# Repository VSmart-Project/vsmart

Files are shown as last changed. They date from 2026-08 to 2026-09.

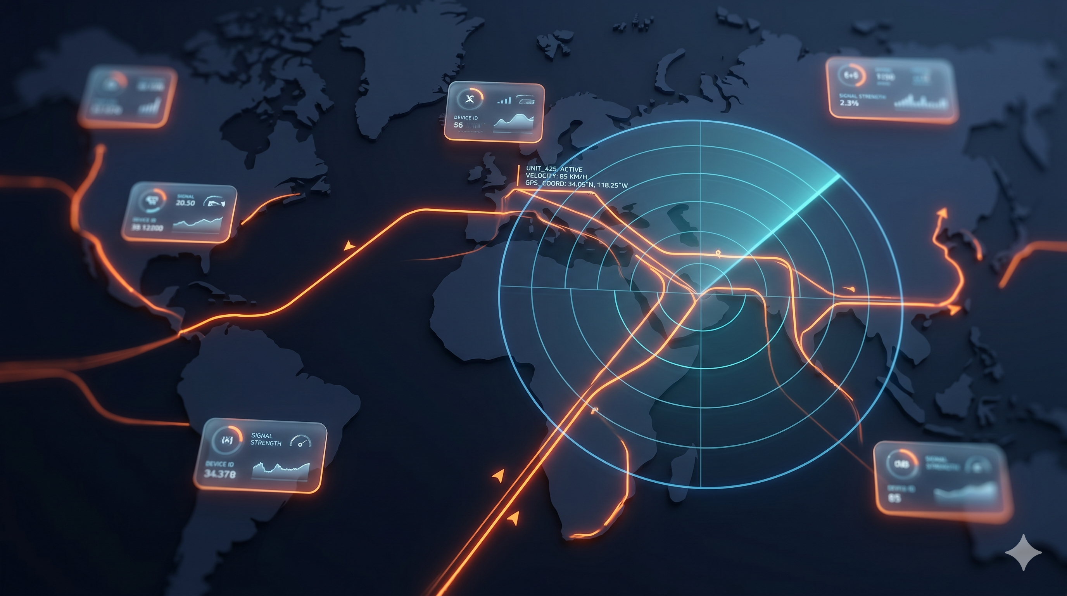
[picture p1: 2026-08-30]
vsmart-mobile/assets/background.png

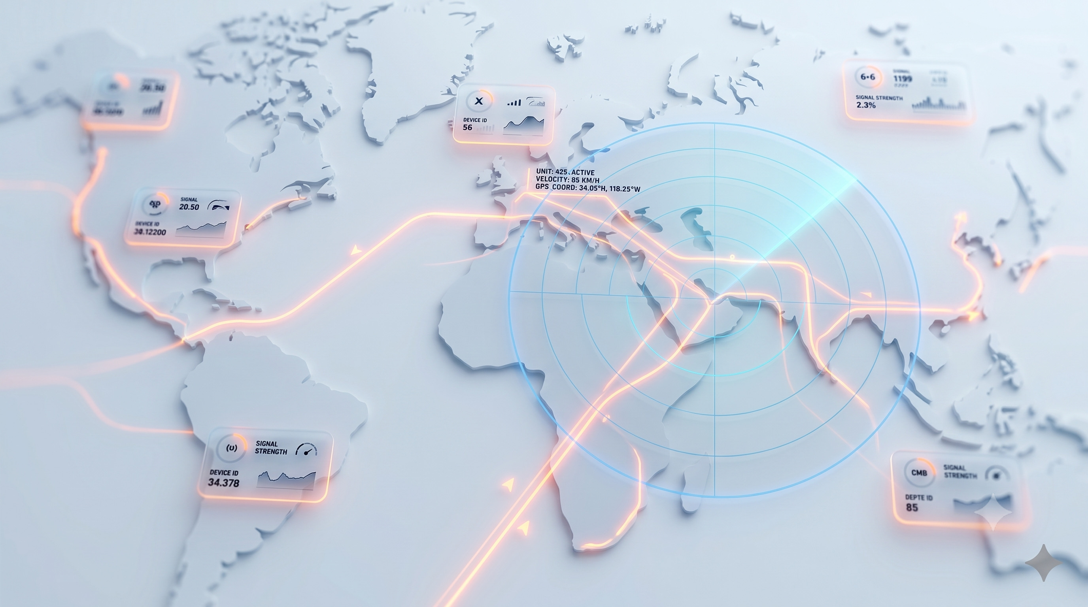
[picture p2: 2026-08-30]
vsmart-web/src/assets/background.png

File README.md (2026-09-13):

# Vsmart — Cloud-based Vehicle GPS Tracking and Management System (IoT)

> **Graduation Project** — Real-time GPS Tracking, Geofencing, Anti-theft protection, and instant intrusion alerts system, built entirely on AWS Serverless Cloud Architecture.

## Quick local start

From the `DATN` directory, start the configured local services with:

```bash
./start-system.sh
```

The script starts the backend (port 3001) and web dashboard (port 5173) by default.
Pass `--with-mobile` if you want to start the Expo mobile app as well.
Use `./start-system.sh --help` to view all available options. Press `Ctrl+C` or run `./stop-system.sh`
to stop all running services. Service logs are retained under `.runtime/logs/`.

---

## Table of Contents

1. [Project Overview](#1-project-overview)
2. [Source Code Directory Structure](#2-source-code-directory-structure)
3. [System Architecture](#3-system-architecture)
4. [AWS Services Utilized](#4-aws-services-utilized)
5. [System Workflows](#5-system-workflows)
6. [Deployment Guide](#6-deployment-guide)
   - [Step 1: System Prerequisites](#step-1-system-prerequisites)
   - [Step 2: Deploy AWS Infrastructure](#step-2-deploy-aws-infrastructure)
   - [Step 3: Configure & Run Backend](#step-3-configure--run-backend)
   - [Step 4: Configure & Run Frontend Web Dashboard](#step-4-configure--run-frontend-web-dashboard)
   - [Step 5: Configure & Run Mobile App](#step-5-configure--run-mobile-app)
   - [Step 6: GPS Simulation & End-to-End Testing](#step-6-gps-simulation--end-to-end-testing)
7. [API Reference](#7-api-reference)
8. [Troubleshooting & FAQ](#8-troubleshooting--faq)
9. [Local-First & ngrok Webhook Workflow](#9-local-first--ngrok-webhook-workflow)
10. [Technology Stack](#10-technology-stack)
11. [References](#11-references)

---

## 1. Project Overview

### Problem Statement

Traditional fleet management systems usually require dedicated physical servers, resulting in high operational costs, maintenance overhead, and poor scalability. The **Vsmart** project solves these issues by leveraging a modern **Serverless Event-Driven Architecture** on AWS, eliminating server management while ensuring high availability, lower latency, and pay-as-you-go cost-efficiency.

### Key Features

| Feature | Description |
|---|---|
| **Real-time GPS Tracking** | Visualizes live vehicle locations on high-performance vector maps |
| **Geofencing** | Custom virtual boundaries (Polygon/Circle) with instant entrance/exit notifications |
| **Anti-theft Security** | Automatic 2-meter radius geofencing around parked vehicles with instant push/email alerts on breach |
| **Multi-platform** | Synchronized Web Dashboard (React) + Mobile App (React Native/Expo) |
| **Identity & Authentication** | Secure user registration/sign-in using Amazon Cognito + JWT verification |
| **Position History** | Replays past vehicle travel routes along a timeline with detailed logs |
| **Serverless & Scalable** | Entire pipeline scale dynamically based on ingestion load, keeping maintenance near zero |
| **Infrastructure as Code (IaC)** | Deploys 30+ AWS resources using a single command via AWS CloudFormation/SAM |

---

## 2. Source Code Directory Structure

The project is structured into **4 independent modules**, enabling isolated development and deployment:

```
7-DATN/
│
├── vsmart-infrastructure/   ← AWS Serverless Infrastructure (IaC)
│   ├── template.yml                             # Primary SAM Template (30+ AWS resources)
│   ├── packaged.yml                             # Packaged Template containing S3 URIs
│   └── lambda/                                  # Serverless Functions (Python 3.12)
│       ├── iot-message-processor/               #   → Parses MQTT packets & updates ALS Tracker
│       ├── geofence-event-consumer/             #   → Processes Geofence breach events from SQS
│       ├── realtime-event-publisher/            #   → Publishes real-time events to clients via IoT Core
│       └── offline-detector/                    #   → Cron job identifying offline devices (every 1min)
│
├── vsmart-backend/          ← Node.js REST API & Socket.io Proxy
│   ├── index.js                                 # Entry point (Express server & Socket.io, port 3001)
│   ├── src/
│   │   ├── config/
│   │   │   ├── aws.js                           #   AWS SDK clients configuration
│   │   │   ├── constants.js                     #   Global constants & thresholds
│   │   │   ├── realtime.js                      #   Real-time telemetry flags
│   │   │   ├── realtimeEventSchema.js           #   Real-time event validations
│   │   │   └── swagger.js                       #   Swagger/OpenAPI UI config
│   │   ├── controllers/
│   │   │   ├── deviceController.js              #   CRUD operations & location metadata merging
│   │   │   ├── authController.js                #   Cognito user auth controller
│   │   │   └── antitheftController.js           #   Anti-theft activation and status
│   │   ├── routes/
│   │   │   ├── devices.js                       #   /api/devices endpoints
│   │   │   ├── auth.js                          #   /api/auth endpoints
│   │   │   └── antitheft.js                     #   /api/antitheft endpoints
│   │   ├── services/
│   │   │   ├── dynamoService.js                 #   DynamoDB wrapper
│   │   │   ├── locationService.js               #   Amazon Location Service wrapper
│   │   │   ├── snsService.js                    #   SNS SMS/Email notifications
│   │   │   ├── antitheftWorker.js               #   Parked vehicle monitor thread (15s interval)
│   │   │   └── geoUtils.js                      #   Distance calculations (Turf.js)
│   │   └── middleware/
│   │       ├── auth.js                          #   Cognito ID Token JWT verifier
│   │       └── errorHandler.js                  #   Global error catcher
│   └── scripts/
│       ├── interactive-move.js                  #   Interactive GPS Simulator (MQTT → IoT Core)
│       ├── move-device.js                       #   Single device route simulator
│       └── backfill-device-owners.js            #   Owner backfill utility script
│
├── vsmart-web/             ← Web Client (React 19 + Vite 8)
│   ├── index.html                               # HTML Entry
│   ├── vite.config.js                           # Vite bundler config (port 5173)
│   ├── tailwind.config.js                       # TailwindCSS styles configuration
│   └── src/
│       ├── App.jsx                              # Router, auth checks, and Socket.io client
│       ├── configuration.js                     # Local AWS config mapping
│       ├── components/
│       │   ├── auth/                            #   Sign-in, sign-up, and confirmation forms
│       │   ├── map/                             #   MapLibre GL map view & draw controllers
│       │   ├── devices/                         #   Vehicle list, details, and forms
│       │   ├── geofences/                       #   Geofencing controls & drawers
│       │   └── layout/                          #   Sidebar and Header layouts
│       ├── hooks/                               #   Custom React hooks (useDeviceManager, etc.)
│       ├── api/                                 #   Fetch-based REST client
│       └── utils/                               #   AWS Identity Pool credentials resolver
│
└── vsmart-mobile/                               ← Mobile Client (React Native + Expo SDK 54)
    ├── app.json                                 # Expo configuration file
    ├── app/                                     # File-based navigation screens
    │   ├── _layout.jsx                          #   Root provider layout
    │   ├── login.jsx                            #   Login screen
    │   ├── onboarding.jsx                       #   Onboarding flow
    │   ├── map.jsx                              #   Full screen map tracking view
    │   ├── scan.jsx                             #   Camera QR/Barcode scanner
    │   └── (tabs)/                              #   Tab navigator (Home, Devices, Settings)
    └── src/
        ├── configuration.js                     #   Mobile AWS configuration constants
        ├── contexts/                            #   Global contexts (DeviceDataContext, etc.)
        └── utils/                               #   Cognito authentication & AWS SDK helpers
```

---

## 3. System Architecture

The system utilizes an **Event-Driven Serverless Ingestion Pipeline** on AWS coupled with a **Node.js WebSockets Proxy** to handle live telemetry feeds with millisecond latency:

```mermaid
%%{init: {'theme': 'base', 'themeVariables': { 'fontFamily': 'Inter, sans-serif', 'fontSize': '13px', 'primaryColor': '#4f46e5', 'primaryTextColor': '#ffffff', 'primaryBorderColor': '#4338ca', 'lineColor': '#64748b', 'secondaryColor': '#f8fafc', 'tertiaryColor': '#ffffff' }}}%%
graph TB
    subgraph Clients ["Client Applications"]
        Web["Web Dashboard (React + Vite)"]
        Mobile["Mobile App (React Native + Expo)"]
    end

    subgraph Backend ["Backend Proxy (Node.js & Express)"]
        Express["Express Server (Port 3001)"]
        SocketServer["Socket.io Server (WebSocket Broker)"]
        AntitheftWorker["Anti-theft Worker (Interval: 15s)"]
    end

    subgraph AWSCloud ["AWS Serverless Cloud Infrastructure"]
        IoTCore["AWS IoT Core (MQTT Broker)"]
        LambdaIngest["Lambda: IoTMessageProcessor"]
        LambdaGeofence["Lambda: GeofenceEventConsumer"]
        LambdaOffline["Lambda: OfflineDetector (Cron: 1min)"]
        
        subgraph Databases ["AWS Databases"]
            DynamoDevices[("DynamoDB: DevicesTable")]
            DynamoState[("DynamoDB: DeviceStateTable")]
        end
        
        subgraph LocationServices ["AWS Location Services"]
            ALSMap["Map: Vsmart-Map"]
            ALSTracker["Tracker: Vsmart-Tracker"]
            ALSCollection["Collection: GeofenceCollection"]
        end
        
        EventBridge["Amazon EventBridge"]
        SQSQueue["Amazon SQS (Geofence Alerts)"]
        SNSTopic["Amazon SNS (Email Alerts)"]
        Cognito["Amazon Cognito (User & Identity Pools)"]
    end

    %% Connections
    Web & Mobile <-->|"1. REST API Requests (Cognito JWT)"| Express
    Web & Mobile <-->|"2. Socket.io WebSockets"| SocketServer
    Web & Mobile -->|"3. Vector Map Tiles Fetch"| ALSMap
    Web & Mobile -->|"4. Credentials Exchange"| Cognito

    %% Ingestion
    Simulator["GPS Device / Simulator"] -->|"5. Publish Location (MQTT)"| IoTCore
    IoTCore -->|"6. Trigger Rule"| LambdaIngest
    
    LambdaIngest -->|"7a. Log coordinate history"| ALSTracker
    LambdaIngest -->|"7b. Save latest state"| DynamoState
    LambdaIngest -->|"7c. HTTP POST Webhook"| Express
    
    %% Geofence Transitions
    ALSTracker -->|"8. Evaluate transitions"| ALSCollection
    ALSCollection -->|"9. ENTER/EXIT Event"| EventBridge
    EventBridge -->|"10. Queue message"| SQSQueue
    SQSQueue -->|"11. Poll batch"| LambdaGeofence
    LambdaGeofence -->|"12. HTTP POST Webhook (Alert)"| Express

    %% Anti-theft Guard
    AntitheftWorker -->|"13. Query coordinates"| DynamoState & ALSTracker
    AntitheftWorker -->|"14. Trigger Alert (Breach)"| SNSTopic

    %% Cron Tasks
    EventBridge -->|"15. Trigger Cron"| LambdaOffline
    LambdaOffline -->|"16. Mark Offline (>120s)"| DynamoState
    LambdaOffline -->|"17. HTTP POST Webhook (Status)"| Express

    %% Webhook forwarding to sockets
    Express -->|"18. Forward event payload"| SocketServer

    %% Styling classes
    style Web fill:#e0f2fe,stroke:#38bdf8,stroke-width:2px,color:#0f172a
    style Mobile fill:#e0f2fe,stroke:#38bdf8,stroke-width:2px,color:#0f172a
    style Express fill:#faf5ff,stroke:#c084fc,stroke-width:2px,color:#0f172a
    style SocketServer fill:#faf5ff,stroke:#c084fc,stroke-width:2px,color:#0f172a
    style AntitheftWorker fill:#faf5ff,stroke:#c084fc,stroke-width:2px,color:#0f172a
    style IoTCore fill:#fff7ed,stroke:#fdba74,stroke-width:2px,color:#0f172a
    style LambdaIngest fill:#fff7ed,stroke:#fdba74,stroke-width:2px,color:#0f172a
    style LambdaGeofence fill:#fff7ed,stroke:#fdba74,stroke-width:2px,color:#0f172a
    style LambdaOffline fill:#fff7ed,stroke:#fdba74,stroke-width:2px,color:#0f172a
    style EventBridge fill:#fff7ed,stroke:#fdba74,stroke-width:2px,color:#0f172a
    style SQSQueue fill:#fff7ed,stroke:#fdba74,stroke-width:2px,color:#0f172a
    style SNSTopic fill:#fff7ed,stroke:#fdba74,stroke-width:2px,color:#0f172a
    style Cognito fill:#fff7ed,stroke:#fdba74,stroke-width:2px,color:#0f172a
    style DynamoDevices fill:#f0fdf4,stroke:#86efac,stroke-width:2px,color:#0f172a
    style DynamoState fill:#f0fdf4,stroke:#86efac,stroke-width:2px,color:#0f172a
    style ALSMap fill:#f0fdfa,stroke:#5eead4,stroke-width:2px,color:#0f172a
    style ALSTracker fill:#f0fdfa,stroke:#5eead4,stroke-width:2px,color:#0f172a
    style ALSCollection fill:#f0fdfa,stroke:#5eead4,stroke-width:2px,color:#0f172a
```

### Architectural Design Principles

| Principle | Description |
|---|---|
| **Separation of Concerns** | Decouples IoT telemetry ingestion from application API layers to prevent system crashes on high device activity. |
| **Event-Driven & Serverless** | Coordinates flow automatically through EventBridge, SQS, and Lambda, providing cost-efficiency and horizontal scaling. |
| **Dual Data Pipeline** | Integrates low-cost NoSQL storage (DynamoDB for metadata) with specialized geo-caching databases (Amazon Location Tracker for spatial coordinates). |
| **WebSockets API Gateway Proxy** | Connects clients via lightweight Socket.io WebSockets instead of direct AWS MQTT. The backend exposes a secure `/api/realtime/event` webhook called by AWS Lambda. |
| **Cognito-Federated Identity** | Uses Amazon Cognito User Pools for authorization. The client exchanges JWT tokens for AWS temporary credentials via Cognito Identity Pools to read map vector tiles directly. |

---

## 4. AWS Services Utilized

### Core Services

| Service | Resource Name | Purpose |
|---|---|---|
| **Amazon Location Service** | `Vsmart-Map` | Renders map vector tiles (Esri Navigation style) |
| | `Vsmart-Tracker` | Caches coordinates history, applies `DistanceBased` filtering |
| | `Vsmart-GeofenceCollection` | Stores geofence boundary coordinates |
| **AWS IoT Core** | Rule: `UpdateLocationTracker` | Receives incoming MQTT telemetry and routes payload to Lambda |
| **Amazon DynamoDB** | `Vsmart-Devices` | Device profiles database (name, license plate, status) |
| | `Vsmart-DeviceState` | Live runtime state database (online flag, last seen timestamp, anti-theft trigger) |
| **Amazon Cognito** | `Vsmart-UserPool` | Secure registration and login gateway |

### Supporting Services

| Service | Resource Name | Purpose |
|---|---|---|
| **AWS Lambda** | `IoTMessageProcessor` | Validates telemetry ➔ updates location ➔ calls Backend Webhook |
| | `GeofenceEventConsumer` | Handles geofence breaches ➔ calls Backend Webhook |
| | `OfflineDetector` | Queries the online-state index and identifies offline vehicles (>120s) |
| **Amazon EventBridge** | `GeofenceEventRule` | Captures geofence breach notifications ➔ routes to SQS |
| | `OfflineDetectorSchedule` | Generates cron triggers every minute |
| **Amazon SQS** | `GeofenceEvents` | Queues geofence breach events for batch consumption |
| **Amazon SNS** | `AntitheftAlerts` | Dispatches warning emails to owners on anti-theft breaches |
| | `IoTErrors` | Emails administrators on processing failures |
| **CloudFormation** | `Vsmart-UnifiedStack` | Deploys the entire backend cloud infrastructure as code |

---

## 5. System Workflows

### A. Location Telemetry Pipeline — GPS → Cloud → Clients

Updates vehicle markers on the map within milliseconds of receiving a new GPS coordinate:

```mermaid
%%{init: {'theme': 'base', 'themeVariables': { 'fontFamily': 'Inter, sans-serif', 'fontSize': '12px', 'primaryColor': '#4f46e5', 'primaryTextColor': '#ffffff', 'lineColor': '#64748b' }}}%%
sequenceDiagram
    autonumber
    participant Device as 🛰️ GPS Device
    participant IoT as 📡 AWS IoT Core
    participant Ingest as ⚡ Lambda: IoTMessageProcessor
    participant ALS as 📍 AWS Location Tracker
    participant Dynamo as 🗄️ DynamoDB (DeviceState)
    participant Backend as 🔧 Backend Express
    participant WebSockets as 🔌 Socket.io Server
    participant UI as 💻 Client Map UI

    Device->>IoT: Publish MQTT payload (location topic)
    IoT->>Ingest: Trigger Lambda with payload
    activate Ingest
    Ingest->>ALS: batch_update_device_position(Coordinates)
    Ingest->>Dynamo: Update state (isOnline=true, lastSeenAt, coordinates)
    Ingest->>Backend: HTTP POST /api/realtime/event (with API Key)
    deactivate Ingest
    activate Backend
    Backend->>WebSockets: Emit 'realtime-event'
    deactivate Backend
    WebSockets-->>UI: Push position data via WebSocket connection
    UI->>UI: Re-render map marker dynamically (smooth translation)
```

---

### B. Device Registration & Retrieval Workflow

Fetches registered devices, resolving metadata and coordinates from distinct databases:

```mermaid
%%{init: {'theme': 'base', 'themeVariables': { 'fontFamily': 'Inter, sans-serif', 'fontSize': '12px', 'primaryColor': '#4f46e5', 'primaryTextColor': '#ffffff', 'lineColor': '#64748b' }}}%%
sequenceDiagram
    autonumber
    participant UI as 💻 Web/Mobile Client
    participant Backend as 🔧 Backend Express
    participant Cognito as 🔐 AWS Cognito
    participant Dynamo as 🗄️ DynamoDB (DevicesTable)
    participant ALS as 📍 AWS Location Tracker

    UI->>Backend: GET /api/devices (Header: Bearer JWT)
    activate Backend
    Backend->>Cognito: Verify JWT signature & expiry
    Cognito-->>Backend: Verification success
    Backend->>Dynamo: Scan/Query device metadata by ownerUserId
    Dynamo-->>Backend: Return metadata (name, plate, type, antitheft)
    Backend->>ALS: ListDevicePositions (Fetch last coordinates)
    ALS-->>Backend: Return positions & timestamps
    Backend->>Backend: Merge metadata & position by deviceId
    Backend->>Backend: Calculate isOnline (sampleTime < 2 mins)
    Backend-->>UI: Return JSON Response
    deactivate Backend
```

---

### C. Geofencing Warning Pipeline

Monitors boundary crossings and alerts clients in real-time:

```mermaid
%%{init: {'theme': 'base', 'themeVariables': { 'fontFamily': 'Inter, sans-serif', 'fontSize': '12px', 'primaryColor': '#4f46e5', 'primaryTextColor': '#ffffff', 'lineColor': '#64748b' }}}%%
sequenceDiagram
    autonumber
    participant UI as 💻 Web Dashboard
    participant Cognito as 🔐 Cognito Identity Pool
    participant ALS as 📍 AWS Location (GeofenceCollection)
    participant EventBridge as 📅 AWS EventBridge
    participant SQS as 📊 Amazon SQS Queue
    participant Consumer as ⚡ Lambda: GeofenceEventConsumer
    participant Backend as 🔧 Backend Express
    participant WebSockets as 🔌 Socket.io Server
    participant AlertUI as 📱 Client App (Toast/Notification)

    UI->>Cognito: Request temporary credentials
    Cognito-->>UI: Return Access & Secret Keys
    UI->>ALS: Direct PUT /geofences (GeoJSON Polygon/Circle)
    Note over ALS: ALS Tracker evaluates coordinates against Geofences
    ALS->>EventBridge: Publish event on ENTER/EXIT transition
    EventBridge->>SQS: Push event to Queue
    SQS->>Consumer: Trigger Lambda with batch of events
    activate Consumer
    Consumer->>Backend: HTTP POST /api/realtime/event (Alert payload)
    deactivate Consumer
    activate Backend
    Backend->>WebSockets: Broadcast alert to user's room
    deactivate Backend
    WebSockets-->>AlertUI: Push geofence alert event
    AlertUI->>AlertUI: Display Toast Alert & Play Alarm Sound
```

---

### D. Anti-theft Protection Workflow

Secures parked vehicles using automated, short-range geofencing:

```mermaid
%%{init: {'theme': 'base', 'themeVariables': { 'fontFamily': 'Inter, sans-serif', 'fontSize': '12px', 'primaryColor': '#4f46e5', 'primaryTextColor': '#ffffff', 'lineColor': '#64748b' }}}%%
sequenceDiagram
    autonumber
    participant UI as 📱 Web/Mobile Client
    participant Backend as 🔧 Backend Express
    participant ALS as 📍 AWS Location (GeofenceCollection)
    participant Dynamo as 🗄️ DynamoDB (DeviceStateTable)
    participant Worker as 🛡️ Anti-theft Worker (Interval: 15s)
    participant SNS as 📬 Amazon SNS
    participant Email as 📧 Owner's Email

    UI->>Backend: POST /api/antitheft/:deviceId/enable
    activate Backend
    Backend->>ALS: Get current position of device
    Backend->>ALS: PutGeofence (Create R=2m circle around coordinates)
    Backend->>Dynamo: Update state (antitheftEnabled = true, geofenceId = ...)
    Backend-->>UI: Return Success
    deactivate Backend

    loop Every 15 seconds
        Worker->>Dynamo: Scan devices where antitheftEnabled == true
        Dynamo-->>Worker: Return target devices
        Worker->>ALS: Get current coordinates
        ALS-->>Worker: Return current coordinates
        Worker->>Worker: Check if distance from anchor coordinates > 2m
        alt Distance > 2 meters (Breach detected!)
            Worker->>SNS: Publish Alert message to topic
            SNS-->>Email: Deliver "WARNING: Vehicle breached protection zone!"
            Worker->>Dynamo: Disable anti-theft (prevent alert spamming)
        end
    end
```

---

### E. Silent Offline Detection Workflow

Automatically detects lost network or GPS connection:

```mermaid
%%{init: {'theme': 'base', 'themeVariables': { 'fontFamily': 'Inter, sans-serif', 'fontSize': '12px', 'primaryColor': '#4f46e5', 'primaryTextColor': '#ffffff', 'lineColor': '#64748b' }}}%%
sequenceDiagram
    autonumber
    participant EventBridge as 📅 EventBridge Cron (rate: 1min)
    participant Detector as ⚡ Lambda: OfflineDetector
    participant Dynamo as 🗄️ DynamoDB (DeviceStateTable)
    participant Backend as 🔧 Backend Express
    participant WebSockets as 🔌 Socket.io Server
    participant UI as 📱 Client App (List View)

    EventBridge->>Detector: Trigger Lambda
    activate Detector
    Detector->>Dynamo: Scan online devices (isOnline == true)
    Dynamo-->>Detector: Return online devices list
    loop Each Device
        Detector->>Detector: Check if (now - lastSeen) > 120 seconds
        alt Threshold exceeded (Offline!)
            Detector->>Dynamo: Update state (isOnline = false, isOnlineStr = "false")
            Detector->>Backend: HTTP POST /api/realtime/event (device.status.offline)
        end
    end
    deactivate Detector
    activate Backend
    Backend->>WebSockets: Broadcast offline status to user room
    deactivate Backend
    WebSockets-->>UI: Push offline event
    UI->>UI: Gray out device icon & mark badge 'offline'
```

---

## 6. Deployment Guide

### Step 1: System Prerequisites

Ensure you have the following installed on your development machine:

| Tool | Version | Description |
|---|---|---|
| **Node.js** | v20+ LTS | JavaScript Runtime for Backend and Frontend |
| **npm** | v10+ | Package manager |
| **AWS CLI** | v2 | Configured with `aws configure` |
| **AWS Account** | — | Requires permissions for: CloudFormation, IAM, Lambda, Location Service, IoT Core, Cognito, DynamoDB, SNS, SQS, EventBridge |
| **ngrok** | Latest | Used to route local Node.js server for AWS Lambda webhooks |

#### Configure AWS CLI

```bash
aws configure
# AWS Access Key ID: AKIA...
# AWS Secret Access Key: ...
# Default region name: ap-southeast-1
# Default output format: json
```

---

### Step 2: Deploy AWS Infrastructure

The AWS Cloud Services are declared as Infrastructure as Code in `template.yml` under `vsmart-infrastructure/`.

#### 2.1. Clone the Repository
```bash
git clone https://github.com/Tracking-Data-Streaming/.github.git
cd 7-DATN
```

#### 2.2. Create an S3 Bucket for Lambda Artifacts
AWS CloudFormation requires a globally unique S3 bucket to package Lambda code before deployment:
```bash
aws s3 mb s3://vsmart-tracking-artifacts-by-tranvix0910 --region ap-southeast-1
```

#### 2.3. Package the Template
Zip the Lambda code, upload it to S3, and generate the template containing absolute S3 URIs:
```bash
cd vsmart-infrastructure
aws cloudformation package \
  --template-file template.yml \
  --s3-bucket vsmart-tracking-artifacts-by-tranvix0910 \
  --output-template-file packaged.yml \
  --region ap-southeast-1
```

#### 2.4. Expose the Local Webhook Port via ngrok
To receive real-time telemetry events from AWS Lambda on your local machine, start an ngrok tunnel pointing to your local Express server (port 3001):
```bash
ngrok http 3001
```
Copy the generated HTTPS Forwarding URL ending with `.dev` (e.g. `https://abc-123.ngrok-free.dev`). Your Webhook URL will be:
`https://abc-123.ngrok-free.dev/api/realtime/event`

#### 2.5. Deploy the Stack
Deploy the CloudFormation template, passing your email and your ngrok webhook URL:
```bash
aws cloudformation deploy \
  --template-file packaged.yml \
  --stack-name Vsmart-UnifiedStack \
  --capabilities CAPABILITY_NAMED_IAM \
  --parameter-overrides AlertEmail="tranvix.work@gmail.com" BackendWebhookUrl="https://aggregate-jelly-president.ngrok-free.dev/api/realtime/event" \
  --region ap-southeast-1
```
*(Replace `https://abc-123.ngrok-free.dev` with your actual active ngrok URL).*

> 💡 **Tip:** If your ngrok URL changes after restarting ngrok, you do **not** need to redeploy the whole CloudFormation stack. You can quickly update the 3 Lambda functions via AWS CLI:
> ```bash
> export NGROK_URL="https://YOUR_NEW_NGROK.ngrok-free.dev/api/realtime/event"
>
> for fn in $(aws lambda list-functions --region ap-southeast-1 --query "Functions[?starts_with(FunctionName, 'Vsmart-UnifiedStack')].FunctionName" --output text); do
>   aws lambda update-function-configuration --function-name "$fn" \
>     --environment "Variables={$(aws lambda get-function-configuration --function-name "$fn" --region ap-southeast-1 --query "Environment.Variables" --output json | jq -r 'to_entries | map("\(.key)=\(.value)") | join(",")' | sed "s|BACKEND_WEBHOOK_URL=[^,]*|BACKEND_WEBHOOK_URL=$NGROK_URL|")}" \
>     --region ap-southeast-1 >/dev/null 2>&1
> done
> ```

#### 2.6. Confirm SNS Subscription
AWS will send a validation email to the configured `AlertEmail`. **Open the email and click "Confirm subscription"** to enable anti-theft emails.

#### 2.7. Extract CloudFormation Outputs
Export the resource IDs needed to configure your client applications:
```bash
aws cloudformation describe-stacks \
  --stack-name Vsmart-UnifiedStack \
  --query "Stacks[0].Outputs" \
  --output table \
  --region ap-southeast-1
```

#### 2.8. Create Location Service API Key (Mandatory)
AWS Location Service maps require an API key for map rendering, which must be created manually:

```bash
ACCOUNT_ID=$(aws sts get-caller-identity --query Account --output text)

aws location create-key \
  --key-name Vsmart-MapApiKey \
  --restrictions "{
    \"AllowActions\": [\"geo:GetMapStyleDescriptor\",\"geo:GetMapGlyphs\",\"geo:GetMapSprites\",\"geo:GetMapTile\"],
    \"AllowResources\": [\"arn:aws:geo:ap-southeast-1:${ACCOUNT_ID}:map/Vsmart-Map\"]
  }" \
  --no-expiry \
  --region ap-southeast-1 \
  --query "Key" --output text
```

---

### Step 3: Configure & Run Backend

#### 3.1. Install Dependencies
```bash
cd ../vsmart-backend
npm install
```

#### 3.2. Configure Environment Variables (`.env`)
```bash
cp .env.example .env
```
Open `.env` and fill in the output parameters:
```env
PORT=3001
NODE_ENV=development
AWS_REGION=ap-southeast-1
AWS_PROFILE=default # Local development only; use an IAM role in production
DYNAMODB_DEVICES_TABLE=Vsmart-Devices
LOCATION_TRACKER_NAME=Vsmart-Tracker
LOCATION_GEOFENCE_COLLECTION=Vsmart-GeofenceCollection
SNS_ANTITHEFT_TOPIC_ARN=arn:aws:sns:ap-southeast-1:xxxxxx:Vsmart-AntitheftAlerts
CORS_ORIGIN=*
COGNITO_USER_POOL_ID=ap-southeast-1_xxxxxx
COGNITO_CLIENT_ID=xxxxxx
REALTIME_WEBHOOK_KEY=vsmart_secret_telemetry_key
```

#### 3.3. Start the Server
```bash
npm start
```
*Successful log:* `🔌 Realtime: Socket.io server integrated and running`

---

### Step 4: Configure & Run Frontend Web Dashboard

#### 4.1. Install Dependencies
```bash
cd ../vsmart-web
npm install
```

#### 4.2. Configure Environment Variables (`.env`)
```bash
cp .env.example .env
```
Fill in the parameters in `.env`:
```env
VITE_BACKEND_URL=http://localhost:3001
VITE_AWS_REGION=ap-southeast-1
VITE_USER_POOL_ID=ap-southeast-1_xxxxxx
VITE_USER_POOL_CLIENT_ID=xxxxxx
VITE_MAP_API_KEY=v1.public.eyJ... # Map API Key generated in step 2.8
VITE_MAP_STYLE=Standard
VITE_MAP_COLOR_SCHEME=Light
VITE_GEOFENCE_COLLECTION=Vsmart-GeofenceCollection
```

#### 4.3. Start the Web App
```bash
npm run dev
```
Open `http://localhost:5173` on your browser.

---

### Step 5: Configure & Run Mobile App

#### 5.1. Install Dependencies
```bash
cd ../vsmart-mobile
npm install
```

#### 5.2. Configure Settings
Copy `.env.example` to `.env` and point the app to the backend (use a LAN URL for local devices and HTTPS for production):
```env
EXPO_PUBLIC_BACKEND_URL=http://192.168.1.xxx:3001
EXPO_PUBLIC_AWS_REGION=ap-southeast-1
EXPO_PUBLIC_USER_POOL_ID=ap-southeast-1_xxxxxx
EXPO_PUBLIC_USER_POOL_CLIENT_ID=xxxxxx
```

#### 5.3. Start the App
```bash
npm start
```
Scan the QR Code with the **Expo Go** application on your smartphone (connected to the same WiFi LAN).

---

### Step 6: GPS Simulation & End-to-End Testing

#### 6.1. Start the Simulator
Open a new terminal window inside `vsmart-backend` and run:
```bash
node scripts/interactive-move.js
```
#### 6.2. Simulate Route Movement
Type the following command at the prompt `📍 Command >` to begin sending GPS coordinate packages:
```bash
auto 10.8481 106.7864 30
```
On your browser, you will observe the vehicle marker moving smoothly on the map in real-time (2-second intervals).

---

## 7. API Reference

### Auth Endpoints (Public)

| Method | Endpoint | Description |
|---|---|---|
| `POST` | `/api/auth/register` | Signs up a new account (email & password) |
| `POST` | `/api/auth/confirm` | Confirms registration using OTP verification |
| `POST` | `/api/auth/login` | Authenticates user and returns JWT |
| `POST` | `/api/auth/resend-code` | Re-sends the verification code |

### Device Endpoints (Protected)

| Method | Endpoint | Description |
|---|---|---|
| `GET` | `/api/devices` | Returns registered device list merged with positions |
| `GET` | `/api/devices/:id` | Returns metadata details for a specific device |
| `GET` | `/api/devices/:id/history` | Returns coordinate path history for timeline routing |
| `POST` | `/api/devices` | Registers a new device |
| `PUT` | `/api/devices/:id` | Updates device metadata |
| `DELETE` | `/api/devices/:id` | Deletes a device and clear tracker logs |

### Anti-theft Endpoints (Protected)

| Method | Endpoint | Description |
|---|---|---|
| `POST` | `/api/antitheft/:deviceId/enable` | Activates protection (creates R=2m geofence) |
| `POST` | `/api/antitheft/:deviceId/disable` | Deactivates anti-theft (removes geofence) |

### Webhook & Diagnostics

| Method | Endpoint | Description |
|---|---|---|
| `POST` | `/api/realtime/event` | Endpoint receiving Lambda webhook signals (API Key protected) |
| `GET` | `/health` | Informs backend health status and active configuration |
| `GET` | `/api-docs` | Interactive Swagger API documentation |

---

## 8. Troubleshooting & FAQ

#### Lambda error: `Float types are not supported` in CloudWatch
* **Cause**: DynamoDB does not support native Python `float` types.
* **Solution**: The code has been updated to automatically cast floats to `decimal.Decimal` before saving coordinates in DynamoDB (`DeviceStateTable`).

#### Webhook errors: `HTTP Error 404: Not Found`
* **Cause**: Typo in the `BackendWebhookUrl` parameter or ngrok tunnel pointing to incorrect port.
* **Solution**: Ensure your ngrok tunnel is up and ends with `.dev`. Run `aws lambda get-function-configuration` to confirm `BACKEND_WEBHOOK_URL` matches your tunnel url exactly.

#### Map is blank or fails to load style
* **Cause**: Map API Key is incorrect, expired, or has improper resource constraints.
* **Solution**: Double-check `VITE_MAP_API_KEY` matches the key created in Step 2.8. Ensure the key restrictions grant allow actions on the map resource `Vsmart-Map`.

---

## 9. Local-First & ngrok Webhook Workflow

The entire system is designed to run **100% locally on your development machine** without requiring external cloud app hosts or VPS.

### 9.1. Local-First Architecture

```
[ GPS Device / Simulator ] ──► [ AWS IoT Core ] ──► [ AWS Lambda ]
                                                          │
                                                (Webhook via ngrok)
                                                          │
                                                          ▼
[ Local Browser / Mobile ] ◄─── [ Socket.io ] ◄─── [ Local Express (Port 3001) ]
```

1. **Local Express Server (Port 3001)**: Handles all REST API requests, database queries, and WebSocket broadcasting.
2. **ngrok Tunnel**: Creates a secure public tunnel to route AWS Lambda webhook calls back to your machine.
3. **Local Web App (Port 5173)**: Connects directly to `http://localhost:3001`.
4. **Local Mobile App (Port 8081)**: Connects to your computer's LAN IP (e.g. `http://192.168.1.x:3001`).

### 9.2. Daily Local Development Workflow

1. **Start ngrok (Tab 1):**
   ```bash
   ngrok http 3001
   ```
2. **Start the local services (Tab 2):**
   ```bash
   ./start-system.sh
   ```
3. **Run GPS Simulation (Tab 3):**
   ```bash
   cd vsmart-backend
   node scripts/interactive-move.js
   ```
4. **Stop everything when finished:**
   ```bash
   ./stop-system.sh
   # Or press Ctrl+C in Tab 2
   ```

---

## 10. Technology Stack

### Frontend & Mobile
* **React 19.2** & **Vite 8.0**
* **React Native v0.81** & **Expo SDK 54**
* **MapLibre GL JS** (Vector Tiles Rendering)
* **Tailwind CSS** (Utility-first Styling)
* **AWS Amplify (Auth v6)**
* **Socket.io Client** (WebSocket Telemetry)

### Backend Services
* **Node.js v20** & **Express.js**
* **Socket.io Server**
* **AWS SDK for JS (v3)**
* **Swagger OpenAPI UI**

### Cloud Infrastructure
* **AWS CloudFormation / SAM**
* **Amazon Location Service (Maps, Tracker, Geofences)**
* **AWS IoT Core**
* **Amazon DynamoDB**
* **Amazon EventBridge & SQS & SNS**

---

## 11. References

* [Amazon Location Service Developer Guide](https://docs.aws.amazon.com/location/)
* [AWS IoT Core Developer Guide](https://docs.aws.amazon.com/iot/)
* [Socket.io Official Documentation](https://socket.io/docs/v4/)
* [Expo Router Navigation Guidelines](https://docs.expo.dev/router/introduction/)

---

## LICENSE
This project is licensed under the **MIT License** — see the [LICENSE](LICENSE) file for details.

---

## Thesis Metadata

| Parameter | Detail |
|---|---|
| **Thesis Title** | Cloud-based IoT Fleet Management and Real-time Tracking System |
| **Academic Level** | Graduation Thesis (Bachelor of Engineering) |
| **Architecture** | Serverless Ingestion + Node.js WebSockets Proxy |
| **Cloud Provider** | Amazon Web Services (AWS) |
| **Default Region** | `ap-southeast-1` (Singapore) |

---
<div align="center">
  <b>Happy Tracking!</b>
</div>

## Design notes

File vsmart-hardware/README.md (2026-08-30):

# VSmart ESP32-S3 SuperMini Module Carrier

Carrier PCB 2 lớp mới cho các module cắm/rút:

- ESP32-S3 SuperMini 18 chân, kích thước danh nghĩa khoảng 18.2 × 23.2 mm
- MPU6050 GY-521
- **GPS GY-GPSU3-NEO (NEO-7M, 4 chân VCC/RX/TX/GND, ăng-ten gốm rời qua cáp u.FL)**
- A7680C TDM2309 / TDM-4G-V1

PCB có kích thước **74 × 62 mm**, bo góc 3 mm và bốn lỗ bắt vít M3. Mạch hạ áp được đặt bên ngoài; carrier chỉ nhận 5 V và 4 V đã ổn áp qua hai đầu hàn dây.

## Module GPS GY-GPSU3-NEO

Thay cho Keyestudio KS0319 (footprint 55 × 27 mm), module này chỉ chiếm khoảng
**25 × 25 mm** nên PCB giảm được từ 96 × 76 mm xuống 74 × 62 mm (−34 % diện tích).

- Header 1×4 bước 2.54 mm, thứ tự **VCC – RX – TX – GND** đúng như in trên module.
- Ăng-ten gốm nằm rời, nối bằng cáp u.FL, nên module GPS **không cần đặt sát mép
  PCB**; chỉ cần đặt tấm ăng-ten hướng lên trời khi lắp vỏ.
- Không còn chân PPS: net `GPS_PPS` đã bị xoá khỏi schematic và **GPIO11 của
  ESP32-S3 giờ để trống** (đã đánh dấu no-connect).
- Footprint `VSmart_Modules:GY-GPSU3-NEO7M` chỉ ràng buộc bằng 4 lỗ header;
  đường bao 25 × 25 mm là **kích thước danh nghĩa**, chưa có lỗ bắt vít cho module.
  Bắt buộc in PDF 1:1 và đặt module thật lên để đối chiếu trước khi đặt PCB.

## Lắp ESP32-S3 SuperMini

Footprint U1 dùng hai hàng 9 chân, bước chân 2.54 mm, khoảng cách hai hàng 15.24 mm. Lỗ khoan 1.0 mm, pad 1.8 mm phù hợp với pin header/socket header 2.54 mm thông dụng.

Nên hàn hai socket cái 1×9 lên carrier để có thể cắm/rút ESP32-S3. Đối chiếu đúng đầu USB, pin TX/RX và dấu pad vuông trước khi cấp nguồn. Vùng giữa hai hàng chân ở đầu anten được cấm trace, via và copper pour trên cả hai lớp.

## Đầu nối nguồn

| Đầu nối | Pad vuông số 1 | Pad tròn số 2 | Chức năng |
|---|---|---|---|
| J1 | +5V | GND | Cấp cho ESP32-S3, GPS, MPU6050 và C3 |
| J2 | +4V_SIM | GND | Cấp riêng cho A7680C và C1 |

J1/J2 có lỗ khoan 1.4 mm, pad ngoài 2.7 mm, bước 5.4 mm; có thể hàn trực tiếp dây khoảng 0.5–1.0 mm². Nhánh 4V_SIM cần dây ngắn, tiết diện đủ lớn.

## Yêu cầu nguồn

- Chỉnh LM2596 cấp J1 chính xác 5.0 V trước khi kết nối.
- Chỉnh bộ hạ áp cấp J2 khoảng 4.0 V; tuyệt đối không đưa 5 V hoặc 12 V vào A7680C.
- Nguồn 4V_SIM phải chịu được dòng xung lớn của modem và không sụt áp khi phát sóng.
- C1 1000 µF low-ESR lọc nhánh 4V_SIM; C3 470 µF lọc nhánh 5 V.
- **Không có tụ gốm 100 nF trên carrier.** Module A7680C TDM2309 đã có tụ lọc
  cao tần riêng ngay tại chân nguồn của con chip trên board module. Nếu khi chạy
  thực tế modem bị reset lúc phát sóng, hàn thêm một tụ gốm 104 (100 nF, chân cắm)
  **trực tiếp lên hai chân VCC–GND của header module A7680C** — đó mới là vị trí
  có tác dụng, và hàn ở đó dễ hơn hàn trên carrier.
- Hai bộ hạ áp và carrier phải dùng chung GND.
- Tránh cấp đồng thời 5 V từ J1 và USB-C của ESP32-S3 nếu chưa xác minh mạch bảo vệ/chống cấp ngược của module đang dùng.

## Ánh xạ tín hiệu ESP32-S3

| Module | Chân module | Net | Chân ESP32-S3 SuperMini |
|---|---|---|---|
| MPU6050 | SDA | I2C_SDA | GPIO8 |
| MPU6050 | SCL | I2C_SCL | GPIO9 |
| MPU6050 | INT | MPU_INT | GPIO10 |
| MPU6050 | AD0 | GND | GND |
| GPS | TXD | GPS_RX | RX |
| GPS | RXD | GPS_TX | TX |
| GPS | PPS | GPS_PPS | GPIO11 |
| A7680C | TXD | SIM_RX | GPIO6 |
| A7680C | RXD | SIM_TX | GPIO7 |
| A7680C | RST | SIM_RST | GPIO12 |
| A7680C | RI | SIM_RI | GPIO13 |
| A7680C | DTR | SIM_DTR | GPIO11 |

GPIO1, GPIO2, GPIO3, GPIO4 và GPIO5 được đánh dấu không sử dụng trong schematic. (SIM_DTR đã chuyển từ GPIO4 sang GPIO11 để đường đi trên PCB không phải cắt qua vùng cấm ăng-ten ESP32-S3.) UART GPS dùng cặp TX/RX được in trực tiếp trên module; UART modem dùng GPIO6/GPIO7.

## Luật PCB

- +4V_SIM: trace 2.0 mm
- +5V và GND: trace 1.0 mm
- +3V3: trace 0.5 mm
- UART/I²C/tín hiệu điều khiển: trace 0.25 mm
- Ground plane F.Cu và B.Cu
- 135 via stitching GND (lưới 5 mm + via hồi dòng cạnh via tín hiệu)
- Keep-out anten ESP32-S3 trên F.Cu và B.Cu
- 4 lỗ M3, đường kính khoan 3.2 mm

## Kiểm tra cơ khí bắt buộc

Footprint GPS KS0319, MPU6050 và A7680C được dựng theo module mẫu/thư viện đã cung cấp. Các module bán trên thị trường có thể khác kích thước, vị trí header, chiều linh kiện hoặc vị trí lỗ bắt vít. Trước khi đặt PCB số lượng lớn:

1. In PDF PCB đúng tỉ lệ 1:1.
2. Đặt module thật và socket header lên bản in.
3. Kiểm tra chiều pin, khoảng cách hàng chân, đầu USB, anten và chiều cao linh kiện.
4. Đo lại điện áp 5 V và 4 V trước khi cắm module.

## Kết quả kiểm tra (bản 74 × 62 mm, GY-GPSU3)

- Schematic: **ERC 0 lỗi**, 1 cảnh báo cache thư viện của symbol ESP32-S3 tùy chỉnh.
- PCB: **DRC 0 lỗi, 0 pad chưa nối**. Còn 16 cảnh báo silkscreen/cỡ chữ của các
  footprint module tự vẽ (không ảnh hưởng mạch).
- Đã bỏ C2 (tụ gốm 0805) — xem mục Yêu cầu nguồn.
- **Đã route đầy đủ 14 net**: `GND` (đổ đồng 2 mặt), `+5V` 1.0 mm,
  `+3V3` 0.3–0.4 mm, `+4V_SIM` 2.0 mm, và 10 net tín hiệu 0.25 mm.
- 12 via nhảy lớp cho các đường buộc phải cắt nhau.
- **140 via khâu GND** (lưới 5 mm + 6 via hồi dòng đặt cạnh via tín hiệu) — tổng 145 via.

### Ghi chú từ design review (kicad-happy v2.2.0)

- Mặt phẳng GND liền một khối duy nhất (`connectivity_graph`: GND = 1 island, 0 gap).
- EMC risk score **70/100** (FCC Part 15 Class B và CISPR 32 Class B cho cùng
  kết quả). `RP-001` đường hồi dòng: đã xử lý 3/4 net, còn `MPU_INT` (2 via)
  không đặt được via GND kề vì khe đồng quá hẹp.
- Cảnh báo `GP-001` còn lại: 9 net có độ phủ mặt phẳng tham chiếu 55–95 %
  (thấp nhất `SIM_TX` 55 %). Đây là hệ quả của việc dồn nhiều làn tín hiệu
  song song xuống mặt dưới. **Không xử lý** vì tất cả đều là tín hiệu chậm
  (UART/I²C, analyzer đánh dấu `is_high_speed_or_clock: false`); rủi ro thực
  tế thấp. Nếu sau này chạy UART modem ở baud rất cao thì nên đi lại dây.
- **Chưa xác minh: mức logic UART của module A7680C TDM2309.** Dòng SIMCom
  A76xx thường dùng UART 1.8 V. Nếu module không có mạch dịch mức on-board,
  chân TX 3.3 V của ESP32-S3 có thể làm hỏng modem. Phải tra tài liệu module
  trước khi cấp nguồn lần đầu.

### Chiến lược đi dây

- **F.Cu**: nguồn `+5V`, `+4V_SIM`, `+3V3`, cùng `I2C_SDA`/`I2C_SCL` chạy dọc
  mép trái xuống MPU6050.
- **B.Cu**: `GPS_TX`/`GPS_RX` sang GPS, và 5 net `SIM_*` sang A7680C, chạy theo
  các làn ngang song song ở dải y = 57–73 mm.
- Các đường cắt qua hàng chân ESP32-S3 đều luồn đúng khe giữa hai pad
  (bước 2.54 mm, khe hở 0.74 mm), trace 0.25 mm, clearance 0.2 mm.
- Không có trace/via nào nằm trong vùng cấm ăng-ten ESP32-S3.

### Lỗi đã sửa trong bước này

- Bốn pad của ESP32-S3 bị gán sai net khi import netlist: GPIO1 và GPIO2 bị nối
  vào `+3V3` (chập GPIO với nguồn 3.3 V), GPIO5 và GPIO11 còn dính `GPS_PPS`,
  trong khi chân `3V3_OUT` lại **không** có net. Đã gán lại đúng toàn bộ 18 pad.
- Xoá 6 đoạn trace trùng lặp/đầu hở còn sót từ lần import file autoroute.
- Toàn bộ trace cũ rộng 0.2 mm (kể cả `+4V_SIM` cấp cho modem 4G) — đã đi lại
  nguồn theo đúng bề rộng quy định.
- Phục hồi hai mặt đổ đồng GND (bản 86 × 70 mm trước đó đã mất sạch ground plane).
- `MountingHole:MountingHole_3.2mm` không tồn tại trong thư viện KiCad
  (tên đúng là `MountingHole_3.2mm_M3`) — đã thay, 4 lỗ M3 nay resolve được.
- Chữ `ANT KEEP-OUT` ở mặt dưới chưa mirror (in ngược) — đã sửa; các chữ silk
  nhỏ hơn 0.8 mm đã tăng lên 0.9 mm.

File chế tạo trong `manufacturing/` (Gerber + Excellon + pick-and-place + BOM,
đã nén sẵn `vsmart-module-esp32-s3-mini-fab.zip`); PDF sơ đồ và PDF PCB trong `reports/`.

## Rev B — trạng thái gia công (2026-08-30)

Đổi từ Rev A: `U4` 4.0 V → **5 V 2 A**, `U3` 5 V → **3.3 V**, `C1` 6.3 V → **16 V**,
silk thêm dòng định mức `+5V 1A` (J1) / `+5V 2A` (J2). **Rev A không dùng nữa.**

| Kiểm tra | Kết quả |
|---|---|
| DRC (`kicad-cli` 10.0.5, severity-all) | **0 vi phạm** |
| Pad chưa nối / đối chiếu schematic ↔ PCB | **0 / 0** |
| Bộ gerber (`analyze_gerbers`) | **0 phát hiện**, đủ 7/7 lớp |
| EMC risk score | 70/100 |
| Kích thước · via · lỗ | 74.1 × 62.1 mm · 146 via · 196 PTH + 5 NPTH |

Nộp xưởng: `manufacturing/vsmart-module-esp32-s3-mini-fab.zip` (10 file phẳng).

### Trước khi cấp nguồn — hai việc phải tự đo

1. **Mức logic UART của A7680C.** Cấp nguồn module rời, đo chân TXD lúc rảnh.
   ~3.3 V → nối thẳng. ~1.8 V → chừa trống RXD/TXD, đấu qua module dịch mức.
2. **LDO 3.3 V trên SuperMini.** GPS nay ăn từ chân 3V3 của U1; tổng đỉnh ~420 mA
   nếu bật WiFi. ME6211 (500 mA) đủ, bản clone 200 mA thì không.

### Trước khi đặt board

In `manufacturing/CHECK-1to1-footprints.pdf` ở **100 %**, đặt U1–U4 thật lên giấy.
Footprint U3 và U4 vẽ theo kích thước danh nghĩa, chưa đo trên hàng thật.

### Cấp nguồn

`J1` = 5 V/1 A (ESP32), `J2` = 5 V/2.5 A (SIM). **Cấp riêng.** Một nguồn ≥ 3 A thì
kéo hai cặp dây riêng, đấu hình sao tại nguồn. Đừng câu J2 ăn theo cọc của J1.

Báo cáo review đầy đủ: https://claude.ai/code/artifact/87cbf2e2-2273-45b7-b7cd-e9a7c37d8165

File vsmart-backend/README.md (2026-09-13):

# vsmart-backend

REST API backend cho hệ thống Vsmart - Quản lý CRUD Devices.

## Kiến trúc

```
React Frontend
      ↕ REST API (port 3001)
  Express Backend   ← vsmart-backend
      ↕
  DynamoDB: Vsmart-Devices  ← metadata device
      +
  AWS Location Service Tracker    ← vị trí thực tế
```

## Cấu trúc thư mục

```
vsmart-backend/
├── src/
│   ├── config/
│   │   ├── aws.js           # AWS SDK clients (DynamoDB, Location)
│   │   └── constants.js     # Tên bảng, tracker, enums
│   ├── controllers/
│   │   └── deviceController.js  # Business logic (CRUD handlers)
│   ├── routes/
│   │   └── devices.js       # Express routes
│   ├── services/
│   │   ├── dynamoService.js     # Thao tác DynamoDB
│   │   └── locationService.js   # AWS Location Service
│   └── middleware/
│       └── errorHandler.js  # Global error handler
├── cloudformation/
│   └── devices-table.yaml   # CloudFormation template DynamoDB
├── .env                     # Environment variables (KHÔNG commit)
├── .env.example             # Template env vars
└── index.js                 # Entry point
```

## Bước 1: Tạo DynamoDB Table

### Option A: CloudFormation (khuyến nghị)
```bash
aws cloudformation deploy \
  --template-file cloudformation/devices-table.yaml \
  --stack-name Vsmart-DevicesTable \
  --region us-east-1
```

### Option B: AWS CLI
```bash
aws dynamodb create-table \
  --table-name Vsmart-Devices \
  --attribute-definitions AttributeName=deviceId,AttributeType=S \
  --key-schema AttributeName=deviceId,KeyType=HASH \
  --billing-mode PAY_PER_REQUEST \
  --region us-east-1
```

## Bước 2: Cấu hình credentials

Copy `.env.example` thành `.env` và điền thông tin:

```bash
cp .env.example .env
```

```env
PORT=3001
NODE_ENV=development

AWS_REGION=us-east-1
AWS_PROFILE=default             # Chỉ dùng cho local; production dùng IAM role

DYNAMODB_DEVICES_TABLE=Vsmart-Devices
LOCATION_TRACKER_NAME=Vsmart-Tracker
LOCATION_GEOFENCE_COLLECTION=Vsmart-GeofenceCollection
REALTIME_WEBHOOK_KEY=<chuỗi bí mật tối thiểu 32 ký tự từ Secrets Manager>

CORS_ORIGIN=http://localhost:5173
```

> **IAM Permissions cần thiết:**
> - `dynamodb:GetItem`, `PutItem`, `UpdateItem`, `DeleteItem`, `Query` (table `Vsmart-Devices` và GSI)
> - `geo:ListDevicePositions`, `geo:GetDevicePositionHistory`, `geo:BatchDeleteDevicePositionHistory` (tracker)
> - `geo:ListGeofences`, `geo:GetGeofence`, `geo:PutGeofence`, `geo:BatchDeleteGeofence` (geofence collection)

## Bước 3: Chạy server

```bash
# Development (auto-reload)
npm run dev

# Production
npm start
```

## API Endpoints

| Method | Path | Mô tả |
|---|---|---|
| GET | `/health` | Health check |
| GET | `/api/devices` | Lấy tất cả devices (merge vị trí từ Tracker) |
| GET | `/api/devices/:id`  | Chi tiết một device |
| POST | `/api/devices` | Tạo device mới |
| PUT | `/api/devices/:id`  | Cập nhật metadata (displayName, type, status, ...)  |
| DELETE | `/api/devices/:id`  | Xóa device (DynamoDB + lịch sử Tracker) |

### POST /api/devices — Body
```json
{
  "deviceId": "Vehicle-001",
  "displayName": "Xe tải số 1",
  "type": "truck",
  "licensePlate": "51A-12345",
  "status": "active",
  "description": "Xe tải chở hàng tuyến HN-HCM"
}
```

### GET /api/devices — Response
```json
{
  "success": true,
  "total": 2,
  "data": [
    {
      "deviceId": "Vehicle-001",
      "displayName": "Xe tải số 1",
      "type": "truck",
      "licensePlate": "51A-12345",
      "status": "active",
      "description": "...",
      "createdAt": "2026-04-20T11:49:00Z",
      "updatedAt": "2026-04-20T11:49:00Z",
      "position": [105.804, 21.028],
      "sampleTime": "2026-04-20T11:55:00Z",
      "isOnline": true
    }
  ],
  "unregistered": [
    {
      "deviceId": "Unknown-Device-XYZ",
      "position": [105.8, 21.0],
      "isRegistered": false
    }
  ]
}
```

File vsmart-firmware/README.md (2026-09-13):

# Vsmart firmware — GPS-only

Phần cứng hiện dùng: ESP32 + GPS. Firmware đọc GPS liên tục qua UART và gửi vị trí qua Wi-Fi/TLS tới AWS IoT. A7680C, MPU6050 và bộ đệm offline nằm trong `attic/`, chưa được tích hợp.

## Build và nạp

```sh
pio run -e devkitc
pio run -e s3mini
pio run -e devkitc-altpins

# Khi muốn nạp board DevKitC đang nối USB:
pio run -e devkitc -t upload -t monitor
```

Wi-Fi, endpoint, device ID và chứng chỉ dùng cấu hình hiện có trong `include/secrets.h`. Không chia sẻ file này. Cổng mặc định của DevKitC là `/dev/cu.usbserial-0001`; sửa `platformio.ini` nếu cổng thực tế khác.

| Môi trường | GPS TXD → ESP RX | GPS RXD ← ESP TX |
|---|---|---|
| devkitc | GPIO16 | GPIO17 |
| devkitc-altpins, chỉ khi đi jumper | GPIO18 | GPIO19 |
| s3mini | GPIO44 | GPIO43 |

Theo PCB carrier hiện tại, U3.1 là +3V3, U3.4 là GND. Không thay đổi bảng chân theo chân của project màn hình `ESP32_OSM_NAV`.

## Đọc và kiểm tra GPS

- Task `gps-reader` chạy trước khi kết nối mạng; UART RX buffer 4096 byte. Mạng có thể chờ kết nối mà không dừng parser.
- Task và vòng lặp chính trao đổi bằng snapshot có mutex; không chia sẻ con trỏ vào parser/string đang thay đổi.
- Chỉ dùng frame NMEA nguyên vẹn, đúng checksum. Parser GGA/RMC/GSA/GSV hỗ trợ talker 2 ký tự; TinyGPSPlus chỉ còn dùng phép tính khoảng cách tiện ích, không quyết định validity.
- Dò baud 9600, 38400, 115200, 57600, 19200, 4800; ưu tiên baud trong bảng board. Nếu 30 s không có frame đúng checksum, tự dò lại.
- Fix phải có GGA hợp lệ, tọa độ trong phạm vi, ≥4 vệ tinh, HDOP ≤5, tuổi ≤5 s. RMC invalid hoặc GSA cùng talker báo không có solution chặn tọa độ cũ ngay khi nhận được.
- GSV chỉ được công bố khi nhận đủ nhóm, tổng hợp các chòm và loại trùng vệ tinh giữa các signal band. GSA/GSV hết hạn sau 10 s. `gsvFresh=false` nghĩa là chưa có thống kê hiện tại, không phải bằng chứng anten hỏng.
- `passed`/`failed` là số frame checksum hợp lệ/lỗi định dạng hoặc checksum; `nmea` là số ký tự UART. `snr` trong health là C/N0, đơn vị dB-Hz.

Cấu hình `GPS_ECHO_NMEA=1` để in từng frame đã qua checksum thành một dòng `[nmea]`. Log lỗi vẫn được đếm trong `failed`; khi chưa đạt chất lượng, raw GGA gần nhất được in định kỳ.

## Chính sách gửi trong giai đoạn thử GPS

Mỗi 3 s (`PUBLISH_TICK_MS`), gửi **tọa độ đo hiện tại** nếu đạt chất lượng, kể cả xe đang đứng yên. Không còn bộ lọc 30 m hoặc yêu cầu tốc độ tối thiểu để gửi. Không thay tọa độ mới bằng tọa độ cũ trên heartbeat. Tốc độ dưới 1.5 km/h chỉ được làm tròn về 0 để hiển thị; không ngăn cập nhật vị trí.

Topic `location`, envelope giữ tương thích Lambda:

```json
{"payload":{"deviceid":"your-device-id","timestamp":1789214400,"location":{"lat":10.8,"long":106.8},"accuracy":{"Horizontal":5.0},"positionProperties":{"speed":"9.26","heading":"90.0","status":"moving","reason":"sample"}}}
```

Chỉ có tối đa 4 `positionProperties`. HDOP dùng cùng mẫu GGA với quality gate; `accuracy.Horizontal = HDOP × 5` là ước lượng thô, không phải độ chính xác được GPS chứng nhận. Diagnostics chi tiết gửi riêng trên health.

Timestamp dùng GPS UTC cùng epoch GGA/RMC, còn mới. Nếu lệch đồng hồ hệ thống hợp lệ quá 30 s, dùng thời gian hệ thống trừ tuổi fix. Không gửi vị trí với timestamp 0. Nếu NTP chưa hoạt động nhưng GPS đã có fix/ngày giờ hợp lệ, Cloud có thể khởi tạo đồng hồ từ GPS để thực hiện TLS; không tắt kiểm tra chứng chỉ.

Khi mất Wi-Fi, GPS vẫn đọc; mạng thử lại có backoff 15 s sau mỗi lần thất bại, không reboot chỉ vì mất mạng. Chưa có hàng đợi offline: các mẫu không gửi được không được phát lại sau này. `sent` chỉ xác nhận MQTT client đã ghi bản tin, không xác nhận Location/Lambda đã lưu thành công.

## Health và lệnh

`devices/<deviceid>/status` mỗi 30 s, có `gps.valid`, `ageMs`, `silent`, `gsvFresh`, checksum counters và `lastKnown` kèm `ageS`. Vị trí last-known là fix chất lượng gần nhất, độc lập với lần publish, không được đẩy vào tracker như một phép đo mới.

Lệnh chỉ trên `devices/<deviceid>/cmd`:

```json
{"cmd":"ping"}
{"cmd":"reboot"}
```

Ping có fix tốt thì trả vị trí mới; không có fix thì trả health. Không còn subscribe topic lệnh chung `esp32/sub`. `{"reboot":false}`, chuỗi chứa chữ reboot hoặc JSON sai không thực hiện lệnh.

## Source cloud đi kèm — cần triển khai riêng

`../vsmart-infrastructure/template.yml` thêm rule health tới Lambda hiện có, và đổi tracker sang `TimeBased` để đánh giá các fix dịch chuyển ngắn; dịch vụ lưu lịch sử tối đa một điểm mỗi 30 s. Health cập nhật `lastSeenAtMs`/online và `gpsHealth` riêng, không ghi đè position/sampleTime. Owner lấy từ metadata đăng ký thiết bị, không lấy từ body health. Body device ID phải khớp topic.

Lambda cũng giới hạn thuộc tính Location theo allowlist để vẫn nhận được firmware cũ gửi quá nhiều diagnostics, và kiểm tra timestamp/tọa độ. Các thay đổi này **chưa có hiệu lực trên AWS cho đến khi package/deploy stack**. Bản firmware mới giới hạn payload ngay ở nguồn nên sửa lỗi 15 thuộc tính không phụ thuộc việc deploy Lambda.

## Kiểm thử

```sh
sh test/host/run.sh
python3 -m unittest discover -s ../vsmart-infrastructure/tests -v
pio run -e devkitc -e s3mini -e devkitc-altpins
```

Host tests chạy parser và Telemetry thật với UART/MQTT/đồng hồ giả, bao phủ no-fix, stale fix, checksum, nhiều chòm vệ tinh, signal trùng, frame thiếu/hỏng, autobaud, timestamp, ping và schema lệnh. Test Lambda dùng mock AWS, không gọi tài khoản thật. Test host không thay thế thử task FreeRTOS/UART/TLS trên board.

Nghiệm thu phần cứng: nạp đúng board, để anten ngoài trời, quan sát `quality=1` và `MQTT wrote`; ngắt Wi-Fi rồi nối lại, kiểm tra GPS vẫn cập nhật; che tín hiệu GPS, kiểm tra chỉ health còn được gửi; đối chiếu vị trí trên dashboard sau khi deploy source cloud.

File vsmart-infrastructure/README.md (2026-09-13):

# Vsmart Tracking — Infrastructure

> **AWS CloudFormation** deployment for the complete Vsmart backend on AWS.

This single stack provisions **all** required AWS resources so you only need to deploy once to get a fully working cloud backend — from authentication to real-time GPS tracking.

---

## What's Included

| Service | Resource Name | Purpose |
|---|---|---|
| **Cognito User Pool** | `Vsmart-UserPool` | Email-based login / registration / OTP |
| **DynamoDB** | `Vsmart-Devices` | Device metadata storage |
| **DynamoDB** | `Vsmart-DeviceState` | Current device state for phased realtime rollout |
| **AWS Location Service** | `Vsmart-Map/Tracker/GeofenceCollection` | Map tiles, real-time GPS tracking, geofences |
| **AWS IoT Core** | `Vsmart_UpdateLocationTracker` | MQTT broker & routing rule |
| **Lambda (Python)** | `Vsmart-IoTMessageProcessor` | Parses MQTT payloads → pushes to Tracker |
| **Lambda (Python)** | `Vsmart-GeofenceEventConsumer` | Validates ownership and publishes geofence events |
| **EventBridge + SQS** | `Vsmart-GeofenceEventRule` | Captures geofence breach events |
| **SNS** | `Vsmart-AntitheftAlerts` | Email alert on anti-theft trigger |

---

## Prerequisites

Before deploying, make sure you have these installed and configured:

- [AWS CLI v2](https://docs.aws.amazon.com/cli/latest/userguide/install-cliv2.html) — and configured with `aws configure`
- Your IAM user must have **Administrator Access** (or permissions for CloudFormation, IAM, Lambda, Location, IoT, Cognito, DynamoDB, SNS, SQS, S3)

Verify your AWS identity:

```powershell
aws sts get-caller-identity
```

---

## Deployment Steps

### Step 1 — Create an S3 Bucket for artifacts

CloudFormation needs an S3 bucket to upload the Lambda source code before deploying.  
*(Pick a globally unique bucket name — it cannot already exist.)*

```powershell
aws s3 mb s3://vsmart-tracking-artifacts --region us-east-1
```

---

### Step 2 — Package the stack (uploads Lambda code to S3)

Run this from inside the `vsmart-infrastructure` directory:

```powershell
aws cloudformation package `
  --template-file template.yml `
  --s3-bucket vsmart-tracking-artifacts `
  --output-template-file packaged.yml `
  --region us-east-1
```

This command compresses the Lambda folders under `lambda/` and uploads them to S3, producing a new file `packaged.yml` with S3 references.

---

### Step 3 — Deploy the stack

```powershell
aws cloudformation deploy `
  --template-file packaged.yml `
  --stack-name Vsmart-UnifiedStack `
  --capabilities CAPABILITY_NAMED_IAM `
  --parameter-overrides AlertEmail="tranvix.work@gmail.com" `
  --region us-east-1
```

> **Replace** `your-email@example.com` with your real email.  
> AWS will send an **SNS subscription confirmation** email — you must click the link to activate alerts.

Deployment takes **3–8 minutes**. Wait for `CREATE_COMPLETE` status.

---

### Step 4 — Retrieve the Output values

Once deployment completes, fetch the generated resource IDs:

```powershell
aws cloudformation describe-stacks `
  --stack-name Vsmart-UnifiedStack `
  --query "Stacks[0].Outputs" `
  --output table
```

You will see a table like this:

| OutputKey | OutputValue |
|---|---|
| CognitoUserPoolId | `us-east-1_xxxxxxxxx` |
| CognitoClientId | `xxxxxxxxxxxxxxxxx` |
| DynamoTableName | `Vsmart-Devices` |
| DeviceStateTableName | `Vsmart-DeviceState` |
| MapName | `Vsmart-Map` |
| RealtimeAppEventsTopicTemplate | `users/{userId}/events` |
| RealtimeDebugDeviceEventsTopicTemplate | `devices/{deviceId}/events` |
| RealtimeRecommendedClientIdPrefix | `Vsmart-mobile-` |
| RealtimeWebhookSecretArn | `arn:aws:secretsmanager:...` |

For Phase 0 realtime preparation, also retrieve the AWS IoT data endpoint manually:

```powershell
aws iot describe-endpoint `
  --endpoint-type iot:Data-ATS `
  --query endpointAddress `
  --output text
```

Save this value for later phases when the mobile app starts connecting via MQTT over WebSocket.

---

### Step 4.5 — Create Map API Key manually *(required)*

> **Why manually?** The `geo:CreateKey` permission is often restricted in IAM policies, so the Map API Key is NOT created by CloudFormation. You must create it yourself in the AWS Console.

**Option A — AWS Console (recommended):**

1. Go to [AWS Location Service Console](https://console.aws.amazon.com/location/home) → **API Keys** in the left sidebar
2. Click **Create API Key**
3. Fill in:
   - **Name:** `Vsmart-MapApiKey`
   - **Expiry:** Check **No expiration**
4. Under **Restrictions → Allow actions**, add:
   - `geo:GetMap*` (or individually: `GetMapStyleDescriptor`, `GetMapGlyphs`, `GetMapSprites`, `GetMapTile`)
5. Under **Restrictions → Allow resources**, select the map: `Vsmart-Map`
6. Click **Create API Key**
7. **Copy the key value** — it starts with `v1.public.eyJ...` and is only shown once!

**Option B — AWS CLI:**

```powershell
aws location create-key `
  --key-name Vsmart-MapApiKey `
  --restrictions AllowActions="geo:GetMapStyleDescriptor","geo:GetMapGlyphs","geo:GetMapSprites","geo:GetMapTile",AllowResources="arn:aws:geo:us-east-1:<ACCOUNT_ID>:map/Vsmart-Map" `
  --no-expiry `
  --region us-east-1 `
  --query "Key" --output text
```

*(Replace `<ACCOUNT_ID>` with your AWS Account ID — run `aws sts get-caller-identity --query Account --output text` to get it.)*

---

### Step 5 — Update frontend and backend configuration

#### Frontend (`vsmart-web`)

Create a `.env` file by copying the example:

```powershell
copy ..\vsmart-web\.env.example ..\vsmart-web\.env
```

Fill in the values from Step 4:

```env
VITE_AWS_REGION=us-east-1
VITE_USER_POOL_ID=us-east-1_xxxxxxxxx
VITE_USER_POOL_CLIENT_ID=xxxxxxxxxxxxxxxxx
VITE_MAP_API_KEY=v1.public.xxxxxxx
```

#### Backend (`vsmart-backend`)

Open the `.env` file and update these fields. Retrieve the webhook value from the `RealtimeWebhookSecretArn` output with Secrets Manager; do not commit it.

```env
COGNITO_USER_POOL_ID=us-east-1_xxxxxxxxx
COGNITO_CLIENT_ID=xxxxxxxxxxxxxxxxx
REALTIME_WEBHOOK_KEY=<generated secret value>
```

---

## Updating the Stack

If you change `template.yml` or the Lambda code, re-run Steps 2 & 3 to update the stack:

```powershell
# Re-package
aws cloudformation package `
  --template-file template.yml `
  --s3-bucket vsmart-tracking-artifacts `
  --output-template-file packaged.yml

# Re-deploy (CloudFormation will only update changed resources)
aws cloudformation deploy `
  --template-file packaged.yml `
  --stack-name Vsmart-UnifiedStack `
  --capabilities CAPABILITY_NAMED_IAM `
  --parameter-overrides AlertEmail="your-email@example.com"
```

---

## Deleting the Stack

To remove **all** resources created by this stack:

```powershell
aws cloudformation delete-stack --stack-name Vsmart-UnifiedStack
```

> ⚠️ This will permanently delete DynamoDB data, Location resources, IoT rules, and all associated IAM roles.

---

## Stack Parameters

| Parameter | Default | Description |
|---|---|---|
| `ProjectName` | `Vsmart` | Prefix for all resource names |
| `Environment` | `dev` | Environment tag (`dev` / `staging` / `prod`) |
| `AlertEmail` | `admin@example.com` | Email for anti-theft SNS alerts |
| `MapStyle` | `VectorEsriNavigation` | AWS Location map style |

---

## Troubleshooting

| Error | Solution |
|---|---|
| `ROLLBACK_COMPLETE` on first deploy | Check the Events tab in CloudFormation console for the specific resource that failed |
| `CAPABILITY_NAMED_IAM` error | Add `--capabilities CAPABILITY_NAMED_IAM` to your deploy command |
| Lambda packaging fails | Make sure `lambda/iot-message-processor/index.py` exists |
| Geofence API returns `403` | Verify the backend IAM role can access the geofence collection and that the JWT owner matches `ownerUserId` |
| SNS subscription not active | Check your email inbox and click the "Confirm subscription" link from AWS |

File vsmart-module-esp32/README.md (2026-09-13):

# VSmart module carrier — ESP32-DevKitC (board 2)

Carrier lắp tay cho ESP32-DevKitC 38 chân + A7680C 4G + GPS NEO-7M (GY-GPSU3) + MPU6050. Board 105.1 × 82.1 mm, 2 lớp, mọi module cắm header.

## Rev C — trạng thái gia công (2026-08-30)

| Kiểm tra | Kết quả |
|---|---|
| DRC (`kicad-cli` 10.0.5, severity-all) | **0 vi phạm** (trước: 75) |
| Pad chưa nối / đối chiếu schematic ↔ PCB | **0 / 0** |
| Bộ gerber (`analyze_gerbers`) | **0 phát hiện**, đủ 7/7 lớp |
| Cross-domain | **0 phát hiện** |
| EMC risk score | 71.5/100 |
| Via | 294 (284 khâu GND + 4 hồi dòng + 1 chuyển lớp +3V3) |
| Lỗ khoan | 364 PTH + 5 NPTH, nhỏ nhất 0.3 mm |

Nộp xưởng: `manufacturing/vsmart-module-carrier-fab.zip` — 10 file phẳng.

## Đã sửa trong đợt này

### Điện áp — ba lỗi giống hệt board ESP32-S3

| Hạng mục | Trước | Sau |
|---|---|---|
| Net cấp U4 | `+4V_SIM` (4.0 V) | `+5V_SIM` (5 V 2 A) |
| Nguồn U3 (GPS) | `+5V` | `+3V3` |
| C1 | 1000 µF / 6.3 V | **1000 µF / 16 V** |

Ở 5 V thì tụ 6.3 V chỉ còn dư 21 % — quá sát cho tụ hoá tải xung 2 A.
Dùng loại **16 V, thân Ø10 mm** (footprint giữ nguyên).

### Đường mạch mới cho +3V3

Bỏ nhánh `+5V` chạy sang U3, **tái sử dụng hành lang B.Cu ở y ≈ 42.09** làm
đường `+3V3`, nối vào bằng nhánh mới qua cột trống x = 37.5:

```
U1.3V3 ─ B.Cu ─ (37.5, 59.22) ─ (37.5, 44.6) ─ (62.92, 44.6) ─ (62.92, 42.09) ─ … ─ U3.1
```

Không thể rẽ thẳng tại x = 62.92 vì `I2C_SCL` cắt ngang ở đó; cột x = 37.5 là
chỗ duy nhất trống ≥ 2 mm trên **cả hai mặt**.

### 75 → 0 vi phạm DRC

| Lỗi | Số | Nguyên nhân | Cách sửa |
|---|---|---|---|
| `clearance` | 18 | Netclass `POWER_SIM` cần hở 0.3 mm, vùng đồng đổ với 0.25 mm | Đặt zone clearance = 0.3 |
| `text_height` | 44 | Nhãn chân U1 (0.7 mm) và U4 (0.762 mm) dưới ngưỡng 0.8 | Nâng lên 0.85 |
| `lib_footprint_issues` | 7 | `fp-lib-table` trỏ sai thư mục dự án | Đổi sang `${KIPRJMOD}` |
| `silk_over_copper` | 6 | Silk U3 phủ chính chân nó; text B.Silk đè pad J1 | Thu mép silk, dời text |

Phát sinh và xử lý tiếp: nhãn chân U4 sau khi phóng to chạm pad → dịch trái
1.2 mm; footprint lỗ vít thay bằng bản thư viện chuẩn (mở mask 3.2 mm thay vì
6 mm hở đồng dưới đầu vít) → lộ ra **courtyard MH3 chồng U1 0.02 mm**, đã dời
MH3 và MH4 xuống y = 98.5 để giữ thẳng hàng.

### Bỏ C2 (100 nF gốm 0805)

Đo đường thật: C2 cách chân VCC của U4 **25 mm**. Với ~20 nH nối tiếp, tần số
tự cộng hưởng tụt về ~3.5 MHz — không còn làm được việc lọc cao tần. Bỏ để
thống nhất với board ESP32-S3 (tụ gốm dán khó hàn tay). Nếu modem reset khi
phát, hàn một tụ 104 thẳng lên chân VCC/GND của header U4.

### Silk

`+5V 1A` / `GND` cạnh J1, `+5V 2A` / `GND` cạnh J2 (mỗi nhãn thẳng hàng với
chân của nó), `SIM 5V 2A` cạnh U4, `GPS VCC=3V3` cạnh U3, `VSMART CARRIER REV C`
mặt sau.

## Đổi module GPS sang GY-GPSU3 (2026-08-30, cùng ngày)

Board này trước dùng **Keyestudio KS0319** (5 chân, thân 53 mm) trong khi board
ESP32-S3 đã dùng **GY-GPSU3** (4 chân, thân 25 mm). Nay đã thống nhất.

| | KS0319 | GY-GPSU3 |
|---|---|---|
| Chân | 5 (có PPS) | **4 (không PPS)** |
| Thân | 53 × 26 mm | **25 × 25 mm** |
| U3.1 | VCC | VCC |
| U3.2 | GND | **RXD** |
| U3.3 | TXD | TXD |
| U3.4 | RXD | **GND** |
| U3.5 | PPS | — |

**Hệ quả: net `GPS_PPS` bị bỏ hẳn.** GY-GPSU3 không có chân xung giây, nên
`U1.5 (GPIO34)` nay để trống và đã được đánh dấu no-connect. Nếu firmware của
bạn có dùng PPS để đồng bộ thời gian, **phải bỏ phần đó** — hoặc lấy thời gian
từ chuỗi NMEA (độ chính xác ~100 ms thay vì ~10 ns).

Ánh xạ chân đảo hoàn toàn nên phải đi lại 4 đường:

```
+3V3    hành lang B.Cu → via (118, 42.09) → F.Cu → U3.1 (122, 33.19)
GPS_TX  B.Cu y=34.46 → (118, 35.73) → U3.2 (122, 35.73)
GPS_RX  B.Cu y=41.03 → (116.74, 38.27) → U3.3 (122, 38.27)
GND     F.Cu trục dọc x=120.35 → U3.4 (122, 40.81)
```

`+3V3` phải nhảy sang F.Cu bằng via vì nó tới từ làn dưới cùng (y = 42.09)
nhưng chân đích lại nằm trên cùng (y = 33.19) — cắt qua cả `GPS_RX` và
`GPS_TX` nếu đi cùng lớp.

Một via khâu GND tại (120.45, 35.45) bị đường `GPS_TX` mới chạm vào và bị hút
sang net đó — đã phát hiện qua DRC (`via_dangling`) và xoá.

**Cơ hội chưa khai thác:** module mới nhỏ hơn 28 mm, giải phóng dải x = 69…99.
Nếu bố trí lại U3/U4/C1 thì có thể thu board xuống ≤ 100 mm để lọt bậc giá rẻ
(xem `DFM-001`). Chưa làm vì cần đi lại phần lớn đường mạch.

## Cây nguồn

| Rail | Đường đi | Bề rộng |
|---|---|---|
| `+5V` | J1 → C3 (470 µF/10 V) → U1.19 | 1.0 mm |
| `+5V_SIM` | J2 → C1 (1000 µF/16 V) → U4.8 | 2.0 mm |
| `+3V3` | U1.1 (ngõ ra LDO AMS1117) → U2.1 + U3.1 | 0.5–1.0 mm |
| `GND` | đổ đồng kín 2 mặt + 285 via khâu | — |

LDO 3.3 V trên DevKitC là **AMS1117-3.3 (~800 mA–1 A)** — dư sức gánh thêm GPS
(~50–80 mA). Đây là khác biệt lớn so với board ESP32-S3 SuperMini, nơi LDO chỉ
500 mA và phải kiểm trước.

## Trước khi cấp nguồn — phải tự đo

**Mức logic UART của A7680C.** ESP32 xuất 3.3 V; UART họ SIMCom A76xx thường là
1.8 V. Cấp nguồn module rời, đo chân TXD lúc rảnh: ~3.3 V nối thẳng được;
~1.8 V thì chừa trống hai chân RXD/TXD khi hàn và đấu qua module dịch mức 2
chiều (TXS0102 hoặc 2×BSS138 + trở kéo). Chân U4 là lỗ xuyên dùng header nên
không phải làm lại board.

## Trước khi đặt board

In `manufacturing/CHECK-1to1-footprints.pdf` ở **100 %** (tắt "fit to page"),
đặt U1–U4 thật lên giấy đối chiếu khoảng cách chân. Footprint U3 (KS0319) và
U4 (TDM-4G-V1) vẽ theo kích thước danh nghĩa, chưa đo trên hàng thật.

## Cấp nguồn

`J1` = 5 V/1 A (ESP32), `J2` = 5 V/2.5 A (SIM). **Cấp riêng.** Đừng câu J2 ăn
theo cọc của J1 — đường `+5V` chỉ 1.0 mm, xung 2 A của modem sẽ kéo sụt rail
ESP32. Một nguồn 5 V ≥ 3 A thì kéo hai cặp dây riêng, đấu hình sao tại nguồn.

## Ghi chú giá

`DFM-001`: board 105 × 82 mm **vượt ngưỡng 100 × 100 mm** của bậc giá rẻ nhất
tại JLCPCB/PCBWay. Thu chiều rộng xuống ≤ 100 mm sẽ rẻ hơn đáng kể, nhưng phải
bố trí lại linh kiện — chưa làm.

## Giới hạn của review

Không có thư mục `datasheets/`, không có MPN (0/8), không có API key và không có
SPICE simulator trên máy. Mọi kết luận về chân và điện là **kiểm tra tính nhất
quán**, không phải xác minh theo datasheet nhà sản xuất.

Báo cáo review đầy đủ: https://claude.ai/code/artifact/87d22087-bd5d-4769-baa9-9593b283e771

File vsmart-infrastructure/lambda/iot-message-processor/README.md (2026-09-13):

# Lambda Function: IoT Message Processor

Lambda function xử lý MQTT messages từ AWS IoT Core và cập nhật vị trí thiết bị vào Amazon Location Service.

## 📋 Mô Tả

Function này nhận messages từ IoT Core topic `location`, validate dữ liệu, và gọi API `BatchUpdateDevicePosition` của Amazon Location Service để cập nhật vị trí thiết bị.

## 🏗️ Kiến Trúc

```
IoT Device → MQTT Topic 'location' → IoT Rule → Lambda Function → Location Tracker
```

## 📥 Input Format

### MQTT Message Payload

```json
{
  "payload": {
    "deviceid": "Vehicle-1",
    "timestamp": 1713812103,
    "location": {
      "lat": 21.028511,
      "long": 105.804817
    },
    "accuracy": {
      "Horizontal": 20.5
    },
    "positionProperties": {
      "speed": "60",
      "heading": "180",
      "status": "moving",
      "battery": "85"
    }
  }
}
```

### Required Fields

| Field | Type | Description |
|---|---|---|
| `payload.deviceid` | string | Unique device identifier |
| `payload.timestamp` | integer | Unix timestamp (seconds) |
| `payload.location.lat` | float | Latitude (-90 to 90) |
| `payload.location.long` | float | Longitude (-180 to 180) |

### Optional Fields

| Field | Type | Description |
|---|---|---|
| `payload.accuracy` | object | Position accuracy |
| `payload.accuracy.Horizontal` | float | Horizontal accuracy in meters |
| `payload.positionProperties` | object | Custom properties (key-value pairs) |

## 📤 Output

### Success Response

```json
{
  "statusCode": 200,
  "body": {
    "message": "Position updated successfully",
    "deviceId": "Vehicle-1",
    "response": {
      "Errors": []
    }
  }
}
```

### Error Response

```json
{
  "statusCode": 400,
  "body": {
    "error": "Validation error",
    "message": "Missing required field: deviceid"
  }
}
```

## 🔧 Environment Variables

| Variable | Description | Example |
|---|---|---|
| `TRACKER_NAME` | Amazon Location Tracker name | `Vsmart-Tracker` |

## 📦 Dependencies

```
boto3>=1.34.0
botocore>=1.34.0
```

## 🚀 Deployment

### Option 1: CloudFormation (Inline Code)

Code được nhúng trực tiếp trong CloudFormation template `2-iot-resources.yml`.

```bash
aws cloudformation create-stack \
  --stack-name Vsmart-IoT \
  --template-body file://cloudformation/2-iot-resources.yml \
  --capabilities CAPABILITY_NAMED_IAM
```

### Option 2: Upload to S3

1. **Package function:**
   ```bash
   cd lambda/iot-message-processor
   pip install -r requirements.txt -t .
   zip -r function.zip .
   ```

2. **Upload to S3:**
   ```bash
   aws s3 cp function.zip s3://my-bucket/lambda/iot-processor.zip
   ```

3. **Deploy with CloudFormation:**
   ```bash
   aws cloudformation create-stack \
     --stack-name Vsmart-IoT \
     --template-body file://cloudformation/2-iot-resources.yml \
     --parameters \
       ParameterKey=LambdaCodeBucket,ParameterValue=my-bucket \
       ParameterKey=LambdaCodeKey,ParameterValue=lambda/iot-processor.zip \
     --capabilities CAPABILITY_NAMED_IAM
   ```

### Option 3: AWS CLI Direct

```bash
# Create function
aws lambda create-function \
  --function-name IoTMessageProcessor \
  --runtime python3.12 \
  --role arn:aws:iam::ACCOUNT_ID:role/LambdaExecutionRole \
  --handler index.lambda_handler \
  --zip-file fileb://function.zip \
  --environment Variables={TRACKER_NAME=Vsmart-Tracker}

# Update function code
aws lambda update-function-code \
  --function-name IoTMessageProcessor \
  --zip-file fileb://function.zip
```

## 🧪 Testing

### Test với AWS CLI

```bash
# Create test event
cat > test-event.json << EOF
{
  "payload": {
    "deviceid": "TestVehicle-1",
    "timestamp": $(date +%s),
    "location": {
      "lat": 21.028511,
      "long": 105.804817
    },
    "accuracy": {
      "Horizontal": 10.0
    },
    "positionProperties": {
      "speed": "50",
      "status": "moving"
    }
  }
}
EOF

# Invoke function
aws lambda invoke \
  --function-name Vsmart-IoTMessageProcessor \
  --payload file://test-event.json \
  response.json

# View response
cat response.json
```

### Test qua IoT Core

```bash
# Publish to MQTT topic
aws iot-data publish \
  --topic location \
  --payload '{
    "payload": {
      "deviceid": "Vehicle-1",
      "timestamp": '$(date +%s)',
      "location": {
        "lat": 21.028511,
        "long": 105.804817
      },
      "accuracy": {
        "Horizontal": 15.0
      }
    }
  }'

# Verify position updated
aws location get-device-position \
  --tracker-name Vsmart-Tracker \
  --device-id Vehicle-1
```

### Test với Python

```python
import boto3
import json
from datetime import datetime

lambda_client = boto3.client('lambda')

# Test event
event = {
    "payload": {
        "deviceid": "TestVehicle-1",
        "timestamp": int(datetime.now().timestamp()),
        "location": {
            "lat": 21.028511,
            "long": 105.804817
        },
        "accuracy": {
            "Horizontal": 10.0
        }
    }
}

# Invoke function
response = lambda_client.invoke(
    FunctionName='Vsmart-IoTMessageProcessor',
    InvocationType='RequestResponse',
    Payload=json.dumps(event)
)

# Print result
result = json.loads(response['Payload'].read())
print(json.dumps(result, indent=2))
```

## 📊 Monitoring

### CloudWatch Logs

```bash
# Tail logs in real-time
aws logs tail /aws/lambda/Vsmart-IoTMessageProcessor --follow

# Get recent errors
aws logs filter-log-events \
  --log-group-name /aws/lambda/Vsmart-IoTMessageProcessor \
  --filter-pattern "ERROR" \
  --max-items 10
```

### CloudWatch Metrics

Key metrics to monitor:
- **Invocations**: Number of times function is invoked
- **Errors**: Number of failed invocations
- **Duration**: Execution time
- **Throttles**: Number of throttled invocations

```bash
# Get invocation count
aws cloudwatch get-metric-statistics \
  --namespace AWS/Lambda \
  --metric-name Invocations \
  --dimensions Name=FunctionName,Value=Vsmart-IoTMessageProcessor \
  --start-time $(date -u -d '1 hour ago' +%Y-%m-%dT%H:%M:%S) \
  --end-time $(date -u +%Y-%m-%dT%H:%M:%S) \
  --period 300 \
  --statistics Sum
```

## 🔍 Debugging

### Common Issues

#### 1. Permission Denied

**Error:**
```
An error occurred (AccessDeniedException) when calling the BatchUpdateDevicePosition operation
```

**Solution:**
Kiểm tra IAM role có quyền `geo:BatchUpdateDevicePosition`:
```bash
aws iam get-role-policy \
  --role-name Vsmart-IoTLambdaRole \
  --policy-name LocationServiceAccess
```

#### 2. Invalid Position

**Error:**
```
ValidationException: Position must be within valid range
```

**Solution:**
- Latitude: -90 to 90
- Longitude: -180 to 180
- Đảm bảo thứ tự: [longitude, latitude] (GeoJSON format)

#### 3. Tracker Not Found

**Error:**
```
ResourceNotFoundException: Tracker not found
```

**Solution:**
Kiểm tra environment variable `TRACKER_NAME`:
```bash
aws lambda get-function-configuration \
  --function-name Vsmart-IoTMessageProcessor \
  --query 'Environment.Variables.TRACKER_NAME'
```

### Enable X-Ray Tracing

```bash
# Enable tracing
aws lambda update-function-configuration \
  --function-name Vsmart-IoTMessageProcessor \
  --tracing-config Mode=Active

# View traces
aws xray get-trace-summaries \
  --start-time $(date -u -d '1 hour ago' +%Y-%m-%dT%H:%M:%S) \
  --end-time $(date -u +%Y-%m-%dT%H:%M:%S)
```

## 🔐 Security Best Practices

1. **Least Privilege IAM Role**
   - Chỉ cấp quyền `geo:BatchUpdateDevicePosition` cho tracker cụ thể
   - Không sử dụng wildcard `*` trong Resource ARN

2. **Input Validation**
   - Validate tất cả required fields
   - Kiểm tra range của lat/long
   - Sanitize position properties

3. **Error Handling**
   - Không expose sensitive information trong error messages
   - Log errors với context đầy đủ
   - Implement retry logic cho transient errors

4. **Encryption**
   - Environment variables được mã hóa at-rest
   - Sử dụng HTTPS cho tất cả API calls

## 📈 Performance Optimization

### Current Configuration

- **Runtime**: Python 3.12
- **Memory**: 256 MB
- **Timeout**: 30 seconds
- **Concurrent Executions**: 1000 (default)

### Optimization Tips

1. **Reduce Cold Starts**
   - Sử dụng Provisioned Concurrency cho production
   - Keep dependencies minimal

2. **Batch Processing**
   - Function hỗ trợ batch updates (max 10 devices)
   - Sử dụng `batch_update_multiple_devices()` khi có nhiều updates

3. **Connection Reuse**
   - boto3 client được khởi tạo outside handler
   - Reuse connections across invocations

## 💰 Cost Estimation

### Lambda Costs

- **Requests**: $0.20 per 1M requests
- **Duration**: $0.0000166667 per GB-second

**Example (1M requests/month):**
- Requests: $0.20
- Duration (256MB, 100ms avg): ~$0.21
- **Total**: ~$0.41/month

### Location Service Costs

- **Tracker Updates**: $0.0425 per 1,000 updates
- **1M updates/month**: $42.50

## 📚 References

- [Amazon Location Service API Reference](https://docs.aws.amazon.com/location/latest/APIReference/)
- [AWS Lambda Python Runtime](https://docs.aws.amazon.com/lambda/latest/dg/lambda-python.html)
- [AWS IoT Core Rules](https://docs.aws.amazon.com/iot/latest/developerguide/iot-rules.html)
- [Boto3 Location Service](https://boto3.amazonaws.com/v1/documentation/api/latest/reference/services/location.html)

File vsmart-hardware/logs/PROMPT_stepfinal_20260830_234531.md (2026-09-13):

Đặt module A7680C trên board ESP32-S3 Mini với khe SIM ở phía trên như ảnh, giữ nguyên pinout; xác nhận DRC và xuất lại file sản xuất.

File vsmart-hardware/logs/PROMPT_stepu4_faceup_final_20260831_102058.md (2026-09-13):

Flip only the A7680C STEP model face 180 degrees around X so the SIM socket is visible from the PCB top view. Preserve U4 in-plane rotation/pin mapping, compensate Y offset to align the STEP body with pad rows, reroute and validate.

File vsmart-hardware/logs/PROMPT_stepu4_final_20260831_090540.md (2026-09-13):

Correct A7680C U4 orientation to match physical module: SIM socket at top; left RI,DTR,MICP,MICN,SPKP,SPKN; right ANT,VCC,RST,RXD,TXD,GND. Reroute and validate DRC/ERC/Gerbers.

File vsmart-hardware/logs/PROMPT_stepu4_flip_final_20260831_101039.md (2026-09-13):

Rotate the complete A7680C U4 module 180 degrees from the previous render so the SIM socket side faces upward on the PCB. Preserve correct pad numbers/nets, reroute, DRC/ERC/Gerber verify.

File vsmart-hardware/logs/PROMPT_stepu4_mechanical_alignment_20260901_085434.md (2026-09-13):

Căn lại toàn bộ 12 pad và lỗ cơ khí U4 A7680C với hàng lỗ thực tế của model 3D; dịch hàng pad 5.08 mm, lỗ cơ khí 2.54 mm, đi dây lại, DRC/ERC/Gerber kiểm tra sạch.

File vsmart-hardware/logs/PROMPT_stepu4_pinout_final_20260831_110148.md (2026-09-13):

Đổi vị trí chân U4 trên ESP32-S3 Mini theo ảnh module A7680C nhìn từ mặt trên: trái RI,DTR,MICP,MICN,SPKP,SPKN; phải ANT,VCC,RST,RXD,TXD,GND. Giữ đấu chéo UART đúng và khe SIM nhìn thấy từ trên.

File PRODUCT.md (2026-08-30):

# Product

<!-- impeccable:product-schema 1 -->

## Platform

web

Note: this product has a second, separate native surface — `vsmart-app/` (Expo/React Native, targeting iOS + Android). This root record's Platform value describes the web dashboard; scoped design work against `vsmart-app/` should treat platform as native and load iOS/Android guidance as needed.

## Users

Individual vehicle owners tracking and protecting a vehicle (car or motorbike) they personally own — not commercial fleet operators or multi-driver businesses. Each device belongs to exactly one owner (`ownerUserId`), enforced end to end; there is no team, driver, or shared-access role in the system today. Their job: know where their vehicle is right now, and find out immediately if it's moved or tampered with while parked.

## Product Purpose

Give a vehicle owner continuous, real-time visibility into their vehicle's location and automatic protection against theft while it's parked — without them running any infrastructure. Success means the owner trusts that a breach or unauthorized move will reach them within seconds, and that they can always see (live) or replay (history) where the vehicle has been.

## Positioning

Three things a generic consumer GPS-tracker app can't truthfully claim:

1. **Event-driven, not polled** — position updates and alerts push to the client the moment AWS IoT Core receives them (IoT Core → Lambda → DynamoDB/Location Service → webhook → Socket.io), not on a refresh/poll cycle.
2. **Zero-configuration anti-theft** — enabling protection auto-creates a 2m geofence at the vehicle's current parked position and self-disables after one breach alert; the owner never draws a protection zone by hand.
3. **A working, real AWS architecture, not a mockup** — this is a graduation-thesis engineering demonstration. The product truth and any design work must read as an actually-operating serverless system (real IoT Core, real Lambda, real Location Service), because that credibility is the point being evaluated, even though the audience for the *product itself* is a single vehicle owner, not an enterprise buyer. (The README's "Fleet Management" title is the thesis's formal name, not evidence of a multi-vehicle business audience — see Users above.)

## Operating Context

- Owner registers a device (manual entry on web, or camera QR/barcode scan on mobile), views its live position on a map, draws/manages geofences, replays a chosen day's position history, and can enable one-tap anti-theft on a parked vehicle — all from either surface.
- Two UI surfaces share one backend and one user identity: **web dashboard** (`tracking-data-streaming-datn/`, full feature set: Dashboard, Map View, Devices, Geofences, Settings) and **mobile companion app** (`vsmart-app/`, Expo/React Native, iOS + Android; adds camera-based device registration the web dashboard doesn't have).
- Runs on real AWS infrastructure in `ap-southeast-1` (Singapore); demo/simulator GPS data is centered on Ho Chi Minh City.
- Auth via Amazon Cognito (sign up, sign in, email confirmation); device data is a merge of DynamoDB (metadata) and Amazon Location Service (live position, geofences).

## Capabilities and Constraints

- Confirmed: real-time GPS tracking, geofencing (polygon/circle) with enter/exit alerts, automatic anti-theft (auto 2m geofence, self-disabling after one breach), position history replay, device CRUD, Cognito-based auth. A local-dev-only road-snapping (map-matching) feature was just added on the backend to make the live marker and history replay follow roads instead of raw GPS jitter.
- One owner per device is a hard constraint, enforced server-side on every device/anti-theft/geofence code path (see `.agents/AGENTS.md`) — not just a UI convention.
- No multi-driver/team/role model exists; undecided whether one will ever be needed (explicitly out of scope for now — audience is individual owners).
- This is an academic graduation project, not a system currently serving paying customers — evaluated as an engineering demonstration.
- Fully serverless backend/infra (Lambda, DynamoDB, Amazon Location Service, IoT Core, EventBridge, SQS, SNS, Cognito) — no persistent server process holds state other than the stateless Node/Express API + Socket.io proxy.

## Brand Commitments

- Product name: **VSmart Tracking** (full), **VSmart** (short form, used as the web sidebar wordmark).
- Existing color identity (not yet unified into shared tokens — evidence, not a decided system): web dashboard's primary accent is Tailwind indigo (`indigo-600`, ≈ `#4F46E5`); mobile app uses a violet/purple accent (`#7C3AED`) for its notification icon and a dark navy (`#0B0F1A`) adaptive-icon background.
- Existing logo: an abstract three-bar "waveform" glyph in an indigo-tinted rounded tile, used in the web sidebar. The mobile app icon is a separate asset (`vsmart-app/assets/icon.png`), not audited here.
- **Standing visual-world preference (confirmed):** after seeing a first oblique direction (a sewing-pattern-envelope world) built and reviewed, the user pinned the **category-standard consumer tracking/security-app look**, played straight at full craft, over any oblique metaphor — referencing **Life360, Apple Find My, and the Tesla app** as the craft bar. This means: a live map as the product's own visual center (not decorative), dark UI as the default surface, floating status cards/pills for live state, and the existing indigo/violet identity unified rather than replaced. Any future new-work round for this product should treat this as the committed world and skip re-rolling a different aesthetic unless the user asks again.

## Evidence on Hand

- `README.md` at the repo root: full architecture (Mermaid diagrams), AWS resource inventory, per-workflow sequence diagrams, and API reference — treat as the authoritative technical source.
- The described feature set is implemented and running, not a mockup: both UI surfaces have real, working screens (web: Tailwind + Lucide icons; mobile: native Expo components).
- No customer testimonials, case studies, press mentions, benchmarks, or production user base exist. This is pre-launch/academic — future design or copy work must not invent any of these.
- No `DESIGN.md` exists yet; `/impeccable document` is the natural next step to capture the incumbent visual system deliberately.

## Product Principles

1. Every position update and alert reaches the owner within seconds, event-driven end to end — never make the owner poll or refresh to learn something changed.
2. Protecting a parked vehicle takes one tap, not manual setup — anti-theft stays zero-configuration.
3. The product serves one owner and their own vehicle(s) — every device-facing action must be provably scoped to that owner; never assume shared or team access.
4. Credibility rests on a real, running AWS architecture — design and copy should reflect an actually-operating system, not a demo veneer.
5. Web and mobile are two views onto the same live state, not two separate products — parity in what an owner can see and do, aside from mobile's device-registration scanning.

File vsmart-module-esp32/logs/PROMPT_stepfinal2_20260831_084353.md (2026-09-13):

Xoay vật lý module A7680C U4 180 độ để khe SIM nằm phía trên như module thật, giữ nguyên pad-net/pinout; board DevKitC 95x70 mm.

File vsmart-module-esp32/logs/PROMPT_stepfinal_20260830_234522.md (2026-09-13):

Tối ưu board ESP32 DevKitC còn 95 x 70 mm; đặt module A7680C với khe SIM ở phía trên như ảnh, giữ nguyên pinout; hoàn tất routing và xuất file sản xuất.

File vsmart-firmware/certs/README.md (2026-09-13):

# Device certificates

Where the files downloaded from AWS IoT Core live. The firmware does **not**
read them at build time — it embeds the PEM strings via `include/secrets.h`
(see `include/secrets.example.h`).

Current set — IoT thing `NCKH-2025-2026`, account `022499043310`,
region `ap-southeast-1`, certificate ID `1f8caa5c…902b7351` (ACTIVE):

| File | Used as |
|---|---|
| `AmazonRootCA1.pem` | `AWS_CERT_CA` |
| `<id>-certificate.pem.crt` | `AWS_CERT_CRT` |
| `<id>-private.pem.key` | `AWS_CERT_PRIVATE` |
| `<id>-public.pem.key` | unused by the firmware |

To confirm a key and certificate belong together:

```bash
openssl x509 -noout -modulus -in <id>-certificate.pem.crt | openssl md5
openssl rsa  -noout -modulus -in <id>-private.pem.key     | openssl md5
```

Both digests must match.

This directory used to sit at `lib/secrets/`, which was the wrong place:
PlatformIO scans `lib/` for libraries, so everything in there was dragged into
dependency resolution.

Only `AmazonRootCA*.pem` is tracked by git; the device certificate and private
key are excluded in `.gitignore`. AWS lets you download a private key **only at
creation time** — if this one is lost, the certificate has to be replaced.

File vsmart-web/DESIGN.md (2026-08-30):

---
name: Vsmart Tracking
description: Real-time vehicle tracking and anti-theft dashboard — a calm, muted-indigo SaaS system with unified light and dark modes
colors:
  surface-light: "#f6f7f9"
  surface-dark: "#16161b"
  card-light: "#ffffff"
  card-dark: "#222229"
  card-muted-light: "#eceef2"
  card-muted-dark: "#2d2d35"
  ink-light: "#202124"
  ink-dark: "#f3f3f5"
  muted-light: "#687080"
  muted-dark: "#a4a4af"
  subtle-light: "#9a9fac"
  subtle-dark: "#6f707c"
  hairline-light: "#dfe2e8"
  hairline-dark: "#3a3a44"
  brand-500: "#6664d8"
  brand-400: "#8d8ae8"
typography:
  sans:
    fontFamily: "Inter, ui-sans-serif, system-ui, sans-serif"
  mono:
    fontFamily: "IBM Plex Mono, ui-monospace, monospace"
  eyebrow:
    fontFamily: "{typography.mono.fontFamily}"
    fontSize: "0.625rem"
    letterSpacing: "0.17em"
    textTransform: "uppercase"
rounded:
  sm: "8px"
  md: "12px"
  lg: "16px"
  xl: "24px"
  full: "9999px"
components:
  button-primary:
    backgroundColor: "{colors.brand-500}"
    backgroundColorDark: "{colors.brand-400}"
    textColor: "#ffffff"
    textColorDark: "#16161b"
    rounded: "{rounded.md}"
    padding: "8px 16px"
  card:
    backgroundColor: "{colors.card-light}"
    backgroundColorDark: "{colors.card-dark}"
    border: "1px solid {colors.hairline-light}"
    borderDark: "1px solid {colors.hairline-dark}"
    rounded: "{rounded.lg}"
    shadow: "0 14px 44px rgba(31,35,44,0.08)"
    shadowDark: "0 16px 50px rgba(0,0,0,0.24)"
---

# Design System: Vsmart Tracking

## Overview

**Canonical direction: "Calm Muted-Indigo SaaS"**

This is the approved, unified system for the web dashboard, implemented across every screen (marketing landing page, auth, sidebar/header shell, dashboard, device management, geofences, map overlays). It replaces an earlier dark-only "Night Watch Console" exploration that the product owner reviewed and rejected (color, layout, and typography all read as "off"). The current system is derived from the user's own reference project (`archflow-app`): soft, low-saturation surfaces, one muted-indigo accent, mono eyebrow labels, and diffused shadows instead of hard borders or glows.

**Key characteristics:**
- Every screen supports both **light and dark mode**, switched by toggling a `dark` class on `<html>` (Tailwind `darkMode: 'class'`), controlled by `useTheme()` (`src/hooks/useTheme.jsx`) and persisted to `localStorage` under `vsmart-theme`. Initial theme resolves from stored preference, falling back to `prefers-color-scheme`.
- One accent hue (muted indigo) carries brand and interactive weight in both modes; semantic colors (emerald = success/online/protected, rose = danger/breach/offline, amber = warning/maintenance, blue = informational) are reserved for status, never used decoratively.
- Cards and panels are distinguished by a soft diffused shadow plus a hairline border — not by strong contrast blocks.
- The live map is the product's visual anchor (dashboard mini-map, full map view, auth branding panel) and itself switches basemap style between AWS Location Service's `Light`/`Dark` color-scheme in sync with the UI theme.

## Colors

### Surfaces
- **Surface** — page background: `#f6f7f9` light / `#16161b` dark (Tailwind `bg-surface` / `dark:bg-surface-dark`)
- **Card** — panel/card background: `#ffffff` light / `#222229` dark (`bg-card` / `dark:bg-card-dark`)
- **Card Muted** — sunken well inside a card (progress tracks, input fills): `#eceef2` light / `#2d2d35` dark (`bg-card-muted` / `dark:bg-card-muted-dark`)
- **Hairline** — all card/input/divider borders: `#dfe2e8` light / `#3a3a44` dark (`border-hairline` / `dark:border-hairline-dark`)

### Text
- **Ink** — primary text: `#202124` light / `#f3f3f5` dark (`text-ink` / `dark:text-ink-dark`)
- **Muted** — secondary text: `#687080` light / `#a4a4af` dark (`text-muted` / `dark:text-muted-dark`)
- **Subtle** — tertiary/placeholder text: `#9a9fac` light / `#6f707c` dark (`text-subtle` / `dark:text-subtle-dark`)

### Brand accent
- **Brand 500** (`#6664d8`) — primary interactive color in light mode: buttons, active nav state, links, focus rings.
- **Brand 400** (`#8d8ae8`) — primary interactive color in dark mode (lighter for contrast against dark surfaces).
- Full `brand-50`…`brand-900` scale defined in `tailwind.config.js` for tints (e.g. `bg-brand-50 dark:bg-brand-400/10` for soft icon tiles).

### Semantic status (used consistently, never decoratively)
- **Emerald** (`emerald-500/600` light, `emerald-400` dark) — active/online/protected/success.
- **Rose** (`rose-500/600` light, `rose-400` dark) — danger/breach/offline/delete.
- **Amber** (`amber-500/600` light, `amber-400` dark) — warning/maintenance/pending.
- **Blue** (`blue-500/600` light, `blue-400` dark) — informational/edit action.

### Named Rules
**The One Accent Rule.** Muted indigo (`brand-*`) is the only hue used for brand/interactive chrome; emerald/rose/amber/blue are reserved for semantic status and action-type buttons (edit=blue, create=emerald, delete/disable=rose) and never substitute for the brand accent.

### Incidental utility colors
A small set of literal colors outside the palette above are intentional, scoped UI chrome rather than design-system drift: scrollbar track/thumb shades (`#eceef2`/`#c7cad1`/`#a9adb6` light, `#1c1c22`/`#3a3a44`/`#4a4a56` dark) and neutral shadow rgba values for MapLibre control popups (`rgba(0,0,0,0.3-0.4)` dark). These follow the same light/dark pairing discipline as the rest of the system but are not part of the brand/semantic palette, so they are not restated as named tokens.

## Typography

**Sans:** Inter (`ui-sans-serif, system-ui` fallback) — all interface text, headings, and body copy.
**Mono:** IBM Plex Mono — reserved for eyebrow/label text, coordinates, timestamps, and device IDs, echoing the product's "live data readout" identity.

Marketing headlines use `font-semibold` with tight tracking (`tracking-[-0.02em]` to `tracking-[-0.03em]`); UI chrome (nav items, table headers, stat labels) uses uppercase mono or sans at `text-[10px]`–`text-xs` with wide tracking for scannability.

## Dark Mode Implementation

- **Strategy:** Tailwind `darkMode: 'class'`. A `dark` class on `<html>` activates all `dark:` variants app-wide.
- **Toggle:** `src/hooks/ThemeProvider.jsx` provides theme state and `src/hooks/useTheme.js` exposes it. Wrapped around `<App />` in `main.jsx`.
- **Persistence:** `localStorage['vsmart-theme']`, read synchronously in `index.html`'s pre-paint inline script to avoid a flash of the wrong theme before React mounts.
- **Initial value:** stored preference, else `window.matchMedia('(prefers-color-scheme: dark)')`.
- **Map basemap:** AWS Location Service style descriptor URL's `color-scheme` query param (`Light`/`Dark`) is derived from `theme` in every map-rendering component (`App.jsx`, `DashboardView.jsx`, `MapView.jsx`), so the basemap itself switches in sync with the UI shell.
- **Map paint layers:** MapLibre `paint` properties (route lines, geofence fills, markers) are literal hex values, not Tailwind classes, since they render on canvas. These use the brand hex (`#6664d8`) and semantic hex (status colors, `#e11d48` rose for breach) directly and are intentionally the same value in both themes — only the basemap style beneath them switches.
- **Settings page** (`App.jsx`, Settings view) exposes an explicit Light/Dark picker in addition to the Header's toggle button, so theme control has two discoverable entry points.

## Elevation & Depth

Cards and floating panels use a soft, diffused, non-directional shadow (`shadow-panel` / `dark:shadow-panel-dark`, and a stronger `shadow-panel-lg`/`dark:shadow-panel-lg-dark` for modals and floating map overlays) plus a 1px hairline border — never a hard drop shadow or colored glow.

### Named Rules
**The No-Glow Rule.** No colored halos, radial accent washes, or tinted box-shadows. Depth comes from soft neutral shadows plus hairline borders only, in both themes.

## Shapes

- Cards, modals, and large panels: `rounded-2xl`/`rounded-3xl` (16–24px).
- Buttons, inputs, small tiles: `rounded-xl` (12px).
- Status pills, badges, avatars: fully rounded.

## Components

Shared component classes live in `src/index.css` under `@layer components` and already carry `dark:` variants — prefer these over ad-hoc utility strings when a new UI matches the pattern:

- **`.btn-primary`** — brand-filled button. `bg-brand-500` light / `bg-brand-400` dark, white text light / near-black text dark (for contrast against the lighter dark-mode accent).
- **`.btn-secondary`** — outlined/neutral button. Card background, hairline border, ink text.
- **`.btn-danger`** — solid rose button for destructive actions.
- **`.card`** — the standard panel: card background, hairline border, `rounded-2xl`, soft shadow.
- **`.input-field`** — form input: card background (light) / `white/5` translucent fill (dark), hairline border, brand-colored focus ring.

Semantic action buttons that are *not* the brand accent (edit = blue, create = emerald, delete/disable = rose) are literal Tailwind color utilities with `dark:` variants, kept intentionally distinct from `.btn-primary` since they signal a specific action type rather than the primary brand action.

### Floating map panels (Geofences drawing UI, device detail panel, devices overlay)
- **Style:** `bg-card/95 dark:bg-card-dark/95` with `backdrop-blur-md`, hairline border, `shadow-panel-lg`/`dark:shadow-panel-lg-dark`, `rounded-2xl`/`rounded-3xl`.
- These float above the MapLibre canvas and must stay legible over both light and dark basemaps — the translucent card background plus blur ensures contrast regardless of what's underneath.

### Status Pill
- **Style:** pill-shaped, background at ~10% opacity of its status color (`bg-emerald-50 dark:bg-emerald-500/10` etc.), text and icon in the full-strength status color, border at ~20-30% opacity.
- **States:** `active`/`online`/`protected` (emerald), `breach`/`offline`/`disabled` (rose), `maintenance`/`pending` (amber).

## Layout

Marketing sections (`LandingPage.jsx`) run at `max-w-[1180px]` with `py-20`–`py-24` vertical rhythm. App shell content areas use `p-4 md:p-6` padding with `space-y-6` between major blocks. Two-column dashboard grids use `lg:grid-cols-12` with 7/5 or similar splits.

## Do's and Don'ts

### Do:
- **Do** use `.card`/`.btn-primary`/`.btn-secondary`/`.input-field` component classes for new UI before reaching for ad-hoc utility strings.
- **Do** pair every custom color utility with its `dark:` counterpart — there is no light-only or dark-only screen in this system.
- **Do** keep status color strictly semantic (emerald = protected/online, rose = breach/offline, amber = maintenance/warning).
- **Do** derive map basemap `color-scheme` from the active theme wherever a map is rendered.

### Don't:
- **Don't** add colored glows, radial accent washes, or tinted shadows.
- **Don't** introduce a second accent hue — indigo (`brand-*`) is the only brand/interactive color.
- **Don't** reintroduce the old `aws-gray`/`aws-orange`/literal `indigo-600` Tailwind tokens — they have been fully removed from `tailwind.config.js` in favor of the semantic token set (`surface`, `card`, `ink`, `muted`, `subtle`, `hairline`, `brand`).

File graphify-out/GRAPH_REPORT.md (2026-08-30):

# Graph Report - DATN  (2026-07-08)

## Corpus Check
- 193 files · ~1,565,282 words
- Verdict: corpus is large enough that graph structure adds value.

## Summary
- 1423 nodes · 1795 edges · 114 communities (91 shown, 23 thin omitted)
- Extraction: 98% EXTRACTED · 2% INFERRED · 0% AMBIGUOUS · INFERRED: 42 edges (avg confidence: 0.8)
- Token cost: 0 input · 0 output

## Community Hubs (Navigation)
- [[_COMMUNITY_Backend Auth & Middleware|Backend Auth & Middleware]]
- [[_COMMUNITY_Mobile App Device & Scan|Mobile App Device & Scan]]
- [[_COMMUNITY_Web Frontend Project Config|Web Frontend Project Config]]
- [[_COMMUNITY_Mobile App Dependencies|Mobile App Dependencies]]
- [[_COMMUNITY_Backend Config & Packages|Backend Config & Packages]]
- [[_COMMUNITY_Mobile App Android Resources|Mobile App Android Resources]]
- [[_COMMUNITY_Web Geofencing UI|Web Geofencing UI]]
- [[_COMMUNITY_IoT Message Processor Lambda|IoT Message Processor Lambda]]
- [[_COMMUNITY_Mobile App Geofence Screens|Mobile App Geofence Screens]]
- [[_COMMUNITY_Backend UtilitySimulation Scripts|Backend Utility/Simulation Scripts]]
- [[_COMMUNITY_Backend Anti-Theft Logic|Backend Anti-Theft Logic]]
- [[_COMMUNITY_Web Map Interface Components|Web Map Interface Components]]
- [[_COMMUNITY_Backend Device Controller|Backend Device Controller]]
- [[_COMMUNITY_Web Device Management UI|Web Device Management UI]]
- [[_COMMUNITY_Mobile App Project Config|Mobile App Project Config]]
- [[_COMMUNITY_Mobile App Component|Mobile App Component]]
- [[_COMMUNITY_Backend DynamoDB Services|Backend DynamoDB Services]]
- [[_COMMUNITY_Web Map Interface Components|Web Map Interface Components]]
- [[_COMMUNITY_Mobile App Component|Mobile App Component]]
- [[_COMMUNITY_Web Frontend Component|Web Frontend Component]]
- [[_COMMUNITY_Geofence Event Consumer Lambda|Geofence Event Consumer Lambda]]
- [[_COMMUNITY_Backend UtilitySimulation Scripts|Backend Utility/Simulation Scripts]]
- [[_COMMUNITY_Mobile App Geofence Screens|Mobile App Geofence Screens]]
- [[_COMMUNITY_Mobile App Auth Screens|Mobile App Auth Screens]]
- [[_COMMUNITY_Mobile App Auth Screens|Mobile App Auth Screens]]
- [[_COMMUNITY_Mobile App Navigation Tabs|Mobile App Navigation Tabs]]
- [[_COMMUNITY_Backend Auth & Middleware|Backend Auth & Middleware]]
- [[_COMMUNITY_Offline Detector Lambda|Offline Detector Lambda]]
- [[_COMMUNITY_Backend Location & Geo Services|Backend Location & Geo Services]]
- [[_COMMUNITY_Backend Location & Geo Services|Backend Location & Geo Services]]
- [[_COMMUNITY_Mobile App Navigation Tabs|Mobile App Navigation Tabs]]
- [[_COMMUNITY_Mobile App Component|Mobile App Component]]
- [[_COMMUNITY_Web Layout & Common UI|Web Layout & Common UI]]
- [[_COMMUNITY_Web Map Interface Components|Web Map Interface Components]]
- [[_COMMUNITY_Mobile App Component|Mobile App Component]]
- [[_COMMUNITY_Backend SNS Notifications|Backend SNS Notifications]]
- [[_COMMUNITY_Web Device Management UI|Web Device Management UI]]
- [[_COMMUNITY_Backend UtilitySimulation Scripts|Backend Utility/Simulation Scripts]]
- [[_COMMUNITY_Backend UtilitySimulation Scripts|Backend Utility/Simulation Scripts]]
- [[_COMMUNITY_Realtime Event Publisher Lambda|Realtime Event Publisher Lambda]]
- [[_COMMUNITY_Mobile App Component|Mobile App Component]]
- [[_COMMUNITY_Mobile App Component|Mobile App Component]]
- [[_COMMUNITY_Community 50|Community 50]]
- [[_COMMUNITY_Community 51|Community 51]]
- [[_COMMUNITY_Community 52|Community 52]]
- [[_COMMUNITY_Community 53|Community 53]]
- [[_COMMUNITY_Community 54|Community 54]]
- [[_COMMUNITY_Community 55|Community 55]]
- [[_COMMUNITY_Community 56|Community 56]]
- [[_COMMUNITY_Community 57|Community 57]]
- [[_COMMUNITY_Community 58|Community 58]]
- [[_COMMUNITY_Community 59|Community 59]]
- [[_COMMUNITY_Community 61|Community 61]]
- [[_COMMUNITY_Community 62|Community 62]]
- [[_COMMUNITY_Community 63|Community 63]]
- [[_COMMUNITY_Community 64|Community 64]]
- [[_COMMUNITY_Community 65|Community 65]]
- [[_COMMUNITY_Community 66|Community 66]]
- [[_COMMUNITY_Community 67|Community 67]]
- [[_COMMUNITY_Community 68|Community 68]]
- [[_COMMUNITY_Community 69|Community 69]]
- [[_COMMUNITY_Community 70|Community 70]]
- [[_COMMUNITY_Community 71|Community 71]]
- [[_COMMUNITY_Community 72|Community 72]]
- [[_COMMUNITY_Community 73|Community 73]]
- [[_COMMUNITY_Community 74|Community 74]]
- [[_COMMUNITY_Community 75|Community 75]]
- [[_COMMUNITY_Community 76|Community 76]]
- [[_COMMUNITY_Community 77|Community 77]]
- [[_COMMUNITY_Community 78|Community 78]]
- [[_COMMUNITY_Community 79|Community 79]]
- [[_COMMUNITY_Community 80|Community 80]]
- [[_COMMUNITY_Community 81|Community 81]]
- [[_COMMUNITY_Community 82|Community 82]]
- [[_COMMUNITY_Community 83|Community 83]]
- [[_COMMUNITY_Community 84|Community 84]]
- [[_COMMUNITY_Community 85|Community 85]]
- [[_COMMUNITY_Community 86|Community 86]]
- [[_COMMUNITY_Community 87|Community 87]]
- [[_COMMUNITY_Community 88|Community 88]]
- [[_COMMUNITY_Community 89|Community 89]]
- [[_COMMUNITY_Community 91|Community 91]]
- [[_COMMUNITY_Community 92|Community 92]]
- [[_COMMUNITY_Community 93|Community 93]]
- [[_COMMUNITY_Community 94|Community 94]]
- [[_COMMUNITY_Community 96|Community 96]]
- [[_COMMUNITY_Community 97|Community 97]]
- [[_COMMUNITY_Community 98|Community 98]]
- [[_COMMUNITY_Community 100|Community 100]]
- [[_COMMUNITY_Community 101|Community 101]]
- [[_COMMUNITY_Community 102|Community 102]]
- [[_COMMUNITY_Community 103|Community 103]]
- [[_COMMUNITY_Community 104|Community 104]]
- [[_COMMUNITY_Community 105|Community 105]]
- [[_COMMUNITY_Community 106|Community 106]]
- [[_COMMUNITY_Community 110|Community 110]]
- [[_COMMUNITY_Community 111|Community 111]]
- [[_COMMUNITY_Community 112|Community 112]]
- [[_COMMUNITY_Community 113|Community 113]]
- [[_COMMUNITY_Community 114|Community 114]]
- [[_COMMUNITY_Community 115|Community 115]]
- [[_COMMUNITY_Community 116|Community 116]]
- [[_COMMUNITY_Community 117|Community 117]]
- [[_COMMUNITY_Community 118|Community 118]]

## God Nodes (most connected - your core abstractions)
1. `TinyGPSPlus` - 47 edges
2. `PubSubClient` - 36 edges
3. `TinyGPSLocation` - 25 edges
4. `useToast()` - 22 edges
5. `millis()` - 22 edges
6. `TinyGPSCustom` - 19 edges
7. `TinyGPSTime` - 18 edges
8. `TinyGPSDate` - 17 edges
9. `TinyGPSDecimal` - 17 edges
10. `expo` - 15 edges

## Surprising Connections (you probably didn't know these)
- `GeofencesScreen()` --calls--> `useToast()`  [EXTRACTED]
  vsmart-app/app/(tabs)/geofences.jsx → vsmart-app/src/components/ui/Toast.jsx
- `TinyGPSLocation` --references--> `MODE`  [EXTRACTED]
  vsmart-iot/.pio/libdeps/esp32doit-devkit-v1/TinyGPSPlus/src/TinyGPS++.h → vsmart-app/app/geofence-draw.jsx
- `GeofenceDrawScreen()` --calls--> `useToast()`  [EXTRACTED]
  vsmart-app/app/geofence-draw.jsx → vsmart-app/src/components/ui/Toast.jsx
- `App()` --calls--> `useDeviceManager()`  [EXTRACTED]
  tracking-data-streaming-datn/src/App.jsx → tracking-data-streaming-datn/src/hooks/useDeviceManager.js
- `DevicesScreen()` --calls--> `useToast()`  [EXTRACTED]
  vsmart-app/app/(tabs)/devices.jsx → vsmart-app/src/components/ui/Toast.jsx

## Import Cycles
- 1-file cycle: `vsmart-app/metro.config.js -> vsmart-app/metro.config.js`

## Communities (114 total, 23 thin omitted)

### Community 0 - "Backend Auth & Middleware"
Cohesion: 0.05
Nodes (34): antitheftRoutes, app, {
    APP_EVENTS_TOPIC_TEMPLATE,
    DEBUG_DEVICE_EVENTS_TOPIC_TEMPLATE,
    RAW_TELEMETRY_TOPIC_TEMPLATE,
    REALTIME_EVENT_TYPES,
    REALTIME_SCHEMA_VERSION,
    SAMPLE_REALTIME_EVENTS,
    validateRealtimeEnvelope,
}, authRoutes, cors, deviceRoutes, { errorHandler, notFoundHandler }, express (+26 more)

### Community 1 - "Mobile App Device & Scan"
Cohesion: 0.24
Nodes (11): DeviceDataContext, DeviceDataProvider(), applyRealtimeEventToDevices(), createRealtimeEventTracker(), getRealtimeNotificationDescriptor(), isObject(), REALTIME_EVENT_SAMPLES, REALTIME_EVENT_TYPES (+3 more)

### Community 2 - "Web Frontend Project Config"
Cohesion: 0.05
Nodes (37): dependencies, @aws/amazon-location-utilities-auth-helper, aws-amplify, @aws-sdk/client-location, @aws-sdk/client-sqs, @aws-sdk/credential-providers, clsx, lucide-react (+29 more)

### Community 3 - "Mobile App Dependencies"
Cohesion: 0.05
Nodes (37): dependencies, @aws/amazon-location-utilities-auth-helper, @aws-sdk/client-location, @aws-sdk/credential-providers, babel-preset-expo, buffer, expo, expo-camera (+29 more)

### Community 4 - "Backend Config & Packages"
Cohesion: 0.06
Nodes (35): author, dependencies, aws-jwt-verify, @aws-sdk/client-cognito-identity-provider, @aws-sdk/client-dynamodb, @aws-sdk/client-iot, @aws-sdk/client-iot-data-plane, @aws-sdk/client-location (+27 more)

### Community 5 - "Mobile App Android Resources"
Cohesion: 0.06
Nodes (35): backgroundColor, foregroundImage, adaptiveIcon, edgeToEdgeEnabled, package, permissions, predictiveBackGestureEnabled, reactCompiler (+27 more)

### Community 6 - "Web Geofencing UI"
Cohesion: 0.12
Nodes (10): DrawControl(), DrawnGeofences(), polygons, polygonsBorders, polygonsBreached, polygonsBreachedBorders, CIRCLE_STEPS, draw (+2 more)

### Community 7 - "IoT Message Processor Lambda"
Cohesion: 0.19
Nodes (19): batch_update_multiple_devices(), build_location_update(), _call_webhook(), _debug_topic(), _get_device_metadata(), _get_device_state(), _get_iot_data_client(), lambda_handler() (+11 more)

### Community 8 - "Mobile App Geofence Screens"
Cohesion: 0.15
Nodes (11): GeofenceDrawScreen(), s, GeofencesScreen(), s, TEMPLATES, COGNITO, GeofenceDataContext, GeofenceDataProvider() (+3 more)

### Community 9 - "Backend Utility/Simulation Scripts"
Cohesion: 0.13
Nodes (11): getIotDataClient(), iotClient, { IoTClient, DescribeEndpointCommand }, { IoTDataPlaneClient, PublishCommand }, publishTelemetry(), readline, rl, sqsClient (+3 more)

### Community 10 - "Backend Anti-Theft Logic"
Cohesion: 0.15
Nodes (14): disableAntitheft(), dynamoService, enableAntitheft(), { generateCirclePolygon }, { GEOFENCE }, { LOCATION_TRACKER_NAME }, { locationClient }, locationService (+6 more)

### Community 11 - "Web Map Interface Components"
Cohesion: 0.10
Nodes (14): App(), Toast(), DeviceMarkers(), GeofenceManagement(), Header(), menuItems, Sidebar(), DevicesMapOverlay() (+6 more)

### Community 12 - "Backend Device Controller"
Cohesion: 0.32
Nodes (11): createDevice(), deleteDevice(), { DEVICE_TYPES, DEVICE_STATUSES }, dynamoService, getAllDevices(), getDeviceById(), getDeviceHistory(), getOwnerUserIdFromRequest() (+3 more)

### Community 13 - "Web Device Management UI"
Cohesion: 0.15
Nodes (9): ConfirmAntiTheftModal(), DeleteDeviceModal(), DEFAULT_FORM, DEVICE_STATUSES, DEVICE_TYPES, DeviceFormModal(), DeviceList(), STATUS_CONFIG (+1 more)

### Community 14 - "Mobile App Project Config"
Cohesion: 0.20
Nodes (9): devDependencies, eslint, eslint-config-expo, @types/react, typescript, main, name, private (+1 more)

### Community 15 - "Mobile App Component"
Cohesion: 0.22
Nodes (6): requestNotificationPermissions(), showAntitheftAlert(), showDeviceOfflineAlert(), showDeviceOnlineAlert(), showGeofenceAlert(), showLocalNotification()

### Community 16 - "Backend DynamoDB Services"
Cohesion: 0.14
Nodes (3): { DYNAMODB_DEVICES_TABLE }, { dynamoDBDocumentClient }, {
    PutCommand,
    GetCommand,
    UpdateCommand,
    DeleteCommand,
    ScanCommand,
    QueryCommand,
}

### Community 17 - "Web Map Interface Components"
Cohesion: 0.14
Nodes (8): antitheftApi, deviceApi, DashboardView(), PRESET_ROUTES, DeviceDetailPanel(), EVENT_ICONS, COGNITO, MAP

### Community 18 - "Mobile App Component"
Cohesion: 0.11
Nodes (12): LoginScreen(), NotificationTestScreen(), s, s, ScanScreen(), s, s, styles (+4 more)

### Community 19 - "Web Frontend Component"
Cohesion: 0.30
Nodes (10): useDeviceManager(), applyRealtimeEventToDevices(), createRealtimeEventTracker(), getRealtimeNotificationDescriptor(), isObject(), REALTIME_EVENT_SAMPLES, REALTIME_EVENT_TYPES, shouldProcessRealtimeEvent() (+2 more)

### Community 20 - "Geofence Event Consumer Lambda"
Cohesion: 0.36
Nodes (11): _call_webhook(), _debug_topic(), _decode_record_body(), _get_iot_data_client(), _get_owner_user_id(), lambda_handler(), _now_ms(), _parse_geofence_event() (+3 more)

### Community 21 - "Backend Utility/Simulation Scripts"
Cohesion: 0.22
Nodes (7): { DYNAMODB_DEVICES_TABLE }, { dynamoDBDocumentClient }, { ScanCommand, UpdateCommand }, awsConfig, { DynamoDBClient }, { DynamoDBDocumentClient }, { LocationClient }

### Community 22 - "Mobile App Geofence Screens"
Cohesion: 0.06
Nodes (22): App(), authHelpers, InfoBox(), Panel(), Spinner(), DrawControl(), DrawnGeofences(), polygons (+14 more)

### Community 23 - "Mobile App Auth Screens"
Cohesion: 0.17
Nodes (11): markOnboardingDone(), NotificationEffects(), RootLayout(), s, SLIDES, { width }, s, SettingsScreen() (+3 more)

### Community 24 - "Mobile App Auth Screens"
Cohesion: 0.35
Nodes (9): s, { width, height }, AuthEvents, authFetch(), cognitoConfirmSignUp(), cognitoResendCode(), cognitoSignIn(), cognitoSignUp() (+1 more)

### Community 25 - "Mobile App Navigation Tabs"
Cohesion: 0.21
Nodes (10): DeviceMarker, mapDarkStyle, MapScreen(), s, { width, height }, antitheftApi, apiFetch(), deviceApi (+2 more)

### Community 26 - "Backend Auth & Middleware"
Cohesion: 0.15
Nodes (5): client, {
    CognitoIdentityProviderClient,
    AdminInitiateAuthCommand,
    SignUpCommand,
    ConfirmSignUpCommand,
    ResendConfirmationCodeCommand,
}, auth, { Router }, AuthLayout()

### Community 27 - "Offline Detector Lambda"
Cohesion: 0.38
Nodes (9): _debug_topic(), _get_device_owner(), _get_iot_data_client(), _iso_now(), lambda_handler(), _now_ms(), _publish(), Any (+1 more)

### Community 28 - "Backend Location & Geo Services"
Cohesion: 0.18
Nodes (9): dynamoService, { haversineDistanceM }, locationService, runAntitheftCheck(), snsService, startAntitheftWorker(), haversineDistanceM(), snsClient (+1 more)

### Community 30 - "Backend Location & Geo Services"
Cohesion: 0.22
Nodes (3): {
    ListDevicePositionsCommand,
    BatchDeleteDevicePositionHistoryCommand,
    GetDevicePositionHistoryCommand,
}, { LOCATION_TRACKER_NAME }, { locationClient }

### Community 31 - "Mobile App Navigation Tabs"
Cohesion: 0.29
Nodes (3): CustomTabBar(), s, TABS

### Community 32 - "Mobile App Component"
Cohesion: 0.29
Nodes (6): compilerOptions, paths, strict, extends, include, @/*

### Community 33 - "Web Layout & Common UI"
Cohesion: 0.07
Nodes (50): boolean, byte, lockers, Print, Client, IPAddress, MQTT_CALLBACK_SIGNATURE, Client (+42 more)

### Community 34 - "Web Map Interface Components"
Cohesion: 0.50
Nodes (4): DeviceHistoryPathLayer(), getDistanceKm(), historyLineLayer, historyPointsLayer

### Community 35 - "Mobile App Component"
Cohesion: 0.40
Nodes (4): Colors, FontSize, Radius, Spacing

### Community 36 - "Backend SNS Notifications"
Cohesion: 0.05
Nodes (40): 10. Technology Stack, 11. References, 1. Project Overview, 2. Source Code Directory Structure, 3. System Architecture, 4. AWS Services Utilized, 5. System Workflows, 7. API Reference (+32 more)

### Community 37 - "Web Device Management UI"
Cohesion: 0.05
Nodes (37): 1. Permission Denied, 2. Invalid Position, 3. Tracker Not Found, CloudWatch Logs, CloudWatch Metrics, Common Issues, 💰 Cost Estimation, Current Configuration (+29 more)

### Community 50 - "Community 50"
Cohesion: 0.07
Nodes (27): 2.1. Clone the Repository, 2.2. Create an S3 Bucket for Lambda Artifacts, 2.3. Package the Template, 2.4. Expose the Local Webhook Port, 2.5. Deploy the Stack, 2.6. Confirm SNS Subscription, 2.7. Extract CloudFormation Outputs, 2.8. Create Location Service API Key (Mandatory) (+19 more)

### Community 51 - "Community 51"
Cohesion: 0.08
Nodes (24): For /graphify add and --watch, For /graphify query, For the commit hook and native CLAUDE.md integration, For --update and --cluster-only, /graphify, Honesty Rules, Interpreter guard for subcommands, Part A - Structural extraction for code files (+16 more)

### Community 52 - "Community 52"
Cohesion: 0.08
Nodes (24): For /graphify add and --watch, For /graphify query, For the commit hook and native CLAUDE.md integration, For --update and --cluster-only, /graphify, Honesty Rules, Interpreter guard for subcommands, Part A - Structural extraction for code files (+16 more)

### Community 53 - "Community 53"
Cohesion: 0.12
Nodes (16): Backend (`tracking-data-streaming-backend`), Deleting the Stack, Deployment Steps, Frontend (`tracking-data-streaming-datn`), Prerequisites, Stack Parameters, Step 1 — Create an S3 Bucket for artifacts, Step 2 — Package the stack (uploads Lambda code to S3) (+8 more)

### Community 54 - "Community 54"
Cohesion: 0.17
Nodes (11): API Endpoints, Bước 1: Tạo DynamoDB Table, Bước 2: Cấu hình credentials, Bước 3: Chạy server, Cấu trúc thư mục, GET /api/devices — Response, Kiến trúc, Option A: CloudFormation (khuyến nghị) (+3 more)

### Community 55 - "Community 55"
Cohesion: 0.17
Nodes (12): DevicesScreen(), FORM_TYPES, s, TYPES, getGreeting(), HomeScreen(), s, ConfirmModal() (+4 more)

### Community 56 - "Community 56"
Cohesion: 0.22
Nodes (8): graphify reference: extra exports and benchmark, Step 6b - Wiki (only if --wiki flag), Step 7 - Neo4j export (only if --neo4j or --neo4j-push flag), Step 7a - FalkorDB export (only if --falkordb or --falkordb-push flag), Step 7b - SVG export (only if --svg flag), Step 7c - GraphML export (only if --graphml flag), Step 7d - MCP server (only if --mcp flag), Step 8 - Token reduction benchmark (only if total_words > 5000)

### Community 57 - "Community 57"
Cohesion: 0.22
Nodes (8): graphify reference: extra exports and benchmark, Step 6b - Wiki (only if --wiki flag), Step 7 - Neo4j export (only if --neo4j or --neo4j-push flag), Step 7a - FalkorDB export (only if --falkordb or --falkordb-push flag), Step 7b - SVG export (only if --svg flag), Step 7c - GraphML export (only if --graphml flag), Step 7d - MCP server (only if --mcp flag), Step 8 - Token reduction benchmark (only if total_words > 5000)

### Community 58 - "Community 58"
Cohesion: 0.33
Nodes (5): For /graphify explain, For /graphify path, graphify reference: query, path, explain, Step 0 — Constrained query expansion (REQUIRED before traversal), Step 1 — Traversal

### Community 59 - "Community 59"
Cohesion: 0.33
Nodes (5): For /graphify explain, For /graphify path, graphify reference: query, path, explain, Step 0 — Constrained query expansion (REQUIRED before traversal), Step 1 — Traversal

### Community 61 - "Community 61"
Cohesion: 0.33
Nodes (6): scripts, android, ios, lint, start, web

### Community 62 - "Community 62"
Cohesion: 0.33
Nodes (5): Get a fresh project, Get started, Join the community, Learn more, Welcome to your Expo app 👋

### Community 63 - "Community 63"
Cohesion: 0.50
Nodes (3): For /graphify add, For --watch, graphify reference: add a URL and watch a folder

### Community 64 - "Community 64"
Cohesion: 0.50
Nodes (3): For git commit hook, For native CLAUDE.md integration, graphify reference: commit hook and native CLAUDE.md integration

### Community 65 - "Community 65"
Cohesion: 0.50
Nodes (3): For --cluster-only, For --update (incremental re-extraction), graphify reference: incremental update and cluster-only

### Community 66 - "Community 66"
Cohesion: 0.50
Nodes (3): For /graphify add, For --watch, graphify reference: add a URL and watch a folder

### Community 67 - "Community 67"
Cohesion: 0.50
Nodes (3): For git commit hook, For native CLAUDE.md integration, graphify reference: commit hook and native CLAUDE.md integration

### Community 68 - "Community 68"
Cohesion: 0.50
Nodes (3): For --cluster-only, For --update (incremental re-extraction), graphify reference: incremental update and cluster-only

### Community 69 - "Community 69"
Cohesion: 0.50
Nodes (3): Expanding the ESLint configuration, React Compiler, React + Vite

### Community 70 - "Community 70"
Cohesion: 0.10
Nodes (11): TinyGPSAltitude, TinyGPSCourse, TinyGPSDecimal, commit, lastCommitTime, newval, updated, val (+3 more)

### Community 80 - "Community 80"
Cohesion: 0.06
Nodes (29): Code of Conduct, Contributing Guidelines, Contributing via Pull Requests, Finding contributions to work on, Licensing, Reporting Bugs/Feature Requests, Security issue notifications, Clean up (+21 more)

### Community 81 - "Community 81"
Cohesion: 0.06
Nodes (31): dependencies, @aws/amazon-location-utilities-auth-helper, @aws-sdk/client-kinesis, @aws-sdk/client-location, @aws-sdk/client-sqs, @cloudscape-design/components, @cloudscape-design/global-styles, events (+23 more)

### Community 82 - "Community 82"
Cohesion: 0.07
Nodes (22): TinyGPSPlus, altitude, course, curSentenceType, curTermNumber, curTermOffset, customCandidates, customElts (+14 more)

### Community 83 - "Community 83"
Cohesion: 0.09
Nodes (22): AWS Account Requirements, Cleanup, Cost, Deployment Steps, Deployment Validation - IoT and Analytics Resources, Deployment Validation - Visualization Resources, Guidance for Tracking Assets & Locating Devices Using AWS IoT, Next Steps (+14 more)

### Community 84 - "Community 84"
Cohesion: 0.15
Nodes (8): TinyGPSInteger, commit, lastCommitTime, newval, set, updated, val, valid

### Community 85 - "Community 85"
Cohesion: 0.11
Nodes (18): 1. Mục tiêu \& output của dự án, 2. Kiến trúc tổng thể \& luồng dữ liệu, 3.1 Web visualization \& Amazon Location, 3.2 IoT Core Rule \& Lambda (cf/iotResources.yml), 3.3 Analytics stack: S3 + Firehose + EventBridge (cf/analyticsResources.yml), 3.4 Các service AWS khác trong giải pháp, 3. Thành phần \& service chi tiết, 4.1 Chuẩn bị môi trường (+10 more)

### Community 86 - "Community 86"
Cohesion: 0.08
Nodes (22): Quality, MODE, RawDegrees, billionths, deg, negative, TinyGPSLocation, commit (+14 more)

### Community 87 - "Community 87"
Cohesion: 0.11
Nodes (17): dependencies, @aws/amazon-location-utilities-auth-helper, maplibre-gl, react, react-dom, react-map-gl, devDependencies, vite (+9 more)

### Community 88 - "Community 88"
Cohesion: 0.11
Nodes (16): Code of Conduct, Contributing Guidelines, Contributing via Pull Requests, Finding contributions to work on, Licensing, Reporting Bugs/Feature Requests, Security issue notifications, Authentication Best Practice (+8 more)

### Community 89 - "Community 89"
Cohesion: 0.12
Nodes (16): dependencies, maplibre-gl, react, react-dom, react-map-gl, devDependencies, vite, @vitejs/plugin-react (+8 more)

### Community 91 - "Community 91"
Cohesion: 0.14
Nodes (11): TinyGPSCustom, buffer, lastCommitTime, next, sentenceName, set, stagingBuffer, termNumber (+3 more)

### Community 92 - "Community 92"
Cohesion: 0.12
Nodes (11): TinyGPSDate, commit, date, day, lastCommitTime, month, newDate, setDate (+3 more)

### Community 93 - "Community 93"
Cohesion: 0.10
Nodes (21): begin, commit, set, cardinal, courseTo, encode, endOfTermHandler, fromHex (+13 more)

### Community 94 - "Community 94"
Cohesion: 0.20
Nodes (9): 1. Tổng Quan Dự Án, 2. Kiến Trúc Hệ Thống, Công nghệ sử dụng, Guidance for Tracking Assets & Locating Devices Using AWS IoT, 📋 Hướng Dẫn Chi Tiết Triển Khai & Chi Phí Dự Án, Luồng dữ liệu chính, Mục Lục, Mục đích (+1 more)

### Community 96 - "Community 96"
Cohesion: 0.25
Nodes (7): Code of Conduct, Contributing Guidelines, Contributing via Pull Requests, Finding contributions to work on, Licensing, Reporting Bugs/Feature Requests, Security issue notifications

### Community 97 - "Community 97"
Cohesion: 0.25
Nodes (8): 3.2.1. [App.jsx](file:///d:/D22CQCI01N/7-%C4%90ATN/guidance-for-tracking-assets-and-locating-devices-using-aws-iot/amazon-location-samples-react/amazon-location-samples-react/tracking-data-streaming/src/App.jsx) — Root Component, 3.2.2. [GeofencesLayer.jsx](file:///d:/D22CQCI01N/7-%C4%90ATN/guidance-for-tracking-assets-and-locating-devices-using-aws-iot/amazon-location-samples-react/amazon-location-samples-react/tracking-data-streaming/src/components/geofences/GeofencesLayer.jsx) — Quản lý Geofences, 3.2.3. [TrackersLayer.jsx](file:///d:/D22CQCI01N/7-%C4%90ATN/guidance-for-tracking-assets-and-locating-devices-using-aws-iot/amazon-location-samples-react/amazon-location-samples-react/tracking-data-streaming/src/components/trackers/TrackersLayer.jsx) — Quản lý Trackers, 3.2.4. [Devices.jsx](file:///d:/D22CQCI01N/7-%C4%90ATN/guidance-for-tracking-assets-and-locating-devices-using-aws-iot/amazon-location-samples-react/amazon-location-samples-react/tracking-data-streaming/src/components/trackers/Devices.jsx) — Animated Markers, 3.2.5. [configuration.js](file:///d:/D22CQCI01N/7-%C4%90ATN/guidance-for-tracking-assets-and-locating-devices-using-aws-iot/amazon-location-samples-react/amazon-location-samples-react/tracking-data-streaming/src/configuration.js) — File cấu hình (CẦN SỬA), 3.2.6. [DemoData.js](file:///d:/D22CQCI01N/7-%C4%90ATN/guidance-for-tracking-assets-and-locating-devices-using-aws-iot/amazon-location-samples-react/amazon-location-samples-react/tracking-data-streaming/src/DemoData.js) — Dữ liệu demo, 3.2. Frontend React Application, Cấu trúc thư mục

### Community 98 - "Community 98"
Cohesion: 0.25
Nodes (8): 5. Hướng Dẫn Triển Khai Từng Bước, Bước 1: Clone Repository, Bước 2: Cài đặt Dependencies cho Frontend, Bước 3: Set Region & Deploy CloudFormation (Visualization Resources), Bước 4: Cấu Hình Frontend, Bước 5: Deploy IoT Resources Stack, Bước 6: Deploy Analytics Stack (Tùy chọn), Bước 7: Xác Nhận Triển Khai

### Community 100 - "Community 100"
Cohesion: 0.29
Nodes (7): 7.1. Bảng Chi Phí Theo Dịch Vụ (1 triệu location updates/tháng), 7.2. Phân Tích Chi Phí Theo Nhóm, 7.3. Ước Tính Theo Quy Mô Sử Dụng, 7.4. Chi Phí Bổ Sung Cần Lưu Ý, 7.5. Cách Giảm Chi Phí, 7.6. Chi Phí Free Tier (12 tháng đầu), 7. Chi Phí Triển Khai

### Community 101 - "Community 101"
Cohesion: 0.33
Nodes (6): 3.1. CloudFormation Templates (Infrastructure as Code), 3. Phân Tích Code Chi Tiết, Stack 1: [kinesisResources.yml](file:///d:/D22CQCI01N/7-%C4%90ATN/guidance-for-tracking-assets-and-locating-devices-using-aws-iot/amazon-location-samples-react/amazon-location-samples-react/tracking-data-streaming/src/cfn_template/kinesisResources.yml) — Kinesis Data Stream, Stack 2: [locationResources.yml](file:///d:/D22CQCI01N/7-%C4%90ATN/guidance-for-tracking-assets-and-locating-devices-using-aws-iot/amazon-location-samples-react/amazon-location-samples-react/tracking-data-streaming/src/cfn_template/locationResources.yml) — Location Service + Cognito + SQS, Stack 3: [iotResources.yml](file:///d:/D22CQCI01N/7-%C4%90ATN/guidance-for-tracking-assets-and-locating-devices-using-aws-iot/cf/iotResources.yml) — IoT Core + Lambda, Stack 4: [analyticsResources.yml](file:///d:/D22CQCI01N/7-%C4%90ATN/guidance-for-tracking-assets-and-locating-devices-using-aws-iot/cf/analyticsResources.yml) — Analytics (Tùy chọn)

### Community 102 - "Community 102"
Cohesion: 0.33
Nodes (5): Arduino Client for MQTT, Compatible Hardware, Examples, License, Limitations

### Community 104 - "Community 104"
Cohesion: 0.40
Nodes (5): 4.1. Phần mềm cần cài đặt, 4.2. AWS Account Requirements, 4.3. AWS CLI Configuration, 4.4. Supported Regions, 4. Yêu Cầu Tiên Quyết

### Community 105 - "Community 105"
Cohesion: 0.50
Nodes (4): 6.1. Khởi chạy Web App, 6.2. Chạy Demo, 6.3. Gửi vị trí thủ công qua MQTT, 6. Cấu Hình & Chạy Ứng Dụng

### Community 106 - "Community 106"
Cohesion: 0.50
Nodes (4): 9.1. Lỗi thường gặp, 9.2. Kiểm tra logs, 9.3. Giới hạn dịch vụ, 9. Xử Lý Sự Cố

### Community 111 - "Community 111"
Cohesion: 0.67
Nodes (3): 8. Dọn Dẹp Tài Nguyên, Thứ tự xoá:, Verify xoá thành công:

## Knowledge Gaps
- **730 isolated node(s):** `solutionid_validator.sh script`, `name`, `private`, `version`, `type` (+725 more)
  These have ≤1 connection - possible missing edges or undocumented components.
- **23 thin communities (<3 nodes) omitted from report** — run `graphify query` to explore isolated nodes.

## Suggested Questions
_Questions this graph is uniquely positioned to answer:_

- **Why does `millis()` connect `Web Layout & Common UI` to `Community 70`, `Community 84`, `Community 86`, `Community 91`, `Community 92`, `Community 93`?**
  _High betweenness centrality (0.112) - this node is a cross-community bridge._
- **Why does `TinyGPSLocation` connect `Community 86` to `Community 82`, `Community 70`?**
  _High betweenness centrality (0.085) - this node is a cross-community bridge._
- **What connects `solutionid_validator.sh script`, `name`, `private` to the rest of the system?**
  _735 weakly-connected nodes found - possible documentation gaps or missing edges._
- **Should `Backend Auth & Middleware` be split into smaller, more focused modules?**
  _Cohesion score 0.05217391304347826 - nodes in this community are weakly interconnected._
- **Should `Web Frontend Project Config` be split into smaller, more focused modules?**
  _Cohesion score 0.05263157894736842 - nodes in this community are weakly interconnected._
- **Should `Mobile App Dependencies` be split into smaller, more focused modules?**
  _Cohesion score 0.05405405405405406 - nodes in this community are weakly interconnected._
- **Should `Backend Config & Packages` be split into smaller, more focused modules?**
  _Cohesion score 0.05555555555555555 - nodes in this community are weakly interconnected._

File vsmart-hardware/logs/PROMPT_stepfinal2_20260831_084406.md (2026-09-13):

Xoay vật lý module A7680C U4 180 độ để khe SIM nằm phía trên như module thật, giữ nguyên pad-net/pinout; reroute GPS_RX và xác nhận DRC sạch.

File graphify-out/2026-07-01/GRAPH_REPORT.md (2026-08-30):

# Graph Report - .  (2026-07-01)

## Corpus Check
- Large corpus: 146 files · ~1,093,101 words. Semantic extraction will be expensive (many Claude tokens). Consider running on a subfolder.

## Summary
- 626 nodes · 866 edges · 50 communities (42 shown, 8 thin omitted)
- Extraction: 100% EXTRACTED · 0% INFERRED · 0% AMBIGUOUS
- Token cost: 0 input · 0 output

## Community Hubs (Navigation)
- [[_COMMUNITY_Backend Auth & Middleware|Backend Auth & Middleware]]
- [[_COMMUNITY_Mobile App Device & Scan|Mobile App Device & Scan]]
- [[_COMMUNITY_Web Frontend Project Config|Web Frontend Project Config]]
- [[_COMMUNITY_Mobile App Dependencies|Mobile App Dependencies]]
- [[_COMMUNITY_Backend Config & Packages|Backend Config & Packages]]
- [[_COMMUNITY_Mobile App Android Resources|Mobile App Android Resources]]
- [[_COMMUNITY_Web Geofencing UI|Web Geofencing UI]]
- [[_COMMUNITY_IoT Message Processor Lambda|IoT Message Processor Lambda]]
- [[_COMMUNITY_Mobile App Geofence Screens|Mobile App Geofence Screens]]
- [[_COMMUNITY_Backend UtilitySimulation Scripts|Backend Utility/Simulation Scripts]]
- [[_COMMUNITY_Backend Anti-Theft Logic|Backend Anti-Theft Logic]]
- [[_COMMUNITY_Web Map Interface Components|Web Map Interface Components]]
- [[_COMMUNITY_Backend Device Controller|Backend Device Controller]]
- [[_COMMUNITY_Web Device Management UI|Web Device Management UI]]
- [[_COMMUNITY_Mobile App Project Config|Mobile App Project Config]]
- [[_COMMUNITY_Mobile App Component|Mobile App Component]]
- [[_COMMUNITY_Backend DynamoDB Services|Backend DynamoDB Services]]
- [[_COMMUNITY_Web Map Interface Components|Web Map Interface Components]]
- [[_COMMUNITY_Mobile App Component|Mobile App Component]]
- [[_COMMUNITY_Web Frontend Component|Web Frontend Component]]
- [[_COMMUNITY_Geofence Event Consumer Lambda|Geofence Event Consumer Lambda]]
- [[_COMMUNITY_Backend UtilitySimulation Scripts|Backend Utility/Simulation Scripts]]
- [[_COMMUNITY_Mobile App Geofence Screens|Mobile App Geofence Screens]]
- [[_COMMUNITY_Mobile App Auth Screens|Mobile App Auth Screens]]
- [[_COMMUNITY_Mobile App Auth Screens|Mobile App Auth Screens]]
- [[_COMMUNITY_Mobile App Navigation Tabs|Mobile App Navigation Tabs]]
- [[_COMMUNITY_Backend Auth & Middleware|Backend Auth & Middleware]]
- [[_COMMUNITY_Offline Detector Lambda|Offline Detector Lambda]]
- [[_COMMUNITY_Backend Location & Geo Services|Backend Location & Geo Services]]
- [[_COMMUNITY_Web Geofencing UI|Web Geofencing UI]]
- [[_COMMUNITY_Backend Location & Geo Services|Backend Location & Geo Services]]
- [[_COMMUNITY_Mobile App Navigation Tabs|Mobile App Navigation Tabs]]
- [[_COMMUNITY_Mobile App Component|Mobile App Component]]
- [[_COMMUNITY_Web Layout & Common UI|Web Layout & Common UI]]
- [[_COMMUNITY_Web Map Interface Components|Web Map Interface Components]]
- [[_COMMUNITY_Mobile App Component|Mobile App Component]]
- [[_COMMUNITY_Backend SNS Notifications|Backend SNS Notifications]]
- [[_COMMUNITY_Web Device Management UI|Web Device Management UI]]
- [[_COMMUNITY_Backend UtilitySimulation Scripts|Backend Utility/Simulation Scripts]]
- [[_COMMUNITY_Backend UtilitySimulation Scripts|Backend Utility/Simulation Scripts]]
- [[_COMMUNITY_Realtime Event Publisher Lambda|Realtime Event Publisher Lambda]]
- [[_COMMUNITY_Mobile App Component|Mobile App Component]]
- [[_COMMUNITY_Mobile App Component|Mobile App Component]]

## God Nodes (most connected - your core abstractions)
1. `useToast()` - 22 edges
2. `expo` - 15 edges
3. `lambda_handler()` - 12 edges
4. `lambda_handler()` - 10 edges
5. `useLiveDevices()` - 9 edges
6. `lambda_handler()` - 8 edges
7. `getOwnerUserIdFromRequest()` - 7 edges
8. `App()` - 6 edges
9. `android` - 6 edges
10. `scripts` - 6 edges

## Surprising Connections (you probably didn't know these)
- `GeofencesScreen()` --calls--> `useToast()`  [EXTRACTED]
  vsmart-app/app/(tabs)/geofences.jsx → vsmart-app/src/components/ui/Toast.jsx
- `RootLayout()` --calls--> `useAuth()`  [EXTRACTED]
  vsmart-app/app/_layout.jsx → vsmart-app/src/hooks/useAuth.js
- `App()` --calls--> `useDeviceManager()`  [EXTRACTED]
  tracking-data-streaming-datn/src/App.jsx → tracking-data-streaming-datn/src/hooks/useDeviceManager.js
- `App()` --calls--> `useDevicePolling()`  [EXTRACTED]
  tracking-data-streaming-datn/src/App.jsx → tracking-data-streaming-datn/src/hooks/useDevicePolling.js
- `DevicesScreen()` --calls--> `useToast()`  [EXTRACTED]
  vsmart-app/app/(tabs)/devices.jsx → vsmart-app/src/components/ui/Toast.jsx

## Import Cycles
- 1-file cycle: `vsmart-app/metro.config.js -> vsmart-app/metro.config.js`

## Communities (50 total, 8 thin omitted)

### Community 0 - "Backend Auth & Middleware"
Cohesion: 0.06
Nodes (31): antitheftRoutes, app, {
    APP_EVENTS_TOPIC_TEMPLATE,
    DEBUG_DEVICE_EVENTS_TOPIC_TEMPLATE,
    RAW_TELEMETRY_TOPIC_TEMPLATE,
    REALTIME_EVENT_TYPES,
    REALTIME_SCHEMA_VERSION,
    SAMPLE_REALTIME_EVENTS,
    validateRealtimeEnvelope,
}, authRoutes, cors, deviceRoutes, { errorHandler, notFoundHandler }, express (+23 more)

### Community 1 - "Mobile App Device & Scan"
Cohesion: 0.09
Nodes (30): DeviceMarker, mapDarkStyle, MapScreen(), s, { width, height }, DevicesScreen(), FORM_TYPES, s (+22 more)

### Community 2 - "Web Frontend Project Config"
Cohesion: 0.05
Nodes (37): dependencies, @aws/amazon-location-utilities-auth-helper, aws-amplify, @aws-sdk/client-location, @aws-sdk/client-sqs, @aws-sdk/credential-providers, clsx, lucide-react (+29 more)

### Community 3 - "Mobile App Dependencies"
Cohesion: 0.05
Nodes (37): dependencies, @aws/amazon-location-utilities-auth-helper, @aws-sdk/client-location, @aws-sdk/credential-providers, babel-preset-expo, buffer, expo, expo-camera (+29 more)

### Community 4 - "Backend Config & Packages"
Cohesion: 0.06
Nodes (35): author, dependencies, aws-jwt-verify, @aws-sdk/client-cognito-identity-provider, @aws-sdk/client-dynamodb, @aws-sdk/client-iot, @aws-sdk/client-iot-data-plane, @aws-sdk/client-location (+27 more)

### Community 5 - "Mobile App Android Resources"
Cohesion: 0.06
Nodes (35): backgroundColor, foregroundImage, adaptiveIcon, edgeToEdgeEnabled, package, permissions, predictiveBackGestureEnabled, reactCompiler (+27 more)

### Community 6 - "Web Geofencing UI"
Cohesion: 0.12
Nodes (10): DrawControl(), DrawnGeofences(), polygons, polygonsBorders, polygonsBreached, polygonsBreachedBorders, CIRCLE_STEPS, draw (+2 more)

### Community 7 - "IoT Message Processor Lambda"
Cohesion: 0.19
Nodes (19): batch_update_multiple_devices(), build_location_update(), _call_webhook(), _debug_topic(), _get_device_metadata(), _get_device_state(), _get_iot_data_client(), lambda_handler() (+11 more)

### Community 8 - "Mobile App Geofence Screens"
Cohesion: 0.17
Nodes (9): MODE, s, GeofencesScreen(), s, TEMPLATES, GeofenceDataContext, authHelpers, createLocationClient() (+1 more)

### Community 9 - "Backend Utility/Simulation Scripts"
Cohesion: 0.13
Nodes (11): getIotDataClient(), iotClient, { IoTClient, DescribeEndpointCommand }, { IoTDataPlaneClient, PublishCommand }, publishTelemetry(), readline, rl, sqsClient (+3 more)

### Community 10 - "Backend Anti-Theft Logic"
Cohesion: 0.15
Nodes (14): disableAntitheft(), dynamoService, enableAntitheft(), { generateCirclePolygon }, { GEOFENCE }, { LOCATION_TRACKER_NAME }, { locationClient }, locationService (+6 more)

### Community 11 - "Web Map Interface Components"
Cohesion: 0.16
Nodes (9): AuthLayout(), Toast(), Header(), menuItems, Sidebar(), DevicesMapOverlay(), STATUS_CONFIG, TYPE_CONFIG (+1 more)

### Community 12 - "Backend Device Controller"
Cohesion: 0.21
Nodes (14): createDevice(), deleteDevice(), { DEVICE_TYPES, DEVICE_STATUSES }, dynamoService, getAllDevices(), getDeviceById(), getDeviceHistory(), getOwnerUserIdFromRequest() (+6 more)
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

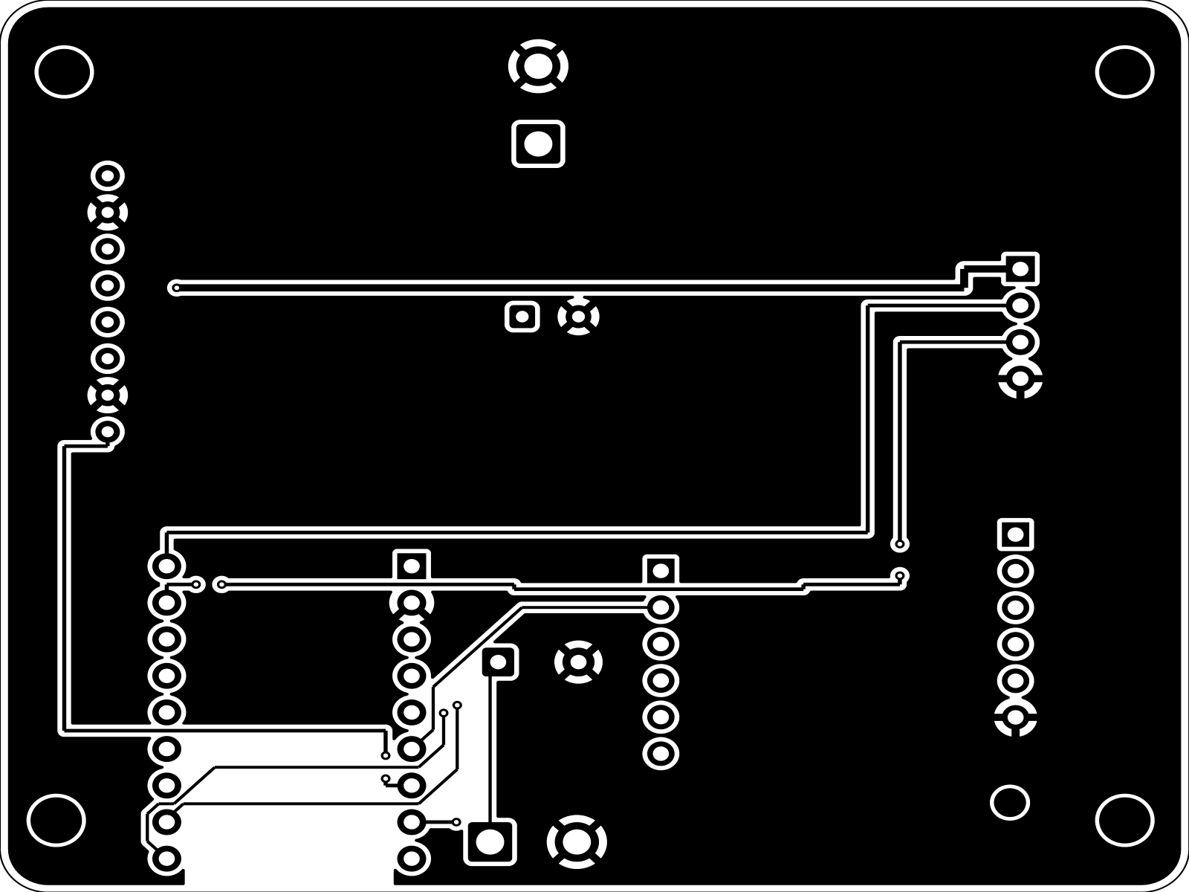
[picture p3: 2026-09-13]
vsmart-hardware/vsmart-module-esp32-s3-mini_2d_view.png

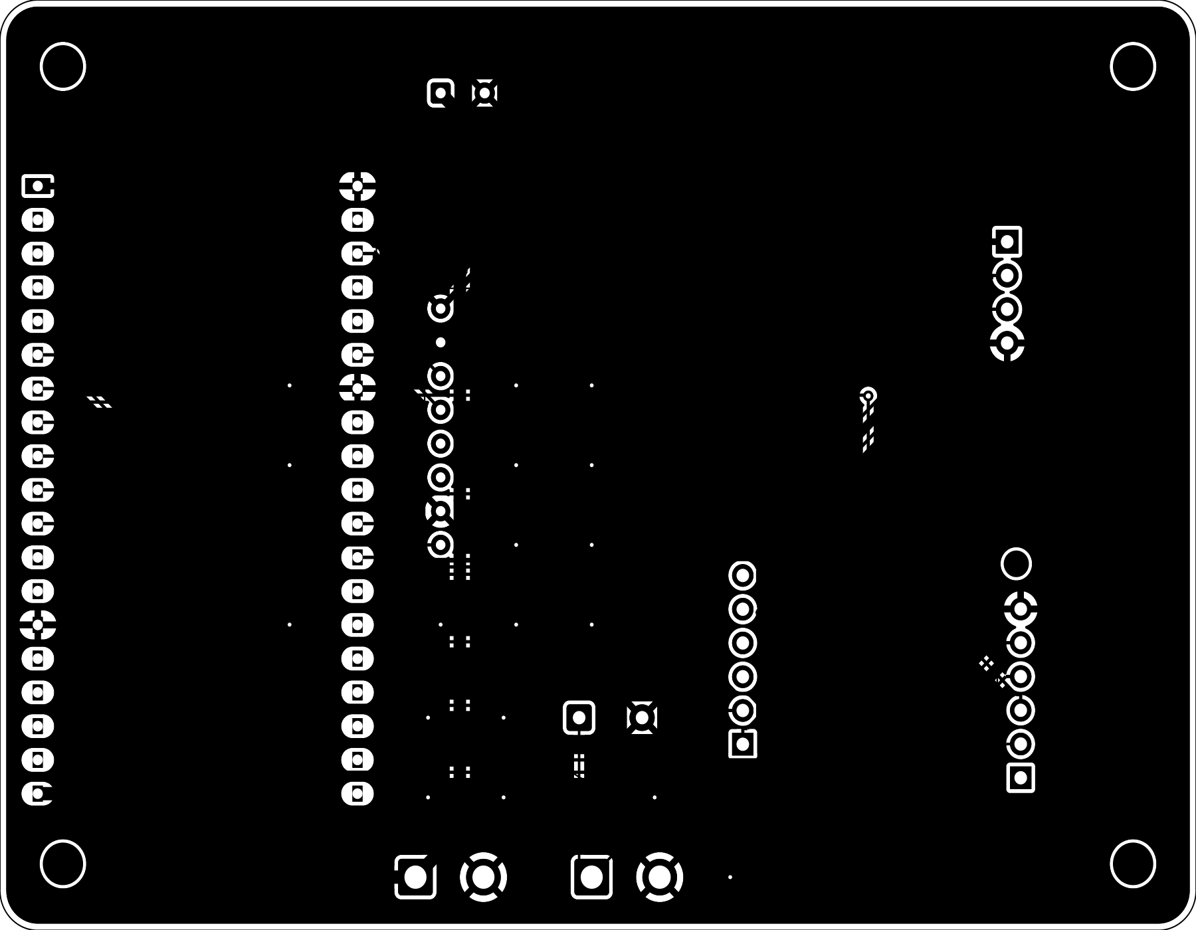
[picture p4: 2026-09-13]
vsmart-module-esp32/vsmart-module-carrier_2d_view.png

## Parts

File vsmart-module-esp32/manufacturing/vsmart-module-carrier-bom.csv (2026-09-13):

Reference | Value | Footprint | QUANTITY
C1 | 1000uF/16V LOW-ESR | Capacitor_THT:CP_Radial_D10.0mm_P5.00mm | 1
C3 | 470uF/10V | Capacitor_THT:CP_Radial_D8.0mm_P3.50mm | 1
J1 | EXTERNAL 5V INPUT | Connector_Wire:SolderWire-1sqmm_1x02_P5.4mm_D1.4mm_OD2.7mm | 1
J2 | EXTERNAL 5V 2A SIM INPUT | Connector_Wire:SolderWire-1sqmm_1x02_P5.4mm_D1.4mm_OD2.7mm | 1
U1 | ESP32-DevKitC 38-pin | Espressif:ESP32-DevKitC | 1
U2 | MPU6050 GY-521 MODULE | usini_sensors:module_mpu6050 | 1
U3 | GPS NEO-7M GY-GPSU3 | VSmart_Modules:GY-GPSU3-NEO7M | 1
U4 | A7680C TDM2309 4G | TDM_4G_V1:TDM-4G-V1 | 1

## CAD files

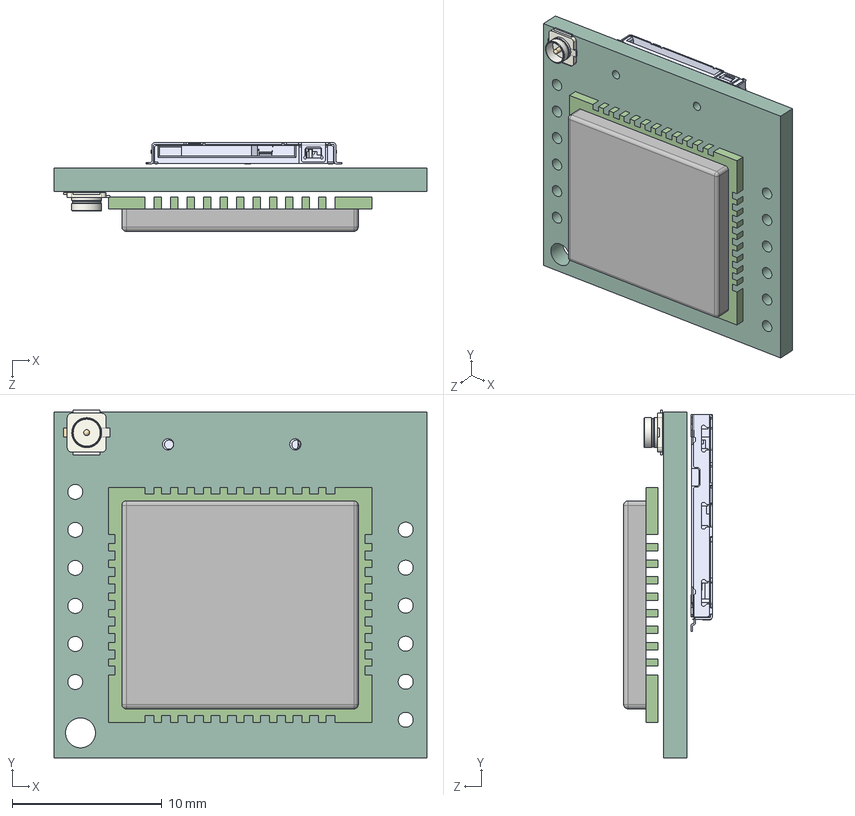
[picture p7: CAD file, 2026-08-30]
vsmart-hardware/3dmodels/TDM-4G-V1-3D.STEP
24.9 x 23.2 x 5.93 mm

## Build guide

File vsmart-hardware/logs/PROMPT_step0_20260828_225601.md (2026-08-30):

Checkpoint before replacing ESP32-DevKitC with ESP32-S3 SuperMini and renaming the project.

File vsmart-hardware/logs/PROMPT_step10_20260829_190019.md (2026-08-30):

Final release candidate: DRC 0, Gerber 7 layers + 2 drill files validated, revision mark added, final fabrication ZIP regenerated.

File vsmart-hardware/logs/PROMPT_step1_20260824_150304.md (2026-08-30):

Carrier PCB for ESP32-DevKitC 38-pin, MPU6050 GY-521, Keyestudio KS0319 NEO-7M, A7680C TDM2309, dual LM2596 modules. ERC clean.

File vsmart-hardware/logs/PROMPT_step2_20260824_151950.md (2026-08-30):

Completed 140x90mm two-layer module carrier. Routed all 16 nets using netclasses: 4V_SIM 2mm, VIN_12V 1.5mm, 5V/GND 1mm, 3V3 0.5mm, signals 0.25mm. Dual GND planes and 35 stitching vias. ERC 0, DRC 0 errors, 0 unconnected, placement clear. Manufacturing outputs exported.

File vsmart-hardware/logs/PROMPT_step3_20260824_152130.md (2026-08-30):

Final manufacturing checkpoint after silkscreen cleanup. ERC 0. DRC 0 errors, 61 cosmetic/library warnings, 0 unconnected. Gerber/drill/BOM/position ZIP, PDFs, STEP and 3D PNG exported.

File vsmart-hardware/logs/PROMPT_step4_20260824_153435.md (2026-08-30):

Checkpoint before replacing on-board LM2596 module footprints with two external buck-output solder-wire connectors and shrinking PCB.

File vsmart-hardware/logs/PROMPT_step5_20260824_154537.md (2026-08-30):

Rev B: remove on-board LM2596 modules, add external 5V and 4V_SIM solder-wire inputs, compact PCB layout, reroute, add GND pours/stitching vias, verify ERC/DRC, and regenerate fabrication outputs.

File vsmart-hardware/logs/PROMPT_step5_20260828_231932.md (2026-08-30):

Thiết kế lại project dùng ESP32-S3 SuperMini, giữ các module MPU6050, GPS NEO-7M, A7680C và hai đầu nguồn ngoài 5V/4V; đổi tên toàn bộ project, tạo PCB mới, route, GND pours, antenna keepout, DRC/ERC và xuất file chế tạo.

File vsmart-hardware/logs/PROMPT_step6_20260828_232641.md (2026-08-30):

Giữ nguyên toàn bộ tụ C1, C2, C3 và tối ưu lại bố trí PCB từ 96x76 mm xuống 86x70 mm cho cân đối, đẹp hơn.

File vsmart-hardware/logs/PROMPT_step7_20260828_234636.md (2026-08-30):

Thay GPS KS0319 bằng module GY-GPSU3-NEO 4 chân (ăng-ten rời u.FL), tối ưu lại vị trí linh kiện, phục hồi ground plane và sửa các lỗi audit.

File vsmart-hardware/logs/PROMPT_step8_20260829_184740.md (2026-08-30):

Kiểm tra, phân tích và tối ưu PCB ESP32-S3 Mini trước khi gửi sản xuất.

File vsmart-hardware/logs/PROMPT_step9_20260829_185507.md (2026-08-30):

PCB optimized: clean silkscreen, explicit power junctions, shortened 4V SIM path, GPS return via, DRC clean.

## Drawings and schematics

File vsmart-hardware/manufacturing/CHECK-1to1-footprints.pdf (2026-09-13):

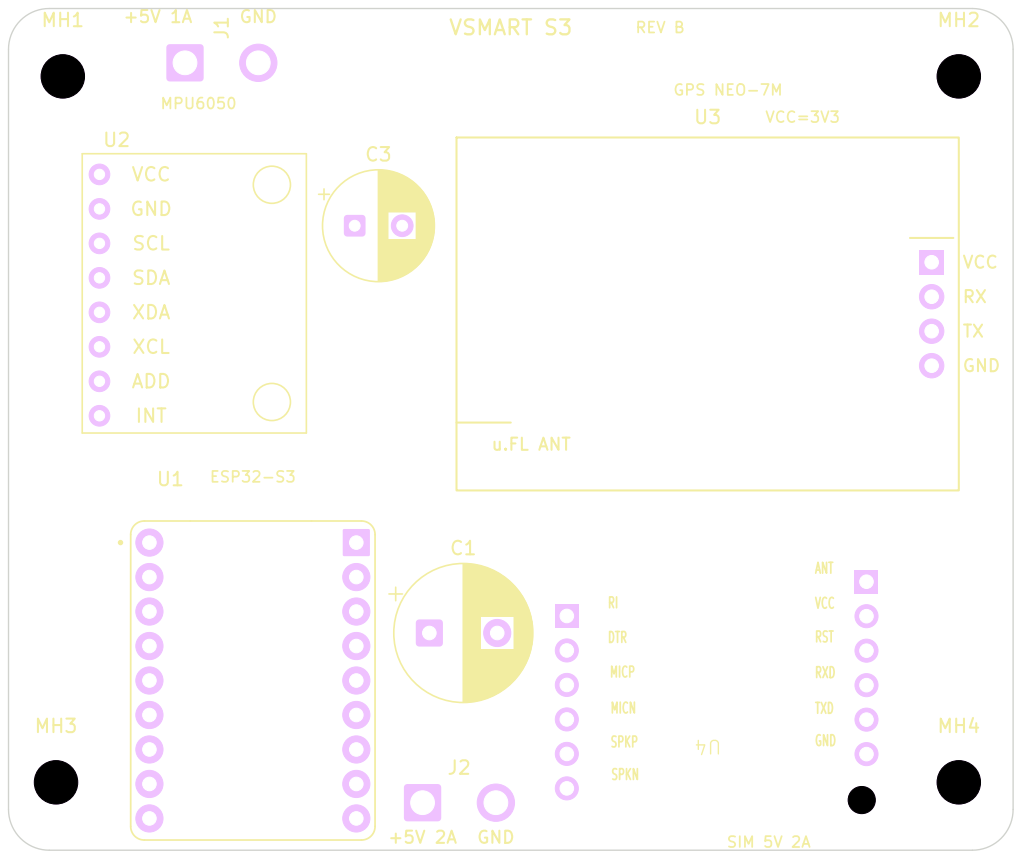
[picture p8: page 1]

VCC
GND
SCL SDA XDA XCL ADD

RI DTR MICP MICN

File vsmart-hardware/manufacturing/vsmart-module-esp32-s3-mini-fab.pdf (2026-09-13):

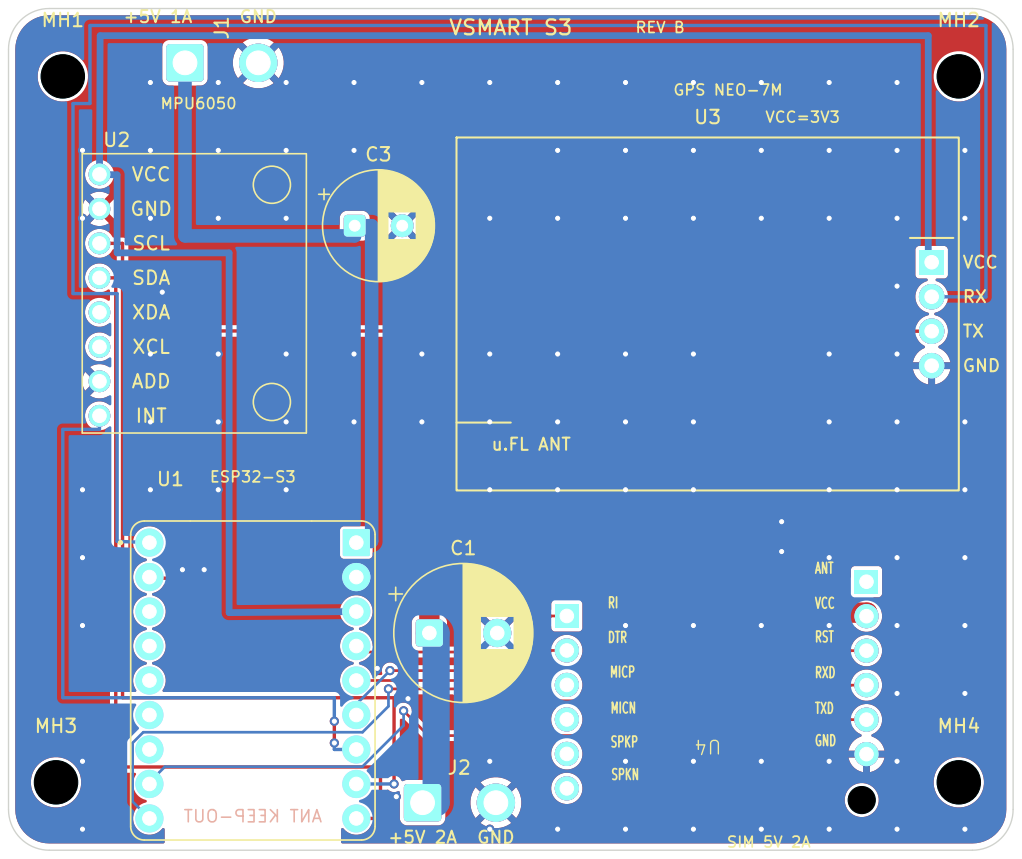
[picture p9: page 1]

VCC
GND
SCL SDA XDA XCL ADD

RI DTR MICP MICN

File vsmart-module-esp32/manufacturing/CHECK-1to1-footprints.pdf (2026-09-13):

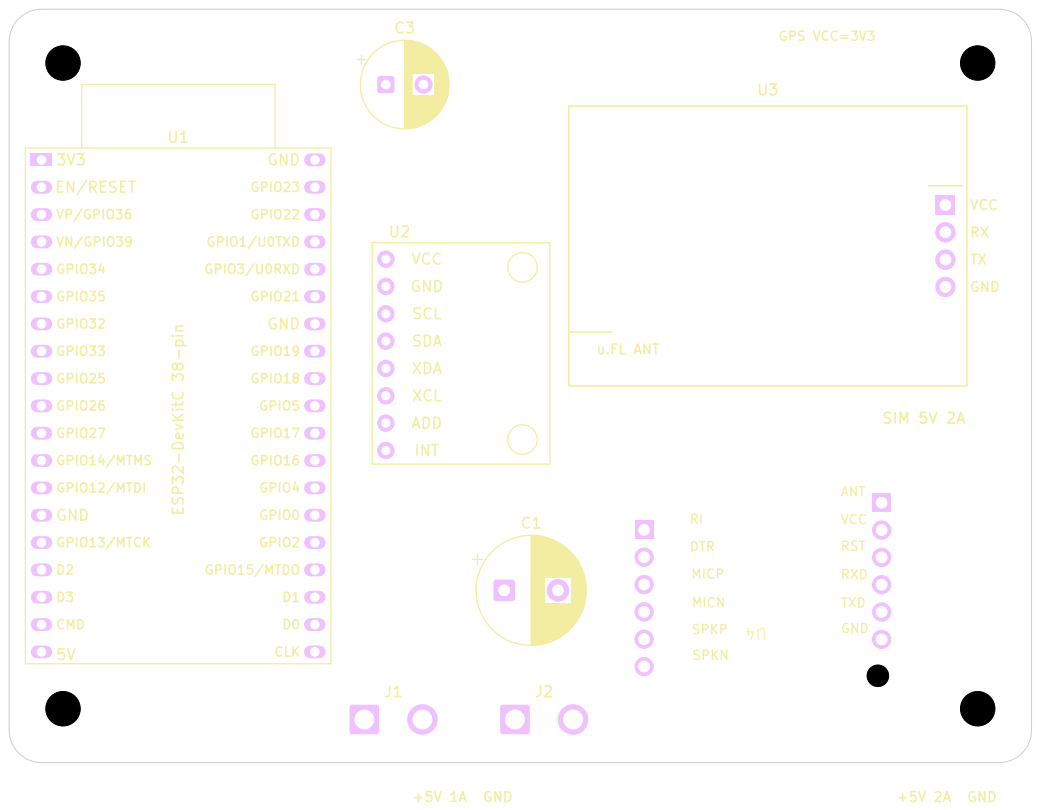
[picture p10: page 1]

VN/GPIO39 GPIO34 GPIO35 GPIO32 GPIO33 GPIO25 GPIO26 GPIO27 GPIO14/MTMS GPIO12/MTDI GND
GPIO19 GPIO18 GPIO5 GPIO17 GPIO16 GPIO4 GPIO0 GPIO2 GPIO15/MTDO

GND U2
VCC
GND
SCL SDA XDA XCL ADD

RI DTR MICP MICN

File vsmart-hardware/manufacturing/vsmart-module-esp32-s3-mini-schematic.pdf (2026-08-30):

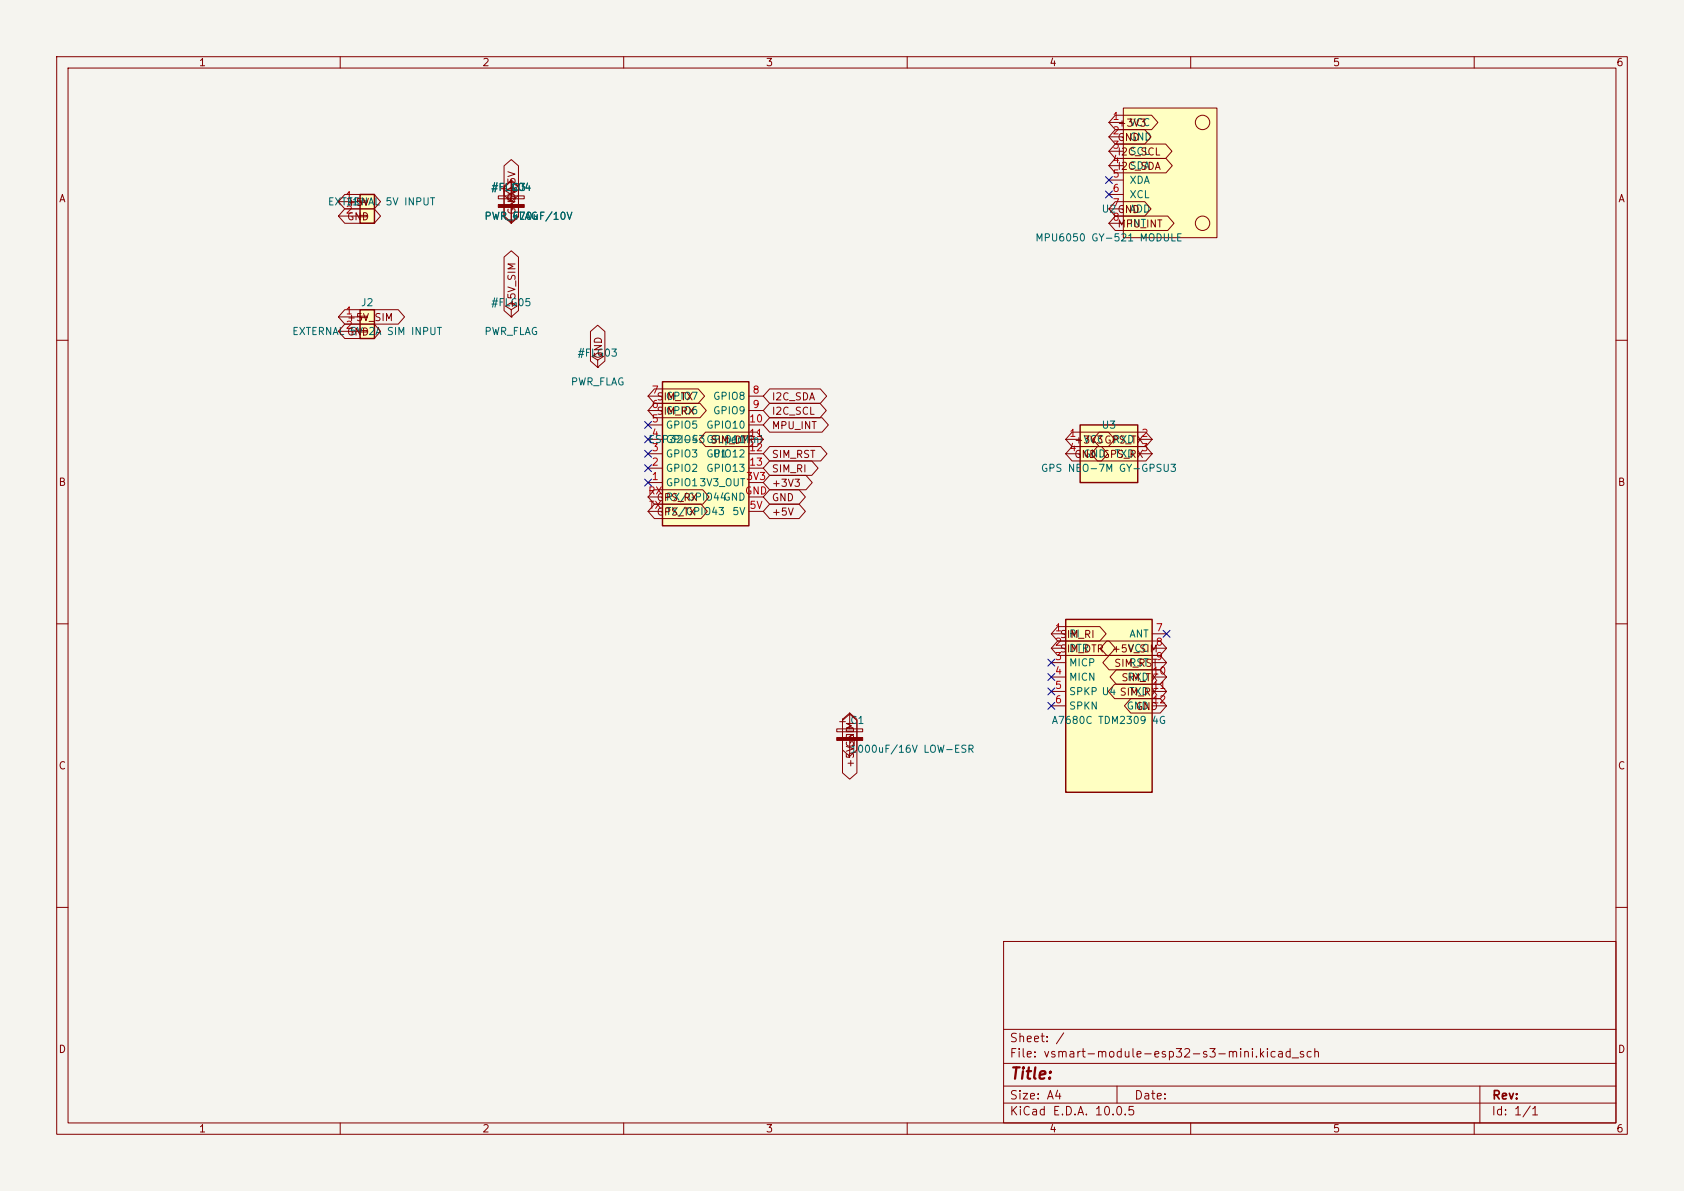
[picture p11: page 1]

Sheet: /
File: vsmart-module-esp32-s3-mini.kicad_sch
Title:

Size: A4 | Rev:
KiCad E.D.A. 10.0.5 | Id: 1/1

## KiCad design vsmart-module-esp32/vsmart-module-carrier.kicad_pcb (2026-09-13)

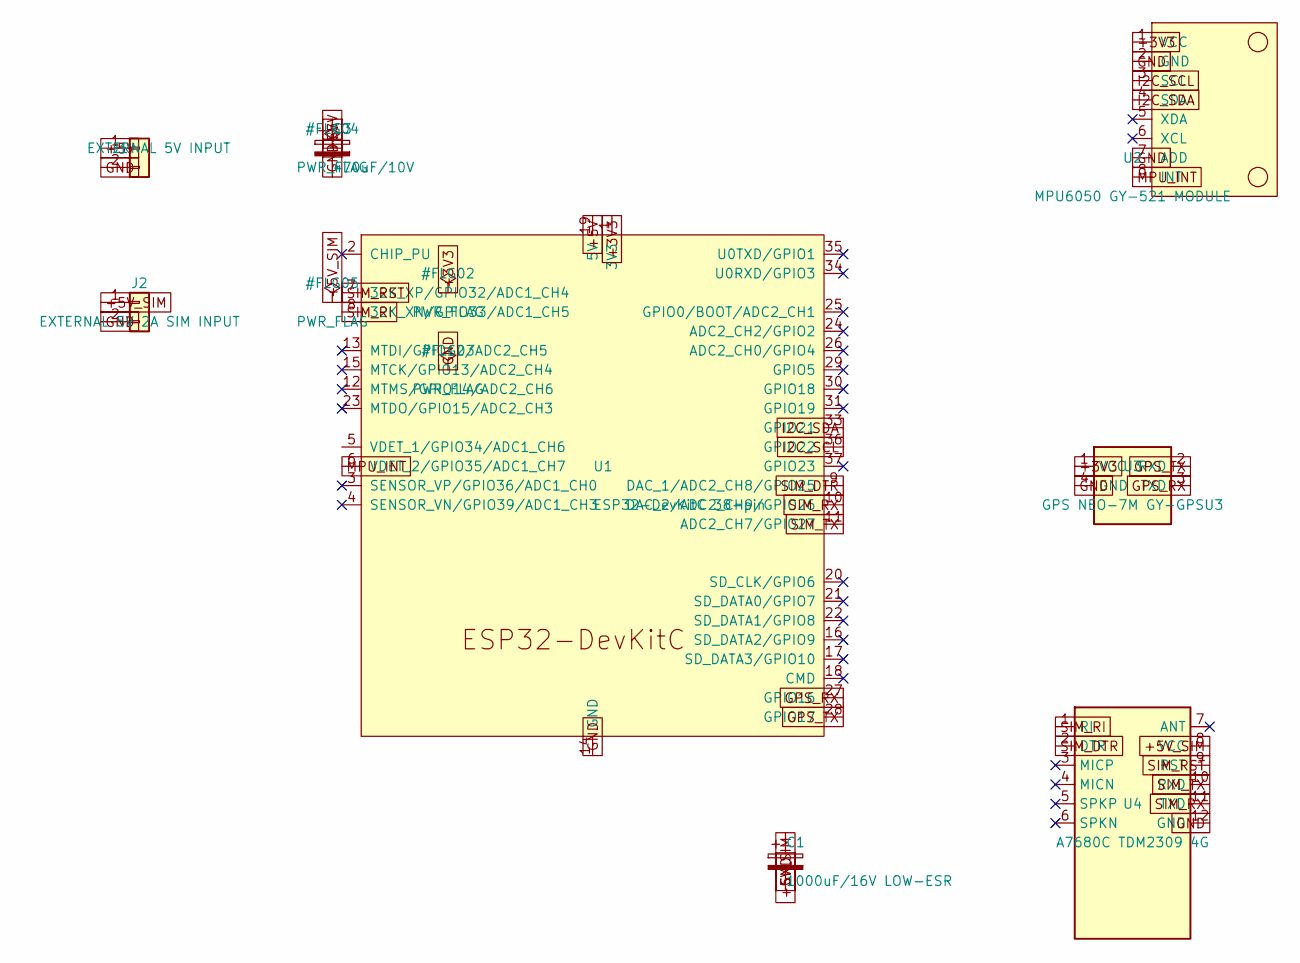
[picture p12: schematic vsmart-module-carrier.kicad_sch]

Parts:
C1: 1000uF/16V LOW-ESR; CP_Radial_D10.0mm_P5.00mm
C3: 470uF/10V; CP_Radial_D8.0mm_P3.50mm
J1: EXTERNAL 5V INPUT; SolderWire-1sqmm_1x02_P5.4mm_D1.4mm_OD2.7mm
J2: EXTERNAL 5V 2A SIM INPUT; SolderWire-1sqmm_1x02_P5.4mm_D1.4mm_OD2.7mm
U1: ESP32-DevKitC 38-pin; ESP32-DevKitC
U2: MPU6050 GY-521 MODULE; module_mpu6050
U3: GPS NEO-7M GY-GPSU3; GY-GPSU3-NEO7M
U4: A7680C TDM2309 4G; TDM-4G-V1

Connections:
+3V3: U1.1 (3V3), U2.1 (VCC), U3.1 (VCC)
+5V: C3.1, J1.1, U1.19 (5V)
+5V_SIM: C1.1, J2.1, U4.8 (VCC)
GND: C1.2, C3.2, J1.2, J2.2, U1.14 (GND), U1.32 (GND), U1.38 (GND), U2.2 (GND), U2.7 (ADD), U3.4 (GND), U4.12 (GND)
GPS_RX: U1.27 (GPIO16), U3.3 (TXD)
GPS_TX: U1.28 (GPIO17), U3.2 (RXD)
I2C_SCL: U1.36 (GPIO22), U2.3 (SCL)
I2C_SDA: U1.33 (GPIO21), U2.4 (SDA)
MPU_INT: U1.6 (VDET_2/GPIO35/ADC1_CH7), U2.8 (INT)
SIM_DTR: U1.9 (DAC_1/ADC2_CH8/GPIO25), U4.2 (DTR)
SIM_RI: U1.8 (32K_XN/GPIO33/ADC1_CH5), U4.1 (RI)
SIM_RST: U1.7 (32K_XP/GPIO32/ADC1_CH4), U4.9 (RST)
SIM_RX: U1.10 (DAC_2/ADC2_CH9/GPIO26), U4.11 (TXD)
SIM_TX: U1.11 (ADC2_CH7/GPIO27), U4.10 (RXD)

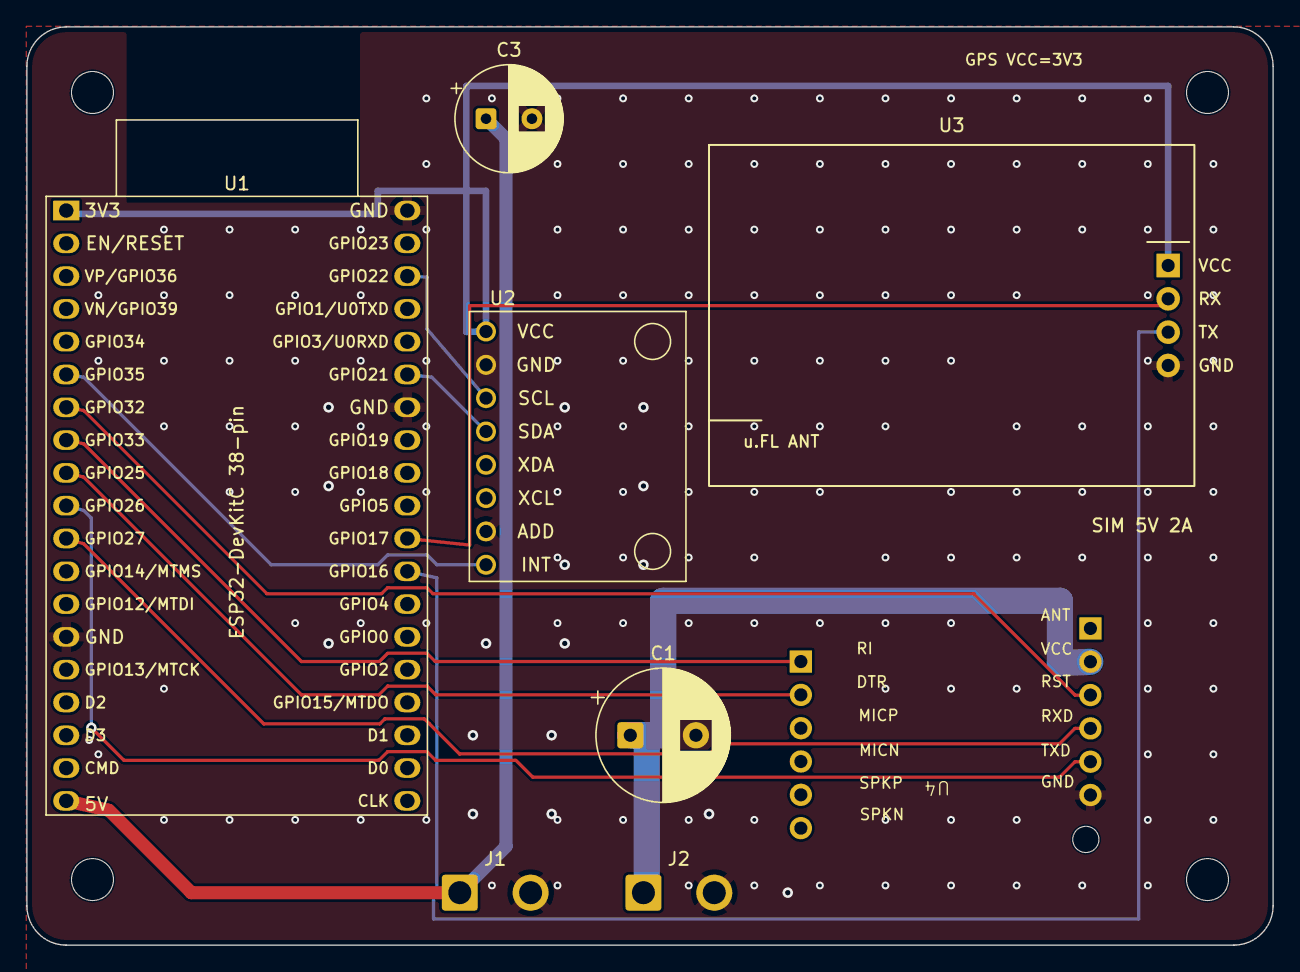
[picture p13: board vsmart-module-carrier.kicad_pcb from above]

Board: 2 copper layers, 95.0 x 70.0 mm, 12 parts (0 on the bottom side), 14 nets.

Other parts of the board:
MH1, MH2, MH3, MH4: MountingHole_3.2mm_M3

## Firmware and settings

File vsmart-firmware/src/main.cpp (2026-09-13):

#include <Arduino.h>
#include <Commands.h>
#include <esp_idf_version.h>
#include <esp_system.h>
#include <esp_task_wdt.h>

#include <Board.h>
#include <Cloud.h>
#include <Gps.h>
#include <Log.h>
#include <Telemetry.h>

#include "app_config.h"
#include "secrets.h"

static const char *TAG = "main";

static unsigned long lastTickMs = 0;
static unsigned long lastStatusMs = 0;
static unsigned long lastGgaMs = 0;
static bool commandSubscribed = false;
static uint32_t commandSession = 0;
static unsigned long lastSubscribeMs = 0;

static void onCloudMessage(const char *topic, const char *payload) {
    LOGI(TAG, "Received on %s: %s", topic, payload);

    char expected[128];
    snprintf(expected, sizeof(expected), TOPIC_DEVICE_CMD_FMT, VSMART_DEVICE_ID);
    if (strcmp(topic, expected) != 0)
        return;
    DeviceCommand command = parseDeviceCommand(payload);
    if (command == DeviceCommand::Reboot) {
        LOGW(TAG, "Cloud requested a reboot");
        delay(200);
        esp_restart();
    } else if (command == DeviceCommand::Ping) {
        Telemetry.publishNow("cloud_ping");
    } else {
        LOGW(TAG, "Unknown command");
    }
}

static void subscribeAll() {
    char topic[128];
    snprintf(topic, sizeof(topic), TOPIC_DEVICE_CMD_FMT, VSMART_DEVICE_ID);
    commandSubscribed = Cloud.subscribe(topic);
    commandSession = Cloud.session();
    lastSubscribeMs = millis();
    if (commandSubscribed)
        LOGI(TAG, "Subscription requested: %s", topic);
    else
        LOGW(TAG, "Subscription request failed: %s", topic);
}

static void printBanner() {
    Serial.println();
    Serial.println("========================================================");
    Serial.printf("  VSMART TRACKER — %s\n", BOARD.name);
    Serial.printf("  build      : %s %s\n", __DATE__, __TIME__);
    Serial.printf("  device id  : %s\n", VSMART_DEVICE_ID);
    Serial.printf("  mqtt client: %s\n", AWS_IOT_CLIENT_ID);
    Serial.printf("  endpoint   : %s:%d\n", AWS_IOT_ENDPOINT, MQTT_PORT);
    Serial.printf("  topic      : %s\n", TOPIC_PUBLISH_LOCATION);
    Serial.printf("  reset      : %d\n", (int)esp_reset_reason());
    Serial.println("--------------------------------------------------------");
    Serial.printf("  GPS  U3  RX=GPIO%-2d TX=GPIO%-2d @%lu bps\n", BOARD.gps.rx, BOARD.gps.tx,
                  (unsigned long)BOARD.gps.baud);
    Serial.println("  LTE modem / IMU: not in this build (see attic/)");
    Serial.println("--------------------------------------------------------");
    Serial.printf("  A frame is published only when sats >= %d AND hdop <= %.1f\n",
                  GPS_MIN_SATELLITES, (float)GPS_MAX_HDOP);
    Serial.println("  Weaker fixes are still printed here, just not sent.");
    Serial.println("========================================================");
    Serial.println();
}

// ── setup ───────────────────────────────────────────────────────────────────

void setup() {
    Serial.begin(SERIAL_BAUD);
    delay(500);
    printBanner();

#if ESP_IDF_VERSION_MAJOR >= 5
    esp_task_wdt_config_t wdtCfg = {
        .timeout_ms = WDT_TIMEOUT_S * 1000,
        .idle_core_mask = 0,
        .trigger_panic = true,
    };
    esp_task_wdt_reconfigure(&wdtCfg);
#else
    esp_task_wdt_init(WDT_TIMEOUT_S, true);
#endif
    esp_task_wdt_add(NULL);

    Gps.begin();
    if (!Gps.startReader()) {
        LOGE(TAG, "Cannot start GPS reader task");
        delay(1000);
        esp_restart();
        return;
    }
    Telemetry.begin();

    Cloud.onMessage(onCloudMessage);
    Cloud.begin();
    if (Cloud.ready())
        subscribeAll();

    esp_task_wdt_reset();
}

void loop() {
    esp_task_wdt_reset();

    Cloud.loop();
    if (!Cloud.ready())
        commandSubscribed = false;
    if (Cloud.ready() && (Cloud.session() != commandSession ||
                          (!commandSubscribed && millis() - lastSubscribeMs >= 5000UL)))
        subscribeAll();

    unsigned long now = millis();
    if (now - lastTickMs >= PUBLISH_TICK_MS) {
        lastTickMs = now;
        Telemetry.tick();
    }

    if (now - lastStatusMs >= STATUS_PUBLISH_MS) {
        lastStatusMs = now;

        // Same information, two destinations: the serial line for when a cable
        // is attached, and devices/<id>/status for when the device runs on
        // external power and the only way to see it is the AWS IoT console.
        Telemetry.publishHealth();

        auto gps = Gps.snapshot();
        LOGI(TAG,
             "status: mqtt=%s gps@%lu quality=%u used=%u hdop=%.2f valid=%lu bad=%lu sent=%lu "
             "lost=%lu",
             Cloud.ready() ? "up" : "down", (unsigned long)gps.baud, gps.fix.valid,
             gps.fix.satellites, gps.fix.hdop, (unsigned long)gps.passed, (unsigned long)gps.failed,
             (unsigned long)Telemetry.published(), (unsigned long)Telemetry.dropped());
        if (!gps.fix.valid && gps.lastGga[0] && now - lastGgaMs >= 30000UL) {
            lastGgaMs = now;
            Serial.printf("        raw: %s\n", gps.lastGga);
        }
    }

    delay(5);
}

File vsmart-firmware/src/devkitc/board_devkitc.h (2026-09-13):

// board_devkitc.h — Netlist record for the ESP32-DevKitC carrier, Rev C.
//
// Source of truth: vsmart-module-esp32/vsmart-module-carrier.kicad_pcb
//                  (Rev C, 2026-08-30, 105.1 × 82.1 mm, 2 layers)
//
// Net names on the schematic are **from the ESP32's point of view**:
//   GPS_TX = ESP32 transmits -> RXD of the GPS module
//   GPS_RX = ESP32 receives  <- TXD of the GPS module
// Same for SIM_TX / SIM_RX with the A7680C. Do not swap them.
//
// "U1 pin" is the pin number in the KiCad symbol; "silk" is what is printed on
// the DevKitC itself.
#pragma once
#include <Arduino.h>

namespace devkitc {

constexpr const char* NAME = "vsmart-carrier-revC (ESP32-DevKitC)";

// ── U3 · GPS NEO-7M (GY-GPSU3), UART2 ───────────────────────────────────────
// Rev C routes these as copper traces. The overrides exist only for bench
// bring-up, when the GPS is on jumper wires and you want to rule out a dead
// GPIO. Build them from platformio.ini, e.g.
//     build_flags = ${env.build_flags} -DGPS_RX_PIN=18 -DGPS_TX_PIN=19
// so the netlist record below stays true to the board.
//
// Do NOT pick GPIO1 or GPIO3. They are UART0, wired to the USB-serial bridge
// on the DevKitC module itself: the bridge and the GPS would both drive the
// same line, and flashing and the console would stop working.
// GPIO6-11 are the internal flash. GPIO12 must stay low at boot.
// Free and safe on this board: 18, 19, 23, 4, 13, 14 — plus 34/35/36/39 for RX
// only (those are input-only, which is all an RX pin has to be).
#ifndef GPS_RX_PIN
#define GPS_RX_PIN 16               // U1.27 GPIO16, silk "16"  <- U3.3 TXD  (net GPS_RX)
#endif
#ifndef GPS_TX_PIN
#define GPS_TX_PIN 17               // U1.28 GPIO17, silk "17"  -> U3.2 RXD  (net GPS_TX)
#endif
constexpr int8_t   GPS_RX   = GPS_RX_PIN;
constexpr int8_t   GPS_TX   = GPS_TX_PIN;
constexpr uint8_t  GPS_UART = 2;
// Starting point for the auto-probe in lib/Gps, not a hard setting.
// NEO-6M/7M/8M leave the factory at 9600; the M10 generation at 38400.
// Set this to whatever module is actually fitted and the probe locks on the
// first try; get it wrong and it costs 3 s per wrong candidate.
constexpr uint32_t GPS_BAUD = 9600;

// The GY-GPSU3 has no PPS pin — net GPS_PPS was dropped in Rev C, so U1.5
// (GPIO34) is unconnected and marked no-connect on the schematic.

// ── U4 · A7680C TDM2309 LTE, UART1 ──────────────────────────────────────────
constexpr int8_t   SIM_RX   = 26;   // U1.10 GPIO26, silk "26"  <- U4.11 TXD
constexpr int8_t   SIM_TX   = 27;   // U1.11 GPIO27, silk "27"  -> U4.10 RXD
constexpr int8_t   SIM_RST  = 32;   // U1.7  GPIO32, silk "32"  -> U4.9  RST (active LOW)
constexpr int8_t   SIM_DTR  = 25;   // U1.9  GPIO25, silk "25"  -> U4.2  DTR
constexpr int8_t   SIM_RI   = 33;   // U1.8  GPIO33, silk "33"  <- U4.1  RI  (active LOW)
constexpr uint8_t  SIM_UART = 1;
constexpr uint32_t SIM_BAUD = 115200;   // the A7680C autobauds; the first AT locks it in

// ── U2 · MPU6050 GY-521, I2C ────────────────────────────────────────────────
constexpr int8_t  I2C_SDA = 21;     // U1.33 GPIO21, silk "21"  <-> U2.4 SDA
constexpr int8_t  I2C_SCL = 22;     // U1.36 GPIO22, silk "22"  <-> U2.3 SCL
constexpr int8_t  MPU_INT = 35;     // U1.6  GPIO35, silk "35"  <-  U2.8 INT

// GPIO35 is INPUT-ONLY and has no internal pull resistors, so the pin must stay
// bare and the MPU6050 INT output has to be driven push-pull active-high.
constexpr uint8_t MPU_INT_PINMODE = INPUT;

// U2.7 (AD0) is tied to GND -> fixed address 0x68.
constexpr uint8_t MPU_ADDR = 0x68;

// ── Power (no firmware handles required) ────────────────────────────────────
// +5V     : J1 (5 V/1 A)   -> C3 470 µF/10 V   -> U1.19, trace 1.0 mm
// +5V_SIM : J2 (5 V/2.5 A) -> C1 1000 µF/16 V  -> U4.8,  trace 2.0 mm
// +3V3    : U1.1, output of the DevKitC's AMS1117 LDO -> U2.1 and U3.1
// Feed J1 and J2 separately: the 1.0 mm +5V trace sags under the modem's 2 A
// transmit burst if both share a terminal.

}  // namespace devkitc

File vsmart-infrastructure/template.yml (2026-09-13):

AWSTemplateFormatVersion: "2010-09-09"
Description: >
  Vsmart - Unified Infrastructure Stack
  Combines DynamoDB, SNS, AWS Location Service, AWS IoT Core, Lambda, and Cognito

Parameters:
  ProjectName:
    Type: String
    Default: Vsmart
    Description: Prefix for resource names
  Environment:
    Type: String
    Default: dev
    AllowedValues: [dev, staging, prod]
  AlertEmail:
    Type: String
    Default: admin@example.com
    Description: Email for anti-theft alerts
  MapStyle:
    Type: String
    Default: VectorEsriNavigation
  BackendWebhookUrl:
    Type: String
    Default: ""
    AllowedPattern: "^$|^https://.+$"
    ConstraintDescription: Must be empty or an HTTPS URL
    Description: Public HTTPS URL of the backend realtime webhook
Resources:
  # ─── DYNAMODB ─────────────────────────────────────────────────────────────
  DevicesTable:
    Type: AWS::DynamoDB::Table
    DeletionPolicy: Retain
    UpdateReplacePolicy: Retain
    Properties:
      TableName: !Sub "${ProjectName}-Devices"
      BillingMode: PAY_PER_REQUEST
      AttributeDefinitions:
        - AttributeName: deviceId
          AttributeType: S
        - AttributeName: ownerUserId
          AttributeType: S
        - AttributeName: antitheftEnabledStr
          AttributeType: S
      KeySchema:
        - AttributeName: deviceId
          KeyType: HASH
      GlobalSecondaryIndexes:
        - IndexName: ownerUserId-index
          KeySchema:
            - AttributeName: ownerUserId
              KeyType: HASH
          Projection:
            ProjectionType: ALL
        - IndexName: antitheftEnabledStr-index
          KeySchema:
            - AttributeName: antitheftEnabledStr
              KeyType: HASH
          Projection:
            ProjectionType: ALL
      PointInTimeRecoverySpecification:
        PointInTimeRecoveryEnabled: true
      SSESpecification:
        SSEEnabled: true

  DeviceStateTable:
    Type: AWS::DynamoDB::Table
    DeletionPolicy: Retain
    UpdateReplacePolicy: Retain
    Properties:
      TableName: !Sub "${ProjectName}-DeviceState"
      BillingMode: PAY_PER_REQUEST
      AttributeDefinitions:
        - AttributeName: deviceId
          AttributeType: S
        - AttributeName: isOnlineStr
          AttributeType: S
        - AttributeName: lastSeenAtMs
          AttributeType: N
      KeySchema:
        - AttributeName: deviceId
          KeyType: HASH
      GlobalSecondaryIndexes:
        - IndexName: isOnlineStr-lastSeenAtMs-index
          KeySchema:
            - AttributeName: isOnlineStr
              KeyType: HASH
            - AttributeName: lastSeenAtMs
              KeyType: RANGE
          Projection:
            ProjectionType: ALL
      PointInTimeRecoverySpecification:
        PointInTimeRecoveryEnabled: true
      SSESpecification:
        SSEEnabled: true

  # ─── SNS TOPICS ───────────────────────────────────────────────────────────
  AntitheftAlertTopic:
    Type: AWS::SNS::Topic
    Properties:
      TopicName: !Sub "${ProjectName}-AntitheftAlerts"
      DisplayName: "IoT Anti-theft Alert"
      KmsMasterKeyId: alias/aws/sns
      Subscription:
        - Protocol: email
          Endpoint: !Ref AlertEmail

  IoTErrorTopic:
    Type: AWS::SNS::Topic
    Properties:
      TopicName: !Sub "${ProjectName}-IoTErrors"
      DisplayName: IoT Processing Errors
      KmsMasterKeyId: alias/aws/sns

  RealtimeWebhookSecret:
    Type: AWS::SecretsManager::Secret
    DeletionPolicy: Retain
    UpdateReplacePolicy: Retain
    Properties:
      Description: !Sub "${ProjectName} Lambda-to-backend realtime webhook key"
      GenerateSecretString:
        PasswordLength: 48
        ExcludePunctuation: true

  # ─── COGNITO USER POOL (NEW FOR AUTH) ─────────────────────────────────────
  UserPool:
    Type: AWS::Cognito::UserPool
    DeletionPolicy: Retain
    UpdateReplacePolicy: Retain
    Properties:
      UserPoolName: !Sub "${ProjectName}-UserPool"
      UsernameAttributes: [email]
      AutoVerifiedAttributes: [email]
      AccountRecoverySetting:
        RecoveryMechanisms:
          - Name: verified_email
            Priority: 1
      Policies:
        PasswordPolicy:
          MinimumLength: 12
          RequireLowercase: true
          RequireNumbers: true
          RequireSymbols: true
          RequireUppercase: true
          TemporaryPasswordValidityDays: 7

  UserPoolClient:
    Type: AWS::Cognito::UserPoolClient
    Properties:
      UserPoolId: !Ref UserPool
      ClientName: !Sub "${ProjectName}-WebClient"
      GenerateSecret: false
      EnableTokenRevocation: true
      PreventUserExistenceErrors: ENABLED
      ExplicitAuthFlows:
        - ALLOW_ADMIN_USER_PASSWORD_AUTH
        - ALLOW_USER_SRP_AUTH
        - ALLOW_REFRESH_TOKEN_AUTH
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

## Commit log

2026-08-30 chore: publish VSmart research system monorepo
    [TDM-4G-V1-3D.STEP, blank.kicad_sch, canonical_schematic.kicad_sch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]
2026-08-30 chore: rebrand monorepo to Vsmart
    Rename component directories tracking-data-streaming-* -> vsmart-*,
    vsmart-app -> vsmart-mobile, vsmart-iot -> vsmart-firmware, osrm ->
    vsmart-osrm. Unify naming (TrackingDATN / VSmart -> Vsmart) across code,
    infra templates, docs and scripts. KiCad design files and vendored
    third-party trees left untouched.
2026-09-13 chore: sync full workspace source into monorepo
    Push current state of all first-party Vsmart components (backend, web,
    web mobile, infrastructure, firmware, hardware, osrm, module variants)
    directly from the DATN working tree, which is now the root of this repo.
    Excluded: DRC/audit/build reports, auto-generated PCB snapshots, OSRM map
    data, dependencies (node_modules/.venv/Pods/.pio), device secrets/certs,
    .env files, local agent tooling, and vendored third-party reference repos
    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
    [TDM-4G-V1-3D.STEP, blank.kicad_sch, canonical_schematic.kicad_sch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]
2026-09-13 chore: drop pcb-debug-2026-09-09 and pcb-fix-2026-09-09 scratch dirs
    Ad-hoc debugging/fix session dumps, not meant to be published; gitignored
    going forward. Local files on disk are left untouched.
    [vsmart-module-carrier-B_Cu.gbl, vsmart-module-carrier-B_Mask.gbs, vsmart-module-carrier-B_Silkscreen.gbo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]
